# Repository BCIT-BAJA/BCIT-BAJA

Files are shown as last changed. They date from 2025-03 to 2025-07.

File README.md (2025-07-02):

# Problem 
During the last BAJA competition,The BAJA team was unable to measure dynamic forces applied onto the suspension of the car. As a result, during the last competition, it bent.
ezgif-3c4af8c38ad79b

The telemetry system for BCIT-BAJA car, collects strain across suspension components of car to allow BAJA to optimize material and reinforce weak areas of suspension.
As well as collect other data such as linear/angular acceleration.

There consists of 2 parts of this project. 

**PART B** the amplification of the (-15-15mV) analog strain signal to (0-3.0V) which is then routed to

**PART A**, which collects the 8 conditioned analog signals and is transmitted/received over a 900MHz antenna

# MAINBOARD( PART A)






# Amplifier circuit ( PART B) - 


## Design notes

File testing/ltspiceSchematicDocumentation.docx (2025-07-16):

# Power supply measurement

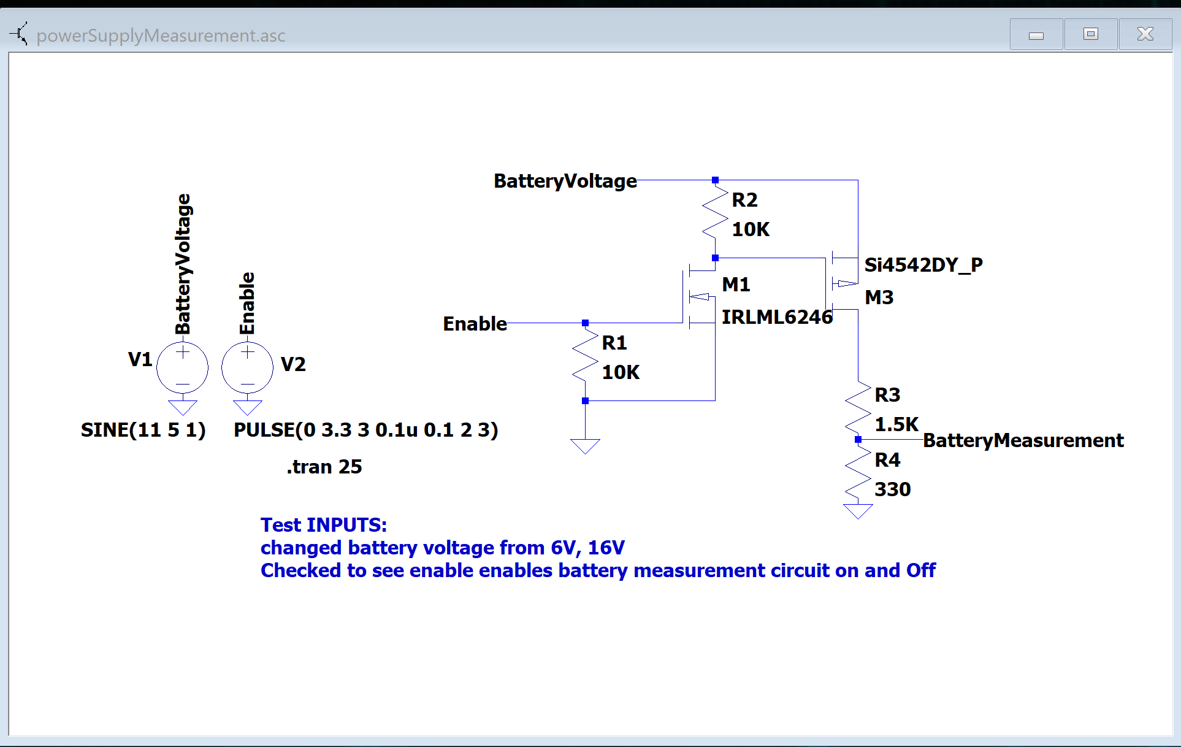
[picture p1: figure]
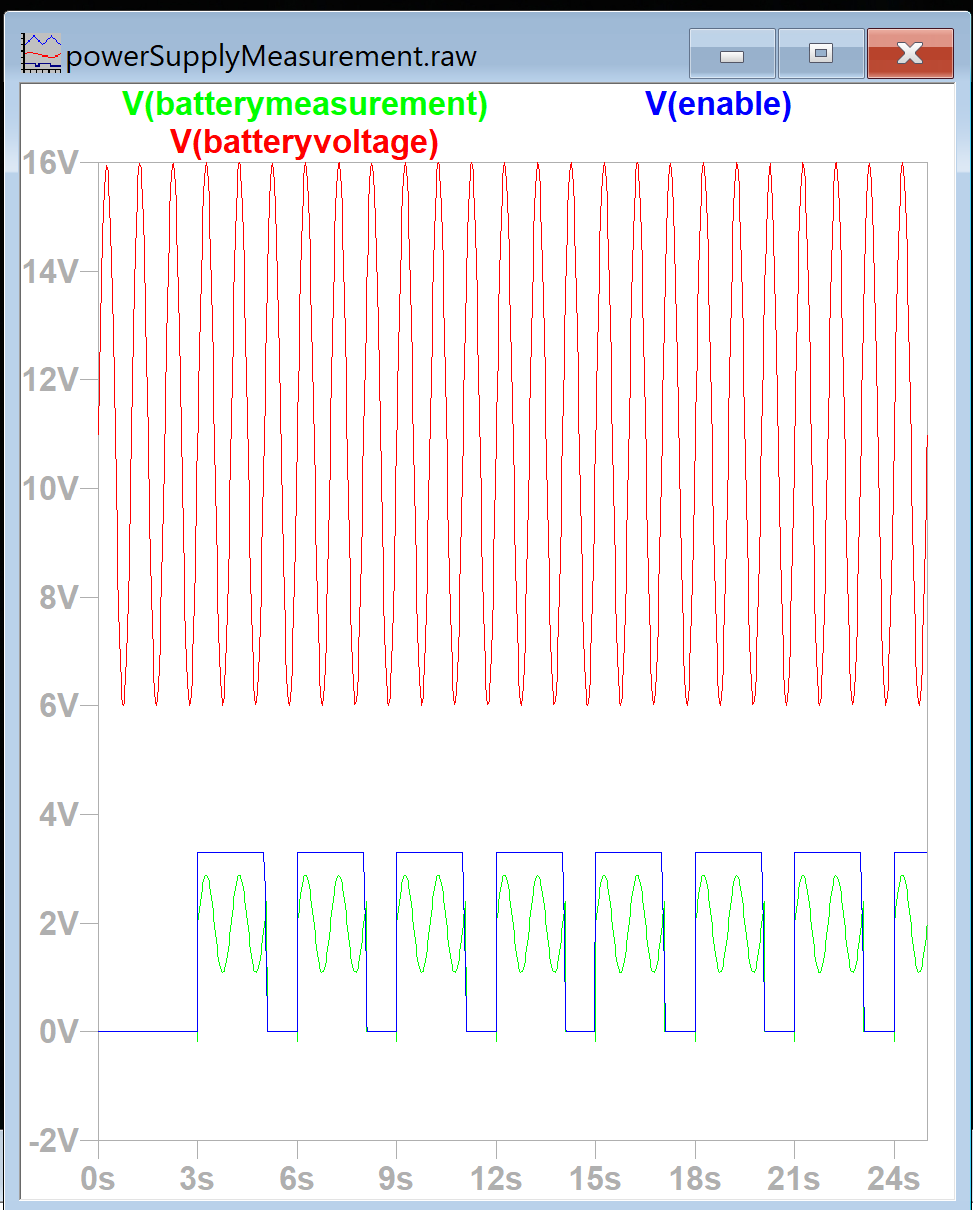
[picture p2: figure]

# StrainGAUGE switching – to be discussed about

HIGH C -> LOW EMI, HIGH CURRENT DRAW, DECREASES ACCURACY

CURRENT LIMITING RESISTER -> LOWERS CURRENT, DECREASES ACCURACY

NO C -> HIGHEST EMI, HIGHEST ACCURACY, lowest current draw.

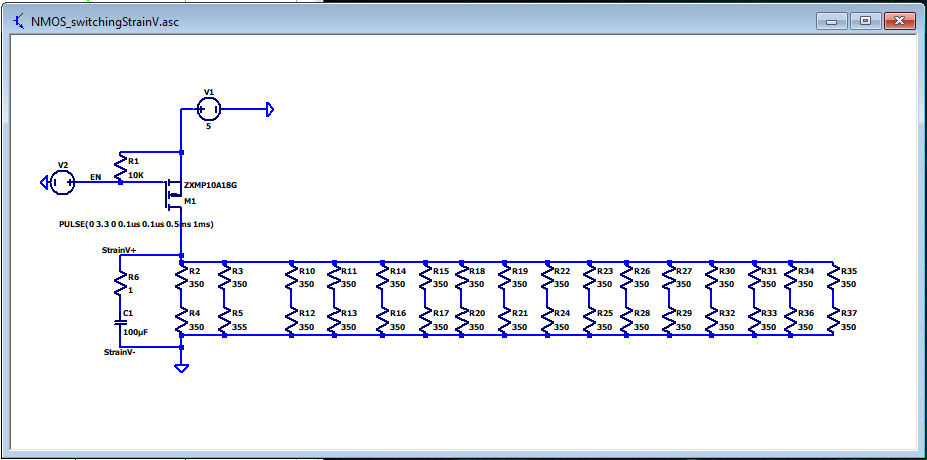
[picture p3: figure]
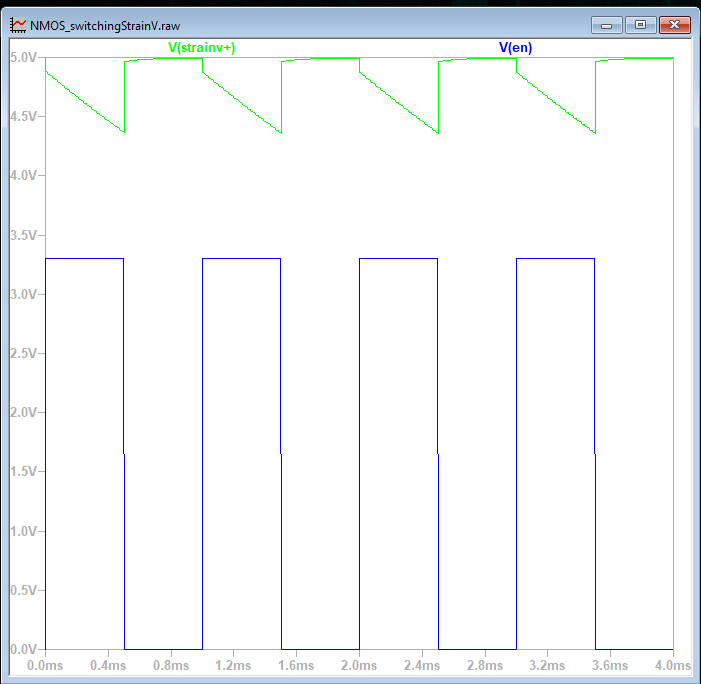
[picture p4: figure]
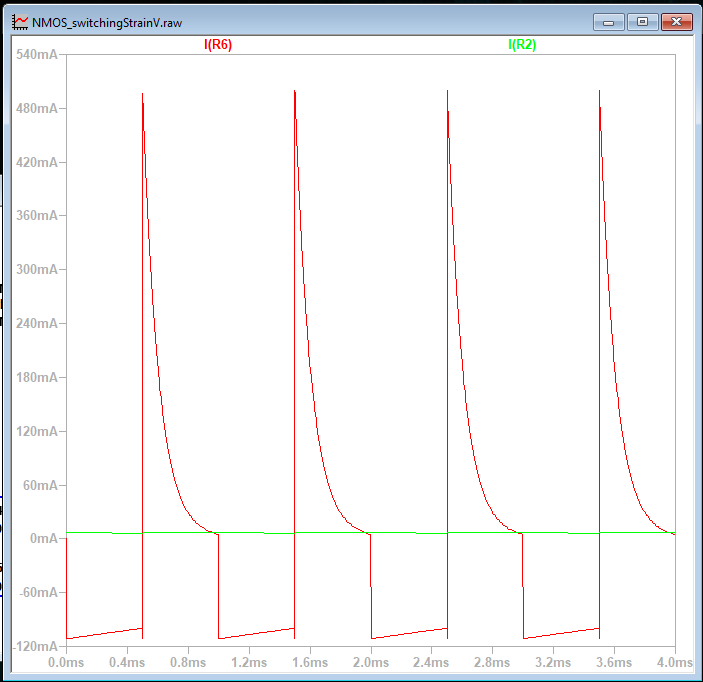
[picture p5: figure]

Figure 1 Current limiting resistor = 1 Ohm, bypass 100uF

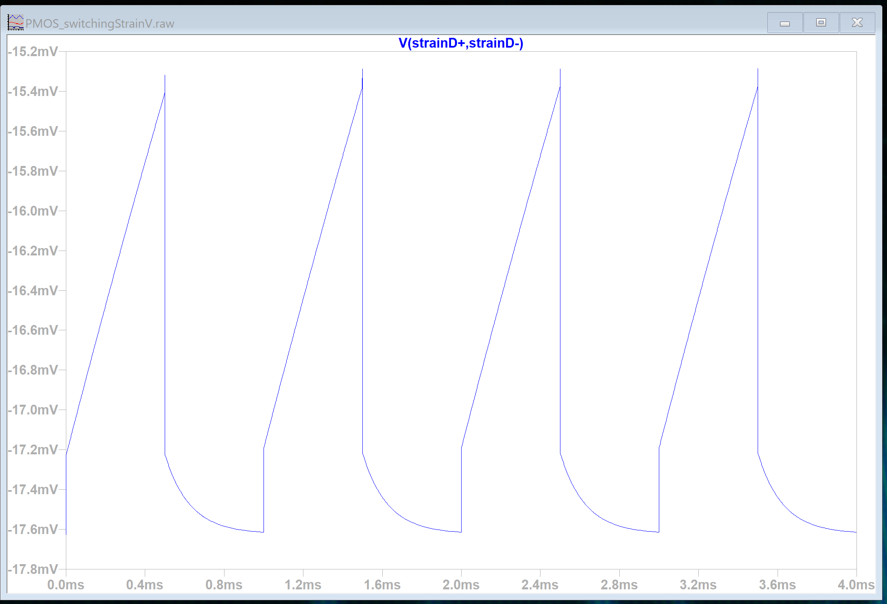
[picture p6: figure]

Figure 2 R =1, C=100uF

# Strain gauge Amplifier

Could not trigger undervoltage conditions on stimulation due to OP-AMP reaching saturation at about 500mV. The stimulated diodes are specced out for worst case condition. Triggering at -182mV, overall, the diodes still protect the ADC at worst-case scenario however could not be properly integrated into the stimulation.

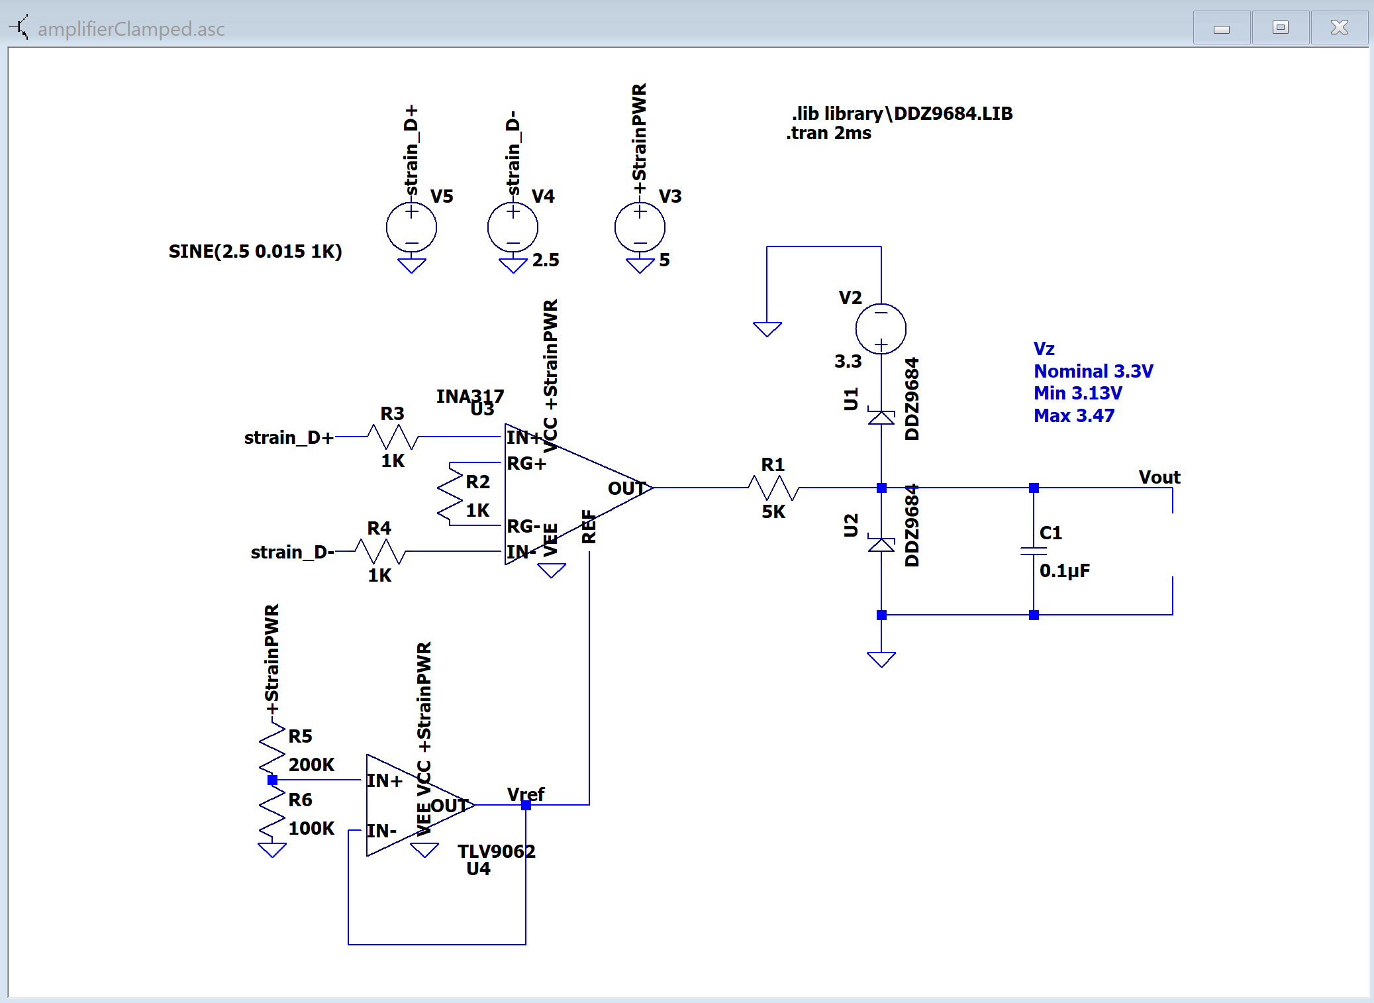
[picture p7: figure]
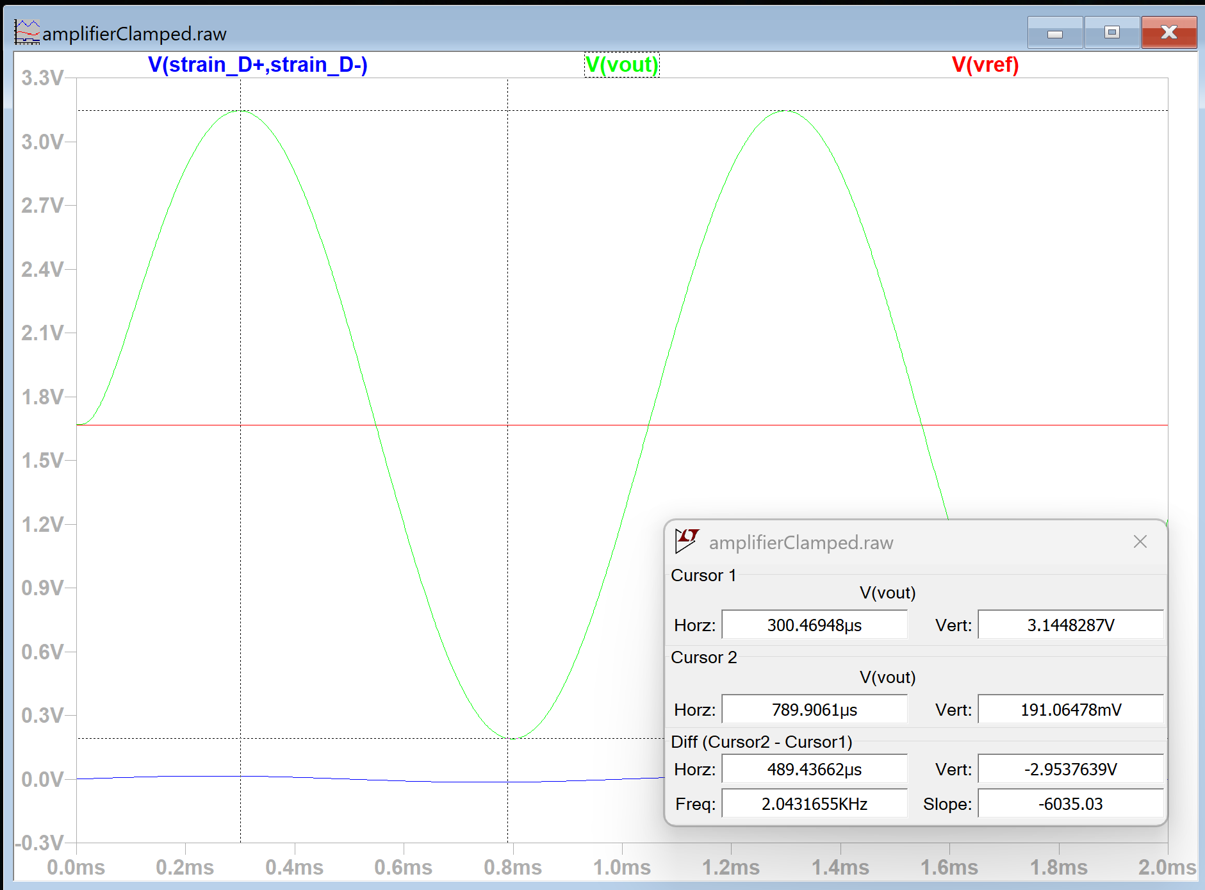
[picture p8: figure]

Diode clamping circuit (*Note, reverse voltage can vary quite a bit as seen by Vz on circuit)

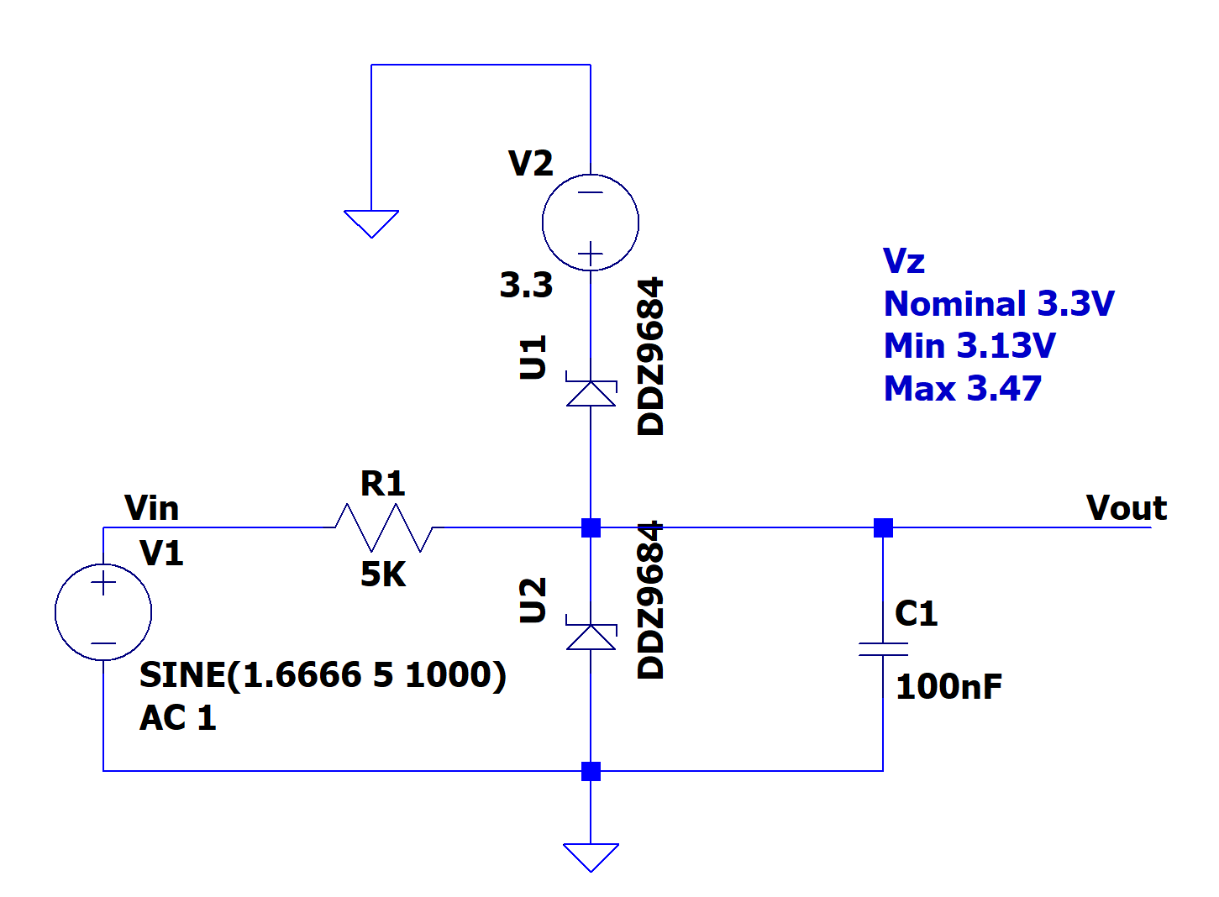
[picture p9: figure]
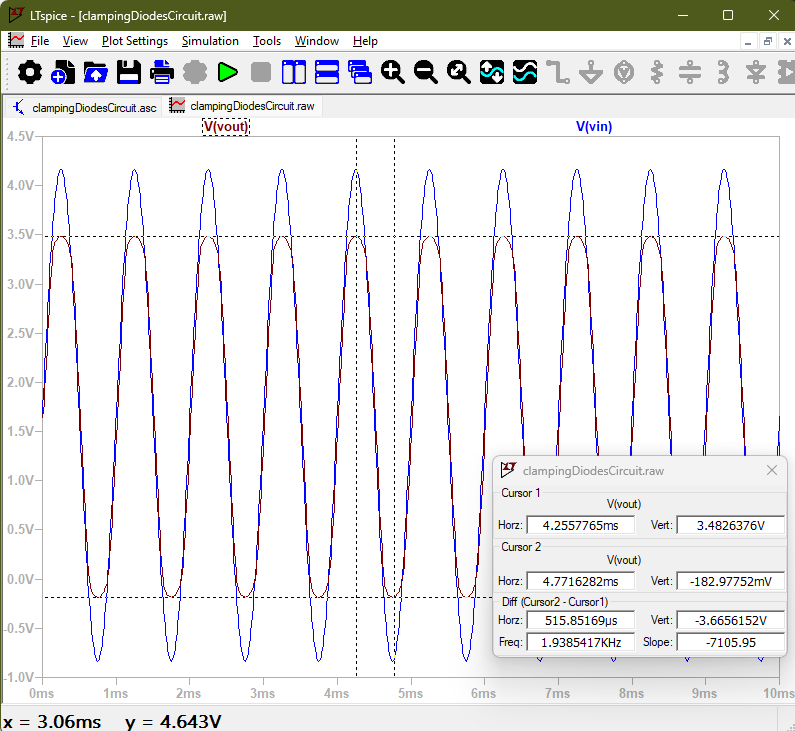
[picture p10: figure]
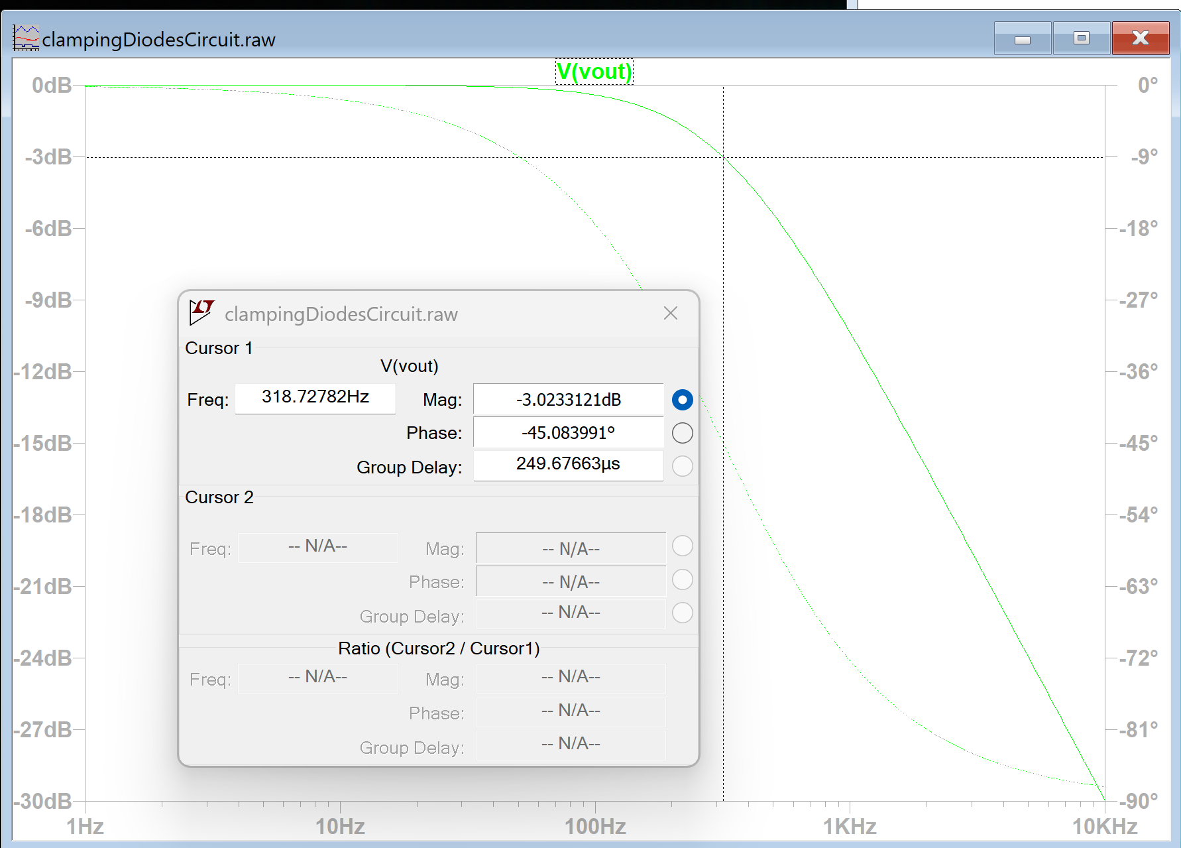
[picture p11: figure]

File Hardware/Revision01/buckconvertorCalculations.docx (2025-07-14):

Specifications

1. Verification of PINOUT

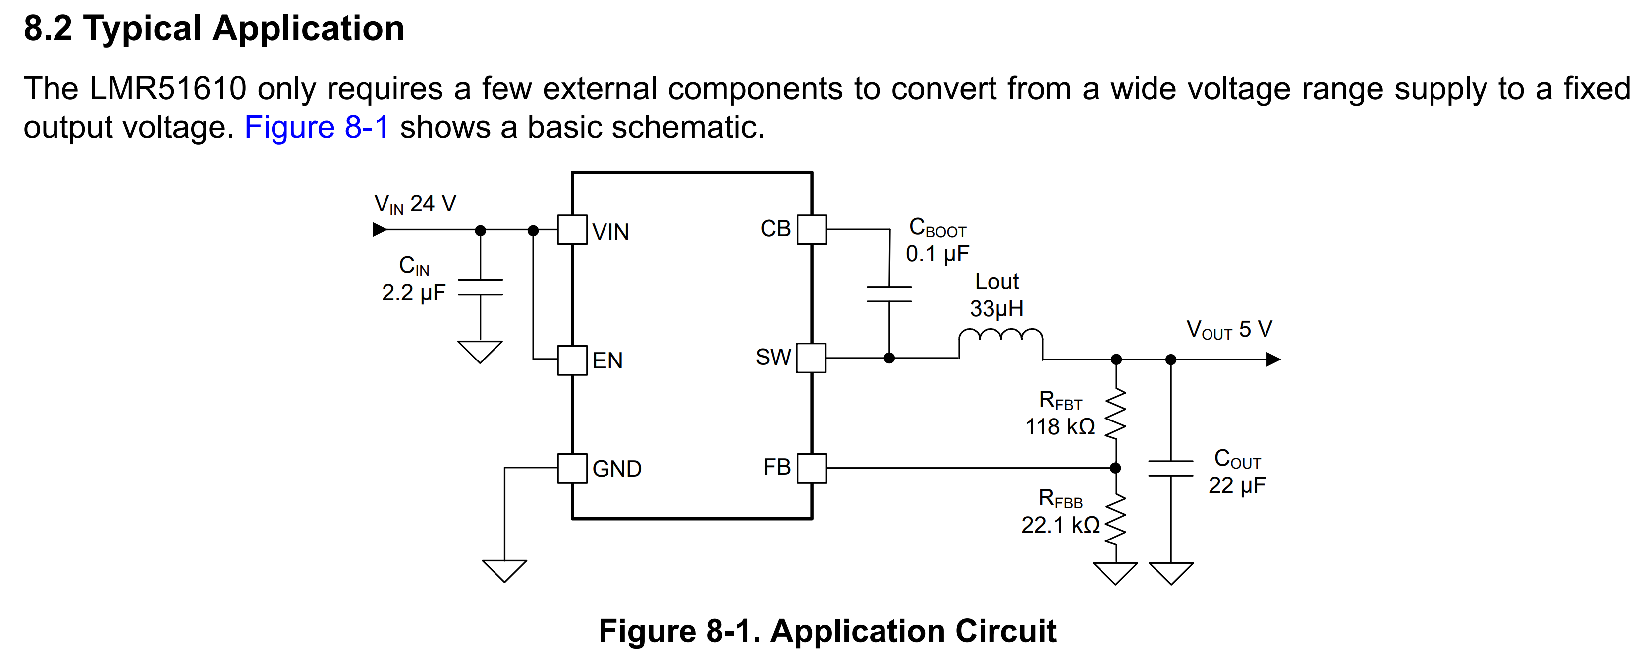
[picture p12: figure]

Design parameters

Parameter | Value
V_(in) | 4.5-16V - Not sure why (8.8V - 15.2V) is on schematic
V_(out) | 7V – must be above 6.5V
i_(out_max) | 250mA – (assuming MOSFET is not switched at 1KHz)
Output overshoot, undershoot | ±5%
Output voltage ripple | ±5%
Operating frequency | 400KHz

2. How do you set the output voltage? (PRIORITY HIGH)

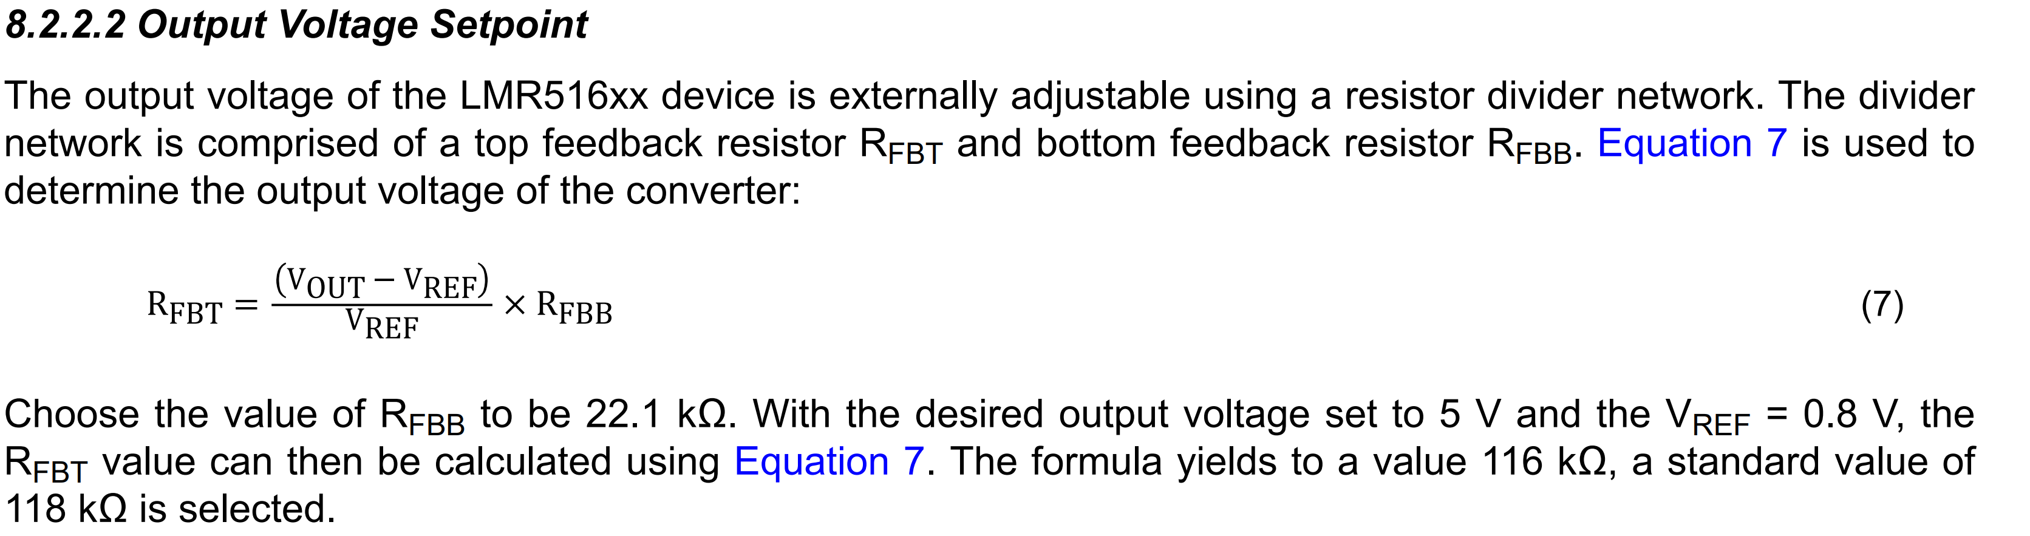
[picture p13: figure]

Defining variables

Choose V_(out) = 7V (Ensure V_(out) is above 6.5V for stable operation of LDO)

V_(ref) = 0.8V (Const)

R_(fbb) = 10K (Randomly chosen)

Plugging that into eq we get

R_(fbt) = (V_(out) - V_(ref) )*(R_(fbb))/(V_(ref))= 77.5K ~= 76.8K

3. How to choose output inductor (PRIORITY MEDIUM)

Overall, I chose parameters that limited EMI, at the cost of being less energy efficient.

K_(IND) is a coefficient that represents the amount of inductor ripple current relative to the maximum output current of the device. K_(IND) must be 0.2-0.6 of maximum IOUT supported by converter.

K_(chosen) = 0.2 – lowest EMI, least energy efficient

f_(sw) =400KHz - lower switching frequency variant chosen for less EMI

V_(in_max) =16V - not sure why 15.2V was chosen

V_(out) =7V±0.5V

I_(out_fla) ~=250mA

Plugging the old parameters in we get

Figure 1 Formula used for inductance

L_(min) =197μH

We chose L =150μH giving us K = 0.26

Now we can calculate the ripple across the input of the inductor using

Figure 2 ripple current(PG 19 datasheet)

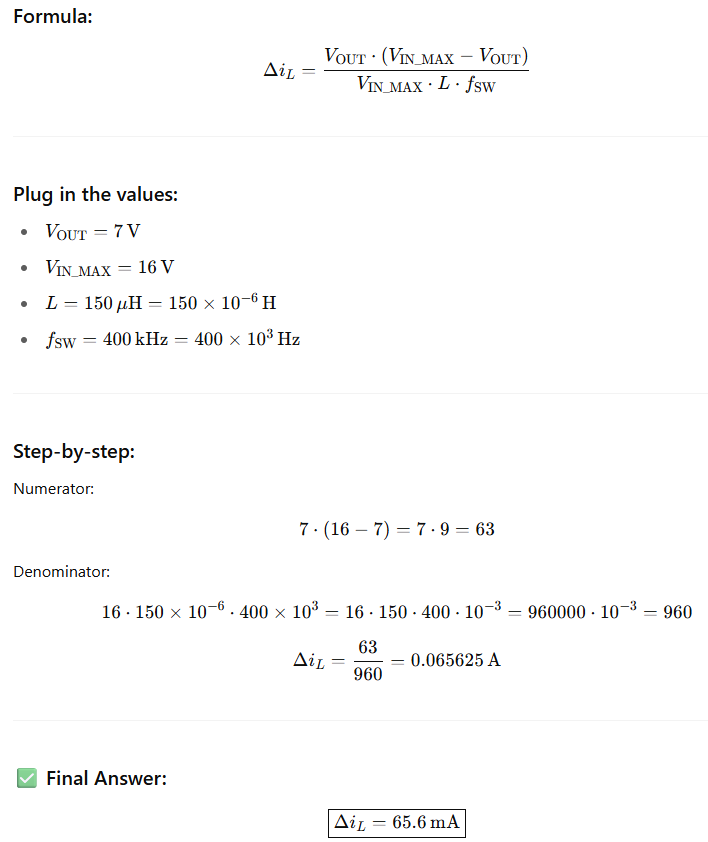
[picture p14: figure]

Note* This inductor has been routed away from analog signals to reduce EMI.

4. Choosing Input capacitors (PRIORITY: LOW)

Followed recommendation using 1uF

5. Choosing output capacitor( PRIORITY: LOWish)

Target ripple is 0.35V

ESR ~= 10m Ω @300KHz

ΔV_(out_esr) =0.66mV

ΔV_(out) _c = 0.93mV

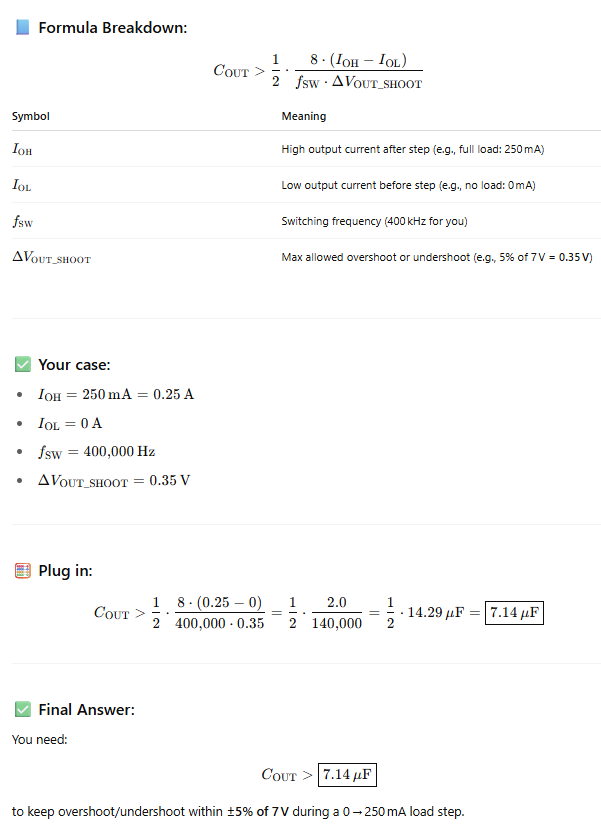
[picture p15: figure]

I will have 10uF + 1uF

This one may be better as all wiring has already been created.

Export TPS54202DDCR - 8.5V-16V to 7.00V @ 0.3A

https://webench.ti.com/power-designer/switching-regulator/select

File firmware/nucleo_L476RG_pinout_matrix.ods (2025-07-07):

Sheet: tabula-stm32l476rg(2)
AF15 | Pin | Additional Functions | AF0 | AF1 | AF2 | AF3 | AF4 | AF5 | AF6 | AF7 | AF8 | AF9 | AF10 | AF11 | AF12 | AF13 | AF14 | Pin | Additional Functions | AF0 | AF1 | AF2 | AF3 | AF4 | AF5 | AF6 | AF7 | AF8 | AF9 | AF10 | AF11 | AF12 | AF13 | AF14 | 0
EVENTOUT | PA0 | OPAMP1_VINP/ADC12_IN5/RTC_TAMP2/WKUP1 |  | TIM2_CH1 | TIM5_CH1 | TIM8_ETR |  |  |  | USART2_CTS | UART4_TX |  |  |  |  | SAI1_EXTCLK | TIM2_ETR | PA0 | PA0/OPAMP1_VINP/ADC12_IN5/RTC_TAMP2/WKUP1 | PA0/OPAMP1_VINP/ADC12_IN5/RTC_TAMP2/WKUP1 | PA0/OPAMP1_VINP/ADC12_IN5/RTC_TAMP2/WKUP1/TIM2_CH1 | PA0/OPAMP1_VINP/ADC12_IN5/RTC_TAMP2/WKUP1/TIM2_CH1/TIM5_CH1 | PA0/OPAMP1_VINP/ADC12_IN5/RTC_TAMP2/WKUP1/TIM2_CH1/TIM5_CH1/TIM8_ETR | PA0/OPAMP1_VINP/ADC12_IN5/RTC_TAMP2/WKUP1/TIM2_CH1/TIM5_CH1/TIM8_ETR | PA0/OPAMP1_VINP/ADC12_IN5/RTC_TAMP2/WKUP1/TIM2_CH1/TIM5_CH1/TIM8_ETR | PA0/OPAMP1_VINP/ADC12_IN5/RTC_TAMP2/WKUP1/TIM2_CH1/TIM5_CH1/TIM8_ETR | PA0/OPAMP1_VINP/ADC12_IN5/RTC_TAMP2/WKUP1/TIM2_CH1/TIM5_CH1/TIM8_ETR/USART2_CTS | PA0/OPAMP1_VINP/ADC12_IN5/RTC_TAMP2/WKUP1/TIM2_CH1/TIM5_CH1/TIM8_ETR/USART2_CTS/UART4_TX | PA0/OPAMP1_VINP/ADC12_IN5/RTC_TAMP2/WKUP1/TIM2_CH1/TIM5_CH1/TIM8_ETR/USART2_CTS/UART4_TX | PA0/OPAMP1_VINP/ADC12_IN5/RTC_TAMP2/WKUP1/TIM2_CH1/TIM5_CH1/TIM8_ETR/USART2_CTS/UART4_TX | PA0/OPAMP1_VINP/ADC12_IN5/RTC_TAMP2/WKUP1/TIM2_CH1/TIM5_CH1/TIM8_ETR/USART2_CTS/UART4_TX | PA0/OPAMP1_VINP/ADC12_IN5/RTC_TAMP2/WKUP1/TIM2_CH1/TIM5_CH1/TIM8_ETR/USART2_CTS/UART4_TX | PA0/OPAMP1_VINP/ADC12_IN5/RTC_TAMP2/WKUP1/TIM2_CH1/TIM5_CH1/TIM8_ETR/USART2_CTS/UART4_TX/SAI1_EXTCLK | PA0/OPAMP1_VINP/ADC12_IN5/RTC_TAMP2/WKUP1/TIM2_CH1/TIM5_CH1/TIM8_ETR/USART2_CTS/UART4_TX/SAI1_EXTCLK/TIM2_ETR | PA0/OPAMP1_VINP/ADC12_IN5/RTC_TAMP2/WKUP1/TIM2_CH1/TIM5_CH1/TIM8_ETR/USART2_CTS/UART4_TX/SAI1_EXTCLK/TIM2_ETR
EVENTOUT | PA1 | OPAMP1_VINM/ADC12_IN6 |  | TIM2_CH2 | TIM5_CH2 |  |  |  |  | USART2_RTS_DE | UART4_RX |  |  | LCD_SEG0 |  |  | TIM15_CH1N | PA1 | PA1/OPAMP1_VINM/ADC12_IN6 | PA1/OPAMP1_VINM/ADC12_IN6 | PA1/OPAMP1_VINM/ADC12_IN6/TIM2_CH2 | PA1/OPAMP1_VINM/ADC12_IN6/TIM2_CH2/TIM5_CH2 | PA1/OPAMP1_VINM/ADC12_IN6/TIM2_CH2/TIM5_CH2 | PA1/OPAMP1_VINM/ADC12_IN6/TIM2_CH2/TIM5_CH2 | PA1/OPAMP1_VINM/ADC12_IN6/TIM2_CH2/TIM5_CH2 | PA1/OPAMP1_VINM/ADC12_IN6/TIM2_CH2/TIM5_CH2 | PA1/OPAMP1_VINM/ADC12_IN6/TIM2_CH2/TIM5_CH2/USART2_RTS_DE | PA1/OPAMP1_VINM/ADC12_IN6/TIM2_CH2/TIM5_CH2/USART2_RTS_DE/UART4_RX | PA1/OPAMP1_VINM/ADC12_IN6/TIM2_CH2/TIM5_CH2/USART2_RTS_DE/UART4_RX | PA1/OPAMP1_VINM/ADC12_IN6/TIM2_CH2/TIM5_CH2/USART2_RTS_DE/UART4_RX | PA1/OPAMP1_VINM/ADC12_IN6/TIM2_CH2/TIM5_CH2/USART2_RTS_DE/UART4_RX/LCD_SEG0 | PA1/OPAMP1_VINM/ADC12_IN6/TIM2_CH2/TIM5_CH2/USART2_RTS_DE/UART4_RX/LCD_SEG0 | PA1/OPAMP1_VINM/ADC12_IN6/TIM2_CH2/TIM5_CH2/USART2_RTS_DE/UART4_RX/LCD_SEG0 | PA1/OPAMP1_VINM/ADC12_IN6/TIM2_CH2/TIM5_CH2/USART2_RTS_DE/UART4_RX/LCD_SEG0/TIM15_CH1N | PA1/OPAMP1_VINM/ADC12_IN6/TIM2_CH2/TIM5_CH2/USART2_RTS_DE/UART4_RX/LCD_SEG0/TIM15_CH1N
EVENTOUT | PA2 | ADC12_IN7/WKUP4/LSCO |  | TIM2_CH3 | TIM5_CH3 |  |  |  |  | USART2_TX |  |  |  | LCD_SEG1 |  | SAI2_EXTCLK | TIM15_CH1 | PA2 | PA2/ADC12_IN7/WKUP4/LSCO | PA2/ADC12_IN7/WKUP4/LSCO | PA2/ADC12_IN7/WKUP4/LSCO/TIM2_CH3 | PA2/ADC12_IN7/WKUP4/LSCO/TIM2_CH3/TIM5_CH3 | PA2/ADC12_IN7/WKUP4/LSCO/TIM2_CH3/TIM5_CH3 | PA2/ADC12_IN7/WKUP4/LSCO/TIM2_CH3/TIM5_CH3 | PA2/ADC12_IN7/WKUP4/LSCO/TIM2_CH3/TIM5_CH3 | PA2/ADC12_IN7/WKUP4/LSCO/TIM2_CH3/TIM5_CH3 | PA2/ADC12_IN7/WKUP4/LSCO/TIM2_CH3/TIM5_CH3/USART2_TX | PA2/ADC12_IN7/WKUP4/LSCO/TIM2_CH3/TIM5_CH3/USART2_TX | PA2/ADC12_IN7/WKUP4/LSCO/TIM2_CH3/TIM5_CH3/USART2_TX | PA2/ADC12_IN7/WKUP4/LSCO/TIM2_CH3/TIM5_CH3/USART2_TX | PA2/ADC12_IN7/WKUP4/LSCO/TIM2_CH3/TIM5_CH3/USART2_TX/LCD_SEG1 | PA2/ADC12_IN7/WKUP4/LSCO/TIM2_CH3/TIM5_CH3/USART2_TX/LCD_SEG1 | PA2/ADC12_IN7/WKUP4/LSCO/TIM2_CH3/TIM5_CH3/USART2_TX/LCD_SEG1/SAI2_EXTCLK | PA2/ADC12_IN7/WKUP4/LSCO/TIM2_CH3/TIM5_CH3/USART2_TX/LCD_SEG1/SAI2_EXTCLK/TIM15_CH1 | PA2/ADC12_IN7/WKUP4/LSCO/TIM2_CH3/TIM5_CH3/USART2_TX/LCD_SEG1/SAI2_EXTCLK/TIM15_CH1
EVENTOUT | PA3 | OPAMP1_VOUT/ADC12_IN8 |  | TIM2_CH4 | TIM5_CH4 |  |  |  |  | USART2_RX |  |  |  | LCD_SEG2 |  |  | TIM15_CH2 | PA3 | PA3/OPAMP1_VOUT/ADC12_IN8 | PA3/OPAMP1_VOUT/ADC12_IN8 | PA3/OPAMP1_VOUT/ADC12_IN8/TIM2_CH4 | PA3/OPAMP1_VOUT/ADC12_IN8/TIM2_CH4/TIM5_CH4 | PA3/OPAMP1_VOUT/ADC12_IN8/TIM2_CH4/TIM5_CH4 | PA3/OPAMP1_VOUT/ADC12_IN8/TIM2_CH4/TIM5_CH4 | PA3/OPAMP1_VOUT/ADC12_IN8/TIM2_CH4/TIM5_CH4 | PA3/OPAMP1_VOUT/ADC12_IN8/TIM2_CH4/TIM5_CH4 | PA3/OPAMP1_VOUT/ADC12_IN8/TIM2_CH4/TIM5_CH4/USART2_RX | PA3/OPAMP1_VOUT/ADC12_IN8/TIM2_CH4/TIM5_CH4/USART2_RX | PA3/OPAMP1_VOUT/ADC12_IN8/TIM2_CH4/TIM5_CH4/USART2_RX | PA3/OPAMP1_VOUT/ADC12_IN8/TIM2_CH4/TIM5_CH4/USART2_RX | PA3/OPAMP1_VOUT/ADC12_IN8/TIM2_CH4/TIM5_CH4/USART2_RX/LCD_SEG2 | PA3/OPAMP1_VOUT/ADC12_IN8/TIM2_CH4/TIM5_CH4/USART2_RX/LCD_SEG2 | PA3/OPAMP1_VOUT/ADC12_IN8/TIM2_CH4/TIM5_CH4/USART2_RX/LCD_SEG2 | PA3/OPAMP1_VOUT/ADC12_IN8/TIM2_CH4/TIM5_CH4/USART2_RX/LCD_SEG2/TIM15_CH2 | PA3/OPAMP1_VOUT/ADC12_IN8/TIM2_CH4/TIM5_CH4/USART2_RX/LCD_SEG2/TIM15_CH2
EVENTOUT | PA4 | ADC12_IN9/DAC1_OUT1 |  |  |  |  |  | SPI1_NSS | SPI3_NSS | USART2_CK |  |  |  |  |  | SAI1_FS_B | LPTIM2_OUT | PA4 | PA4/ADC12_IN9/DAC1_OUT1 | PA4/ADC12_IN9/DAC1_OUT1 | PA4/ADC12_IN9/DAC1_OUT1 | PA4/ADC12_IN9/DAC1_OUT1 | PA4/ADC12_IN9/DAC1_OUT1 | PA4/ADC12_IN9/DAC1_OUT1 | PA4/ADC12_IN9/DAC1_OUT1/SPI1_NSS | PA4/ADC12_IN9/DAC1_OUT1/SPI1_NSS/SPI3_NSS | PA4/ADC12_IN9/DAC1_OUT1/SPI1_NSS/SPI3_NSS/USART2_CK | PA4/ADC12_IN9/DAC1_OUT1/SPI1_NSS/SPI3_NSS/USART2_CK | PA4/ADC12_IN9/DAC1_OUT1/SPI1_NSS/SPI3_NSS/USART2_CK | PA4/ADC12_IN9/DAC1_OUT1/SPI1_NSS/SPI3_NSS/USART2_CK | PA4/ADC12_IN9/DAC1_OUT1/SPI1_NSS/SPI3_NSS/USART2_CK | PA4/ADC12_IN9/DAC1_OUT1/SPI1_NSS/SPI3_NSS/USART2_CK | PA4/ADC12_IN9/DAC1_OUT1/SPI1_NSS/SPI3_NSS/USART2_CK/SAI1_FS_B | PA4/ADC12_IN9/DAC1_OUT1/SPI1_NSS/SPI3_NSS/USART2_CK/SAI1_FS_B/LPTIM2_OUT | PA4/ADC12_IN9/DAC1_OUT1/SPI1_NSS/SPI3_NSS/USART2_CK/SAI1_FS_B/LPTIM2_OUT
EVENTOUT | PA5 | ADC12_IN10/DAC1_OUT2 |  | TIM2_CH1 | TIM2_ETR | TIM8_CH1N |  | SPI1_SCK |  |  |  |  |  |  |  |  | LPTIM2_ETR | PA5 | PA5/ADC12_IN10/DAC1_OUT2 | PA5/ADC12_IN10/DAC1_OUT2 | PA5/ADC12_IN10/DAC1_OUT2/TIM2_CH1 | PA5/ADC12_IN10/DAC1_OUT2/TIM2_CH1/TIM2_ETR | PA5/ADC12_IN10/DAC1_OUT2/TIM2_CH1/TIM2_ETR/TIM8_CH1N | PA5/ADC12_IN10/DAC1_OUT2/TIM2_CH1/TIM2_ETR/TIM8_CH1N | PA5/ADC12_IN10/DAC1_OUT2/TIM2_CH1/TIM2_ETR/TIM8_CH1N/SPI1_SCK | PA5/ADC12_IN10/DAC1_OUT2/TIM2_CH1/TIM2_ETR/TIM8_CH1N/SPI1_SCK | PA5/ADC12_IN10/DAC1_OUT2/TIM2_CH1/TIM2_ETR/TIM8_CH1N/SPI1_SCK | PA5/ADC12_IN10/DAC1_OUT2/TIM2_CH1/TIM2_ETR/TIM8_CH1N/SPI1_SCK | PA5/ADC12_IN10/DAC1_OUT2/TIM2_CH1/TIM2_ETR/TIM8_CH1N/SPI1_SCK | PA5/ADC12_IN10/DAC1_OUT2/TIM2_CH1/TIM2_ETR/TIM8_CH1N/SPI1_SCK | PA5/ADC12_IN10/DAC1_OUT2/TIM2_CH1/TIM2_ETR/TIM8_CH1N/SPI1_SCK | PA5/ADC12_IN10/DAC1_OUT2/TIM2_CH1/TIM2_ETR/TIM8_CH1N/SPI1_SCK | PA5/ADC12_IN10/DAC1_OUT2/TIM2_CH1/TIM2_ETR/TIM8_CH1N/SPI1_SCK | PA5/ADC12_IN10/DAC1_OUT2/TIM2_CH1/TIM2_ETR/TIM8_CH1N/SPI1_SCK/LPTIM2_ETR | PA5/ADC12_IN10/DAC1_OUT2/TIM2_CH1/TIM2_ETR/TIM8_CH1N/SPI1_SCK/LPTIM2_ETR
EVENTOUT | PA6 | OPAMP2_VINP/ADC12_IN11 |  | TIM1_BKIN | TIM3_CH1 | TIM8_BKIN |  | SPI1_MISO |  | USART3_CTS |  |  | QUADSPI_BK1_IO3 | LCD_SEG3 | TIM1_BKIN_COMP2 | TIM8_BKIN_COMP2 | TIM16_CH1 | PA6 | PA6/OPAMP2_VINP/ADC12_IN11 | PA6/OPAMP2_VINP/ADC12_IN11 | PA6/OPAMP2_VINP/ADC12_IN11/TIM1_BKIN | PA6/OPAMP2_VINP/ADC12_IN11/TIM1_BKIN/TIM3_CH1 | PA6/OPAMP2_VINP/ADC12_IN11/TIM1_BKIN/TIM3_CH1/TIM8_BKIN | PA6/OPAMP2_VINP/ADC12_IN11/TIM1_BKIN/TIM3_CH1/TIM8_BKIN | PA6/OPAMP2_VINP/ADC12_IN11/TIM1_BKIN/TIM3_CH1/TIM8_BKIN/SPI1_MISO | PA6/OPAMP2_VINP/ADC12_IN11/TIM1_BKIN/TIM3_CH1/TIM8_BKIN/SPI1_MISO | PA6/OPAMP2_VINP/ADC12_IN11/TIM1_BKIN/TIM3_CH1/TIM8_BKIN/SPI1_MISO/USART3_CTS | PA6/OPAMP2_VINP/ADC12_IN11/TIM1_BKIN/TIM3_CH1/TIM8_BKIN/SPI1_MISO/USART3_CTS | PA6/OPAMP2_VINP/ADC12_IN11/TIM1_BKIN/TIM3_CH1/TIM8_BKIN/SPI1_MISO/USART3_CTS | PA6/OPAMP2_VINP/ADC12_IN11/TIM1_BKIN/TIM3_CH1/TIM8_BKIN/SPI1_MISO/USART3_CTS/QUADSPI_BK1_IO3 | PA6/OPAMP2_VINP/ADC12_IN11/TIM1_BKIN/TIM3_CH1/TIM8_BKIN/SPI1_MISO/USART3_CTS/QUADSPI_BK1_IO3/LCD_SEG3 | PA6/OPAMP2_VINP/ADC12_IN11/TIM1_BKIN/TIM3_CH1/TIM8_BKIN/SPI1_MISO/USART3_CTS/QUADSPI_BK1_IO3/LCD_SEG3/TIM1_BKIN_COMP2 | PA6/OPAMP2_VINP/ADC12_IN11/TIM1_BKIN/TIM3_CH1/TIM8_BKIN/SPI1_MISO/USART3_CTS/QUADSPI_BK1_IO3/LCD_SEG3/TIM1_BKIN_COMP2/TIM8_BKIN_COMP2 | PA6/OPAMP2_VINP/ADC12_IN11/TIM1_BKIN/TIM3_CH1/TIM8_BKIN/SPI1_MISO/USART3_CTS/QUADSPI_BK1_IO3/LCD_SEG3/TIM1_BKIN_COMP2/TIM8_BKIN_COMP2/TIM16_CH1 | PA6/OPAMP2_VINP/ADC12_IN11/TIM1_BKIN/TIM3_CH1/TIM8_BKIN/SPI1_MISO/USART3_CTS/QUADSPI_BK1_IO3/LCD_SEG3/TIM1_BKIN_COMP2/TIM8_BKIN_COMP2/TIM16_CH1
EVENTOUT | PA7 | OPAMP2_VINM/ADC12_IN12 |  | TIM1_CH1N | TIM3_CH2 | TIM8_CH1N |  | SPI1_MOSI |  |  |  |  | QUADSPI_BK1_IO2 | LCD_SEG4 |  |  | TIM17_CH1 | PA7 | PA7/OPAMP2_VINM/ADC12_IN12 | PA7/OPAMP2_VINM/ADC12_IN12 | PA7/OPAMP2_VINM/ADC12_IN12/TIM1_CH1N | PA7/OPAMP2_VINM/ADC12_IN12/TIM1_CH1N/TIM3_CH2 | PA7/OPAMP2_VINM/ADC12_IN12/TIM1_CH1N/TIM3_CH2/TIM8_CH1N | PA7/OPAMP2_VINM/ADC12_IN12/TIM1_CH1N/TIM3_CH2/TIM8_CH1N | PA7/OPAMP2_VINM/ADC12_IN12/TIM1_CH1N/TIM3_CH2/TIM8_CH1N/SPI1_MOSI | PA7/OPAMP2_VINM/ADC12_IN12/TIM1_CH1N/TIM3_CH2/TIM8_CH1N/SPI1_MOSI | PA7/OPAMP2_VINM/ADC12_IN12/TIM1_CH1N/TIM3_CH2/TIM8_CH1N/SPI1_MOSI | PA7/OPAMP2_VINM/ADC12_IN12/TIM1_CH1N/TIM3_CH2/TIM8_CH1N/SPI1_MOSI | PA7/OPAMP2_VINM/ADC12_IN12/TIM1_CH1N/TIM3_CH2/TIM8_CH1N/SPI1_MOSI | PA7/OPAMP2_VINM/ADC12_IN12/TIM1_CH1N/TIM3_CH2/TIM8_CH1N/SPI1_MOSI/QUADSPI_BK1_IO2 | PA7/OPAMP2_VINM/ADC12_IN12/TIM1_CH1N/TIM3_CH2/TIM8_CH1N/SPI1_MOSI/QUADSPI_BK1_IO2/LCD_SEG4 | PA7/OPAMP2_VINM/ADC12_IN12/TIM1_CH1N/TIM3_CH2/TIM8_CH1N/SPI1_MOSI/QUADSPI_BK1_IO2/LCD_SEG4 | PA7/OPAMP2_VINM/ADC12_IN12/TIM1_CH1N/TIM3_CH2/TIM8_CH1N/SPI1_MOSI/QUADSPI_BK1_IO2/LCD_SEG4 | PA7/OPAMP2_VINM/ADC12_IN12/TIM1_CH1N/TIM3_CH2/TIM8_CH1N/SPI1_MOSI/QUADSPI_BK1_IO2/LCD_SEG4/TIM17_CH1 | PA7/OPAMP2_VINM/ADC12_IN12/TIM1_CH1N/TIM3_CH2/TIM8_CH1N/SPI1_MOSI/QUADSPI_BK1_IO2/LCD_SEG4/TIM17_CH1
EVENTOUT | PA8 |  | MCO | TIM1_CH1 |  |  |  |  |  | USART1_CK |  |  | OTG_FS_SOF | LCD_COM0 |  |  | LPTIM2_OUT | PA8 | PA8 | PA8/MCO | PA8/MCO/TIM1_CH1 | PA8/MCO/TIM1_CH1 | PA8/MCO/TIM1_CH1 | PA8/MCO/TIM1_CH1 | PA8/MCO/TIM1_CH1 | PA8/MCO/TIM1_CH1 | PA8/MCO/TIM1_CH1/USART1_CK | PA8/MCO/TIM1_CH1/USART1_CK | PA8/MCO/TIM1_CH1/USART1_CK | PA8/MCO/TIM1_CH1/USART1_CK/OTG_FS_SOF | PA8/MCO/TIM1_CH1/USART1_CK/OTG_FS_SOF/LCD_COM0 | PA8/MCO/TIM1_CH1/USART1_CK/OTG_FS_SOF/LCD_COM0 | PA8/MCO/TIM1_CH1/USART1_CK/OTG_FS_SOF/LCD_COM0 | PA8/MCO/TIM1_CH1/USART1_CK/OTG_FS_SOF/LCD_COM0/LPTIM2_OUT | PA8/MCO/TIM1_CH1/USART1_CK/OTG_FS_SOF/LCD_COM0/LPTIM2_OUT
EVENTOUT | PA9 | OTG_FS_VBUS |  | TIM1_CH2 |  |  |  |  |  | USART1_TX |  |  |  | LCD_COM1 |  |  | TIM15_BKIN | PA9 | PA9/OTG_FS_VBUS | PA9/OTG_FS_VBUS | PA9/OTG_FS_VBUS/TIM1_CH2 | PA9/OTG_FS_VBUS/TIM1_CH2 | PA9/OTG_FS_VBUS/TIM1_CH2 | PA9/OTG_FS_VBUS/TIM1_CH2 | PA9/OTG_FS_VBUS/TIM1_CH2 | PA9/OTG_FS_VBUS/TIM1_CH2 | PA9/OTG_FS_VBUS/TIM1_CH2/USART1_TX | PA9/OTG_FS_VBUS/TIM1_CH2/USART1_TX | PA9/OTG_FS_VBUS/TIM1_CH2/USART1_TX | PA9/OTG_FS_VBUS/TIM1_CH2/USART1_TX | PA9/OTG_FS_VBUS/TIM1_CH2/USART1_TX/LCD_COM1 | PA9/OTG_FS_VBUS/TIM1_CH2/USART1_TX/LCD_COM1 | PA9/OTG_FS_VBUS/TIM1_CH2/USART1_TX/LCD_COM1 | PA9/OTG_FS_VBUS/TIM1_CH2/USART1_TX/LCD_COM1/TIM15_BKIN | PA9/OTG_FS_VBUS/TIM1_CH2/USART1_TX/LCD_COM1/TIM15_BKIN
EVENTOUT | PA10 |  |  | TIM1_CH3 |  |  |  |  |  | USART1_RX |  |  | OTG_FS_ID | LCD_COM2 |  |  | TIM17_BKIN | PA10 | PA10 | PA10 | PA10/TIM1_CH3 | PA10/TIM1_CH3 | PA10/TIM1_CH3 | PA10/TIM1_CH3 | PA10/TIM1_CH3 | PA10/TIM1_CH3 | PA10/TIM1_CH3/USART1_RX | PA10/TIM1_CH3/USART1_RX | PA10/TIM1_CH3/USART1_RX | PA10/TIM1_CH3/USART1_RX/OTG_FS_ID | PA10/TIM1_CH3/USART1_RX/OTG_FS_ID/LCD_COM2 | PA10/TIM1_CH3/USART1_RX/OTG_FS_ID/LCD_COM2 | PA10/TIM1_CH3/USART1_RX/OTG_FS_ID/LCD_COM2 | PA10/TIM1_CH3/USART1_RX/OTG_FS_ID/LCD_COM2/TIM17_BKIN | PA10/TIM1_CH3/USART1_RX/OTG_FS_ID/LCD_COM2/TIM17_BKIN
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

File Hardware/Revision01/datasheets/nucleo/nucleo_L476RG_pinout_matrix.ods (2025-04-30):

Pin |  |  |  |  |  |  |  |  | Additional Functions
PA0 |  | TIM2_CH1 | TIM5_CH1 | TIM8_ETR |  |  |  | USART2_CTS | OPAMP1_VINP/ADC12_IN5/RTC_TAMP2/WKUP1 | PA0 | PA0 | PA0/TIM2_CH1 | PA0/TIM2_CH1/TIM5_CH1 | PA0/TIM2_CH1/TIM5_CH1/TIM8_ETR | PA0/TIM2_CH1/TIM5_CH1/TIM8_ETR | PA0/TIM2_CH1/TIM5_CH1/TIM8_ETR | PA0/TIM2_CH1/TIM5_CH1/TIM8_ETR | PA0/TIM2_CH1/TIM5_CH1/TIM8_ETR/USART2_CTS | PA0/TIM2_CH1/TIM5_CH1/TIM8_ETR/USART2_CTS/OPAMP1_VINP/ADC12_IN5/RTC_TAMP2/WKUP1
PA1 |  | TIM2_CH2 | TIM5_CH2 |  |  |  |  | USART2_RTS_DE | OPAMP1_VINM/ADC12_IN6 | PA1 | PA1 | PA1/TIM2_CH2 | PA1/TIM2_CH2/TIM5_CH2 | PA1/TIM2_CH2/TIM5_CH2 | PA1/TIM2_CH2/TIM5_CH2 | PA1/TIM2_CH2/TIM5_CH2 | PA1/TIM2_CH2/TIM5_CH2 | PA1/TIM2_CH2/TIM5_CH2/USART2_RTS_DE | PA1/TIM2_CH2/TIM5_CH2/USART2_RTS_DE/OPAMP1_VINM/ADC12_IN6
PA2 |  | TIM2_CH3 | TIM5_CH3 |  |  |  |  | USART2_TX | ADC12_IN7/WKUP4/LSCO | PA2 | PA2 | PA2/TIM2_CH3 | PA2/TIM2_CH3/TIM5_CH3 | PA2/TIM2_CH3/TIM5_CH3 | PA2/TIM2_CH3/TIM5_CH3 | PA2/TIM2_CH3/TIM5_CH3 | PA2/TIM2_CH3/TIM5_CH3 | PA2/TIM2_CH3/TIM5_CH3/USART2_TX | PA2/TIM2_CH3/TIM5_CH3/USART2_TX/ADC12_IN7/WKUP4/LSCO
PA3 |  | TIM2_CH4 | TIM5_CH4 |  |  |  |  | USART2_RX | OPAMP1_VOUT/ADC12_IN8 | PA3 | PA3 | PA3/TIM2_CH4 | PA3/TIM2_CH4/TIM5_CH4 | PA3/TIM2_CH4/TIM5_CH4 | PA3/TIM2_CH4/TIM5_CH4 | PA3/TIM2_CH4/TIM5_CH4 | PA3/TIM2_CH4/TIM5_CH4 | PA3/TIM2_CH4/TIM5_CH4/USART2_RX | PA3/TIM2_CH4/TIM5_CH4/USART2_RX/OPAMP1_VOUT/ADC12_IN8
PA4 |  |  |  |  |  | SPI1_NSS | SPI3_NSS | USART2_CK | ADC12_IN9/DAC1_OUT1 | PA4 | PA4 | PA4 | PA4 | PA4 | PA4 | PA4/SPI1_NSS | PA4/SPI1_NSS/SPI3_NSS | PA4/SPI1_NSS/SPI3_NSS/USART2_CK | PA4/SPI1_NSS/SPI3_NSS/USART2_CK/ADC12_IN9/DAC1_OUT1
PA5 |  | TIM2_CH1 | TIM2_ETR | TIM8_CH1N |  | SPI1_SCK |  |  | ADC12_IN10/DAC1_OUT2 | PA5 | PA5 | PA5/TIM2_CH1 | PA5/TIM2_CH1/TIM2_ETR | PA5/TIM2_CH1/TIM2_ETR/TIM8_CH1N | PA5/TIM2_CH1/TIM2_ETR/TIM8_CH1N | PA5/TIM2_CH1/TIM2_ETR/TIM8_CH1N/SPI1_SCK | PA5/TIM2_CH1/TIM2_ETR/TIM8_CH1N/SPI1_SCK | PA5/TIM2_CH1/TIM2_ETR/TIM8_CH1N/SPI1_SCK | PA5/TIM2_CH1/TIM2_ETR/TIM8_CH1N/SPI1_SCK/ADC12_IN10/DAC1_OUT2
PA6 |  | TIM1_BKIN | TIM3_CH1 | TIM8_BKIN |  | SPI1_MISO |  | USART3_CTS | OPAMP2_VINP/ADC12_IN11 | PA6 | PA6 | PA6/TIM1_BKIN | PA6/TIM1_BKIN/TIM3_CH1 | PA6/TIM1_BKIN/TIM3_CH1/TIM8_BKIN | PA6/TIM1_BKIN/TIM3_CH1/TIM8_BKIN | PA6/TIM1_BKIN/TIM3_CH1/TIM8_BKIN/SPI1_MISO | PA6/TIM1_BKIN/TIM3_CH1/TIM8_BKIN/SPI1_MISO | PA6/TIM1_BKIN/TIM3_CH1/TIM8_BKIN/SPI1_MISO/USART3_CTS | PA6/TIM1_BKIN/TIM3_CH1/TIM8_BKIN/SPI1_MISO/USART3_CTS/OPAMP2_VINP/ADC12_IN11
PA7 |  | TIM1_CH1N | TIM3_CH2 | TIM8_CH1N |  | SPI1_MOSI |  |  | OPAMP2_VINM/ADC12_IN12 | PA7 | PA7 | PA7/TIM1_CH1N | PA7/TIM1_CH1N/TIM3_CH2 | PA7/TIM1_CH1N/TIM3_CH2/TIM8_CH1N | PA7/TIM1_CH1N/TIM3_CH2/TIM8_CH1N | PA7/TIM1_CH1N/TIM3_CH2/TIM8_CH1N/SPI1_MOSI | PA7/TIM1_CH1N/TIM3_CH2/TIM8_CH1N/SPI1_MOSI | PA7/TIM1_CH1N/TIM3_CH2/TIM8_CH1N/SPI1_MOSI | PA7/TIM1_CH1N/TIM3_CH2/TIM8_CH1N/SPI1_MOSI/OPAMP2_VINM/ADC12_IN12
PA8 | MCO | TIM1_CH1 |  |  |  |  |  | USART1_CK |  | PA8 | PA8/MCO | PA8/MCO/TIM1_CH1 | PA8/MCO/TIM1_CH1 | PA8/MCO/TIM1_CH1 | PA8/MCO/TIM1_CH1 | PA8/MCO/TIM1_CH1 | PA8/MCO/TIM1_CH1 | PA8/MCO/TIM1_CH1/USART1_CK | PA8/MCO/TIM1_CH1/USART1_CK
PA9 |  | TIM1_CH2 |  |  |  |  |  | USART1_TX | OTG_FS_VBUS | PA9 | PA9 | PA9/TIM1_CH2 | PA9/TIM1_CH2 | PA9/TIM1_CH2 | PA9/TIM1_CH2 | PA9/TIM1_CH2 | PA9/TIM1_CH2 | PA9/TIM1_CH2/USART1_TX | PA9/TIM1_CH2/USART1_TX/OTG_FS_VBUS
PA10 |  | TIM1_CH3 |  |  |  |  |  | USART1_RX |  | PA10 | PA10 | PA10/TIM1_CH3 | PA10/TIM1_CH3 | PA10/TIM1_CH3 | PA10/TIM1_CH3 | PA10/TIM1_CH3 | PA10/TIM1_CH3 | PA10/TIM1_CH3/USART1_RX | PA10/TIM1_CH3/USART1_RX
PA11 |  | TIM1_CH4 | TIM1_BKIN2 |  |  |  |  | USART1_CTS |  | PA11 | PA11 | PA11/TIM1_CH4 | PA11/TIM1_CH4/TIM1_BKIN2 | PA11/TIM1_CH4/TIM1_BKIN2 | PA11/TIM1_CH4/TIM1_BKIN2 | PA11/TIM1_CH4/TIM1_BKIN2 | PA11/TIM1_CH4/TIM1_BKIN2 | PA11/TIM1_CH4/TIM1_BKIN2/USART1_CTS | PA11/TIM1_CH4/TIM1_BKIN2/USART1_CTS
PA12 |  | TIM1_ETR |  |  |  |  |  | USART1_RTS_DE |  | PA12 | PA12 | PA12/TIM1_ETR | PA12/TIM1_ETR | PA12/TIM1_ETR | PA12/TIM1_ETR | PA12/TIM1_ETR | PA12/TIM1_ETR | PA12/TIM1_ETR/USART1_RTS_DE | PA12/TIM1_ETR/USART1_RTS_DE
PA13 | JTMS-SWDIO | IR_OUT |  |  |  |  |  |  |  | PA13 | PA13/JTMS-SWDIO | PA13/JTMS-SWDIO/IR_OUT | PA13/JTMS-SWDIO/IR_OUT | PA13/JTMS-SWDIO/IR_OUT | PA13/JTMS-SWDIO/IR_OUT | PA13/JTMS-SWDIO/IR_OUT | PA13/JTMS-SWDIO/IR_OUT | PA13/JTMS-SWDIO/IR_OUT | PA13/JTMS-SWDIO/IR_OUT
PA14 | JTCK-SWCLK |  |  |  |  |  |  |  |  | PA14 | PA14/JTCK-SWCLK | PA14/JTCK-SWCLK | PA14/JTCK-SWCLK | PA14/JTCK-SWCLK | PA14/JTCK-SWCLK | PA14/JTCK-SWCLK | PA14/JTCK-SWCLK | PA14/JTCK-SWCLK | PA14/JTCK-SWCLK
PA15 | JTDI | TIM2_CH1 | TIM2_ETR |  |  | SPI1_NSS | SPI3_NSS |  |  | PA15 | PA15/JTDI | PA15/JTDI/TIM2_CH1 | PA15/JTDI/TIM2_CH1/TIM2_ETR | PA15/JTDI/TIM2_CH1/TIM2_ETR | PA15/JTDI/TIM2_CH1/TIM2_ETR | PA15/JTDI/TIM2_CH1/TIM2_ETR/SPI1_NSS | PA15/JTDI/TIM2_CH1/TIM2_ETR/SPI1_NSS/SPI3_NSS | PA15/JTDI/TIM2_CH1/TIM2_ETR/SPI1_NSS/SPI3_NSS | PA15/JTDI/TIM2_CH1/TIM2_ETR/SPI1_NSS/SPI3_NSS
PB0 |  | TIM1_CH2N | TIM3_CH3 | TIM8_CH2N |  |  |  | USART3_CK | OPAMP2_VOUT/ADC12_IN15 | PB0 | PB0 | PB0/TIM1_CH2N | PB0/TIM1_CH2N/TIM3_CH3 | PB0/TIM1_CH2N/TIM3_CH3/TIM8_CH2N | PB0/TIM1_CH2N/TIM3_CH3/TIM8_CH2N | PB0/TIM1_CH2N/TIM3_CH3/TIM8_CH2N | PB0/TIM1_CH2N/TIM3_CH3/TIM8_CH2N | PB0/TIM1_CH2N/TIM3_CH3/TIM8_CH2N/USART3_CK | PB0/TIM1_CH2N/TIM3_CH3/TIM8_CH2N/USART3_CK/OPAMP2_VOUT/ADC12_IN15
PB1 |  | TIM1_CH3N | TIM3_CH4 | TIM8_CH3N |  |  | DFSDM1_DATIN0 | USART3_RTS_DE | COMP1_INM/ADC12_IN16 | PB1 | PB1 | PB1/TIM1_CH3N | PB1/TIM1_CH3N/TIM3_CH4 | PB1/TIM1_CH3N/TIM3_CH4/TIM8_CH3N | PB1/TIM1_CH3N/TIM3_CH4/TIM8_CH3N | PB1/TIM1_CH3N/TIM3_CH4/TIM8_CH3N | PB1/TIM1_CH3N/TIM3_CH4/TIM8_CH3N/DFSDM1_DATIN0 | PB1/TIM1_CH3N/TIM3_CH4/TIM8_CH3N/DFSDM1_DATIN0/USART3_RTS_DE | PB1/TIM1_CH3N/TIM3_CH4/TIM8_CH3N/DFSDM1_DATIN0/USART3_RTS_DE/COMP1_INM/ADC12_IN16
PB2 | RTC_OUT | LPTIM1_OUT |  |  | I2C3_SMBA |  | DFSDM1_CKIN0 |  | COMP1_INP | PB2 | PB2/RTC_OUT | PB2/RTC_OUT/LPTIM1_OUT | PB2/RTC_OUT/LPTIM1_OUT | PB2/RTC_OUT/LPTIM1_OUT | PB2/RTC_OUT/LPTIM1_OUT/I2C3_SMBA | PB2/RTC_OUT/LPTIM1_OUT/I2C3_SMBA | PB2/RTC_OUT/LPTIM1_OUT/I2C3_SMBA/DFSDM1_CKIN0 | PB2/RTC_OUT/LPTIM1_OUT/I2C3_SMBA/DFSDM1_CKIN0 | PB2/RTC_OUT/LPTIM1_OUT/I2C3_SMBA/DFSDM1_CKIN0/COMP1_INP
PB3 | JTDO-TRACESWO | TIM2_CH2 |  |  |  | SPI1_SCK | SPI3_SCK | USART1_RTS_DE | COMP2_INM | PB3 | PB3/JTDO-TRACESWO | PB3/JTDO-TRACESWO/TIM2_CH2 | PB3/JTDO-TRACESWO/TIM2_CH2 | PB3/JTDO-TRACESWO/TIM2_CH2 | PB3/JTDO-TRACESWO/TIM2_CH2 | PB3/JTDO-TRACESWO/TIM2_CH2/SPI1_SCK | PB3/JTDO-TRACESWO/TIM2_CH2/SPI1_SCK/SPI3_SCK | PB3/JTDO-TRACESWO/TIM2_CH2/SPI1_SCK/SPI3_SCK/USART1_RTS_DE | PB3/JTDO-TRACESWO/TIM2_CH2/SPI1_SCK/SPI3_SCK/USART1_RTS_DE/COMP2_INM
PB4 | NJTRST |  | TIM3_CH1 |  |  | SPI1_MISO | SPI3_MISO | USART1_CTS | COMP2_INP | PB4 | PB4/NJTRST | PB4/NJTRST | PB4/NJTRST/TIM3_CH1 | PB4/NJTRST/TIM3_CH1 | PB4/NJTRST/TIM3_CH1 | PB4/NJTRST/TIM3_CH1/SPI1_MISO | PB4/NJTRST/TIM3_CH1/SPI1_MISO/SPI3_MISO | PB4/NJTRST/TIM3_CH1/SPI1_MISO/SPI3_MISO/USART1_CTS | PB4/NJTRST/TIM3_CH1/SPI1_MISO/SPI3_MISO/USART1_CTS/COMP2_INP
PB5 |  | LPTIM1_IN1 | TIM3_CH2 |  | I2C1_SMBA | SPI1_MOSI | SPI3_MOSI | USART1_CK |  | PB5 | PB5 | PB5/LPTIM1_IN1 | PB5/LPTIM1_IN1/TIM3_CH2 | PB5/LPTIM1_IN1/TIM3_CH2 | PB5/LPTIM1_IN1/TIM3_CH2/I2C1_SMBA | PB5/LPTIM1_IN1/TIM3_CH2/I2C1_SMBA/SPI1_MOSI | PB5/LPTIM1_IN1/TIM3_CH2/I2C1_SMBA/SPI1_MOSI/SPI3_MOSI | PB5/LPTIM1_IN1/TIM3_CH2/I2C1_SMBA/SPI1_MOSI/SPI3_MOSI/USART1_CK | PB5/LPTIM1_IN1/TIM3_CH2/I2C1_SMBA/SPI1_MOSI/SPI3_MOSI/USART1_CK
PB6 |  | LPTIM1_ETR | TIM4_CH1 | TIM8_BKIN2 | I2C1_SCL |  | DFSDM1_DATIN5 | USART1_TX | COMP2_INP | PB6 | PB6 | PB6/LPTIM1_ETR | PB6/LPTIM1_ETR/TIM4_CH1 | PB6/LPTIM1_ETR/TIM4_CH1/TIM8_BKIN2 | PB6/LPTIM1_ETR/TIM4_CH1/TIM8_BKIN2/I2C1_SCL | PB6/LPTIM1_ETR/TIM4_CH1/TIM8_BKIN2/I2C1_SCL | PB6/LPTIM1_ETR/TIM4_CH1/TIM8_BKIN2/I2C1_SCL/DFSDM1_DATIN5 | PB6/LPTIM1_ETR/TIM4_CH1/TIM8_BKIN2/I2C1_SCL/DFSDM1_DATIN5/USART1_TX | PB6/LPTIM1_ETR/TIM4_CH1/TIM8_BKIN2/I2C1_SCL/DFSDM1_DATIN5/USART1_TX/COMP2_INP
PB7 |  | LPTIM1_IN2 | TIM4_CH2 | TIM8_BKIN | I2C1_SDA |  | DFSDM1_CKIN5 | USART1_RX | COMP2_INM/PVD_IN | PB7 | PB7 | PB7/LPTIM1_IN2 | PB7/LPTIM1_IN2/TIM4_CH2 | PB7/LPTIM1_IN2/TIM4_CH2/TIM8_BKIN | PB7/LPTIM1_IN2/TIM4_CH2/TIM8_BKIN/I2C1_SDA | PB7/LPTIM1_IN2/TIM4_CH2/TIM8_BKIN/I2C1_SDA | PB7/LPTIM1_IN2/TIM4_CH2/TIM8_BKIN/I2C1_SDA/DFSDM1_CKIN5 | PB7/LPTIM1_IN2/TIM4_CH2/TIM8_BKIN/I2C1_SDA/DFSDM1_CKIN5/USART1_RX | PB7/LPTIM1_IN2/TIM4_CH2/TIM8_BKIN/I2C1_SDA/DFSDM1_CKIN5/USART1_RX/COMP2_INM/PVD_IN
PB8 |  |  | TIM4_CH3 |  | I2C1_SCL |  | DFSDM1_DATIN6 |  |  | PB8 | PB8 | PB8 | PB8/TIM4_CH3 | PB8/TIM4_CH3 | PB8/TIM4_CH3/I2C1_SCL | PB8/TIM4_CH3/I2C1_SCL | PB8/TIM4_CH3/I2C1_SCL/DFSDM1_DATIN6 | PB8/TIM4_CH3/I2C1_SCL/DFSDM1_DATIN6 | PB8/TIM4_CH3/I2C1_SCL/DFSDM1_DATIN6
PB9 |  | IR_OUT | TIM4_CH4 |  | I2C1_SDA | SPI2_NSS | DFSDM1_CKIN6 |  |  | PB9 | PB9 | PB9/IR_OUT | PB9/IR_OUT/TIM4_CH4 | PB9/IR_OUT/TIM4_CH4 | PB9/IR_OUT/TIM4_CH4/I2C1_SDA | PB9/IR_OUT/TIM4_CH4/I2C1_SDA/SPI2_NSS | PB9/IR_OUT/TIM4_CH4/I2C1_SDA/SPI2_NSS/DFSDM1_CKIN6 | PB9/IR_OUT/TIM4_CH4/I2C1_SDA/SPI2_NSS/DFSDM1_CKIN6 | PB9/IR_OUT/TIM4_CH4/I2C1_SDA/SPI2_NSS/DFSDM1_CKIN6
PB10 |  | TIM2_CH3 |  |  | I2C2_SCL | SPI2_SCK | DFSDM1_DATIN7 | USART3_TX |  | PB10 | PB10 | PB10/TIM2_CH3 | PB10/TIM2_CH3 | PB10/TIM2_CH3 | PB10/TIM2_CH3/I2C2_SCL | PB10/TIM2_CH3/I2C2_SCL/SPI2_SCK | PB10/TIM2_CH3/I2C2_SCL/SPI2_SCK/DFSDM1_DATIN7 | PB10/TIM2_CH3/I2C2_SCL/SPI2_SCK/DFSDM1_DATIN7/USART3_TX | PB10/TIM2_CH3/I2C2_SCL/SPI2_SCK/DFSDM1_DATIN7/USART3_TX
PB11 |  | TIM2_CH4 |  |  | I2C2_SDA |  | DFSDM1_CKIN7 | USART3_RX |  | PB11 | PB11 | PB11/TIM2_CH4 | PB11/TIM2_CH4 | PB11/TIM2_CH4 | PB11/TIM2_CH4/I2C2_SDA | PB11/TIM2_CH4/I2C2_SDA | PB11/TIM2_CH4/I2C2_SDA/DFSDM1_CKIN7 | PB11/TIM2_CH4/I2C2_SDA/DFSDM1_CKIN7/USART3_RX | PB11/TIM2_CH4/I2C2_SDA/DFSDM1_CKIN7/USART3_RX
PB12 |  | TIM1_BKIN |  | TIM1_BKIN_COMP2 | I2C2_SMBA | SPI2_NSS | DFSDM1_DATIN1 | USART3_CK |  | PB12 | PB12 | PB12/TIM1_BKIN | PB12/TIM1_BKIN | PB12/TIM1_BKIN/TIM1_BKIN_COMP2 | PB12/TIM1_BKIN/TIM1_BKIN_COMP2/I2C2_SMBA | PB12/TIM1_BKIN/TIM1_BKIN_COMP2/I2C2_SMBA/SPI2_NSS | PB12/TIM1_BKIN/TIM1_BKIN_COMP2/I2C2_SMBA/SPI2_NSS/DFSDM1_DATIN1 | PB12/TIM1_BKIN/TIM1_BKIN_COMP2/I2C2_SMBA/SPI2_NSS/DFSDM1_DATIN1/USART3_CK | PB12/TIM1_BKIN/TIM1_BKIN_COMP2/I2C2_SMBA/SPI2_NSS/DFSDM1_DATIN1/USART3_CK
PB13 |  | TIM1_CH1N |  |  | I2C2_SCL | SPI2_SCK | DFSDM1_CKIN1 | USART3_CTS |  | PB13 | PB13 | PB13/TIM1_CH1N | PB13/TIM1_CH1N | PB13/TIM1_CH1N | PB13/TIM1_CH1N/I2C2_SCL | PB13/TIM1_CH1N/I2C2_SCL/SPI2_SCK | PB13/TIM1_CH1N/I2C2_SCL/SPI2_SCK/DFSDM1_CKIN1 | PB13/TIM1_CH1N/I2C2_SCL/SPI2_SCK/DFSDM1_CKIN1/USART3_CTS | PB13/TIM1_CH1N/I2C2_SCL/SPI2_SCK/DFSDM1_CKIN1/USART3_CTS
PB14 |  | TIM1_CH2N |  | TIM8_CH2N | I2C2_SDA | SPI2_MISO | DFSDM1_DATIN2 | USART3_RTS_DE |  | PB14 | PB14 | PB14/TIM1_CH2N | PB14/TIM1_CH2N | PB14/TIM1_CH2N/TIM8_CH2N | PB14/TIM1_CH2N/TIM8_CH2N/I2C2_SDA | PB14/TIM1_CH2N/TIM8_CH2N/I2C2_SDA/SPI2_MISO | PB14/TIM1_CH2N/TIM8_CH2N/I2C2_SDA/SPI2_MISO/DFSDM1_DATIN2 | PB14/TIM1_CH2N/TIM8_CH2N/I2C2_SDA/SPI2_MISO/DFSDM1_DATIN2/USART3_RTS_DE | PB14/TIM1_CH2N/TIM8_CH2N/I2C2_SDA/SPI2_MISO/DFSDM1_DATIN2/USART3_RTS_DE
PB15 | RTC_REFIN | TIM1_CH3N |  | TIM8_CH3N |  | SPI2_MOSI | DFSDM1_CKIN2 |  |  | PB15 | PB15/RTC_REFIN | PB15/RTC_REFIN/TIM1_CH3N | PB15/RTC_REFIN/TIM1_CH3N | PB15/RTC_REFIN/TIM1_CH3N/TIM8_CH3N | PB15/RTC_REFIN/TIM1_CH3N/TIM8_CH3N | PB15/RTC_REFIN/TIM1_CH3N/TIM8_CH3N/SPI2_MOSI | PB15/RTC_REFIN/TIM1_CH3N/TIM8_CH3N/SPI2_MOSI/DFSDM1_CKIN2 | PB15/RTC_REFIN/TIM1_CH3N/TIM8_CH3N/SPI2_MOSI/DFSDM1_CKIN2 | PB15/RTC_REFIN/TIM1_CH3N/TIM8_CH3N/SPI2_MOSI/DFSDM1_CKIN2
PC0 |  | LPTIM1_IN1 |  |  | I2C3_SCL |  | DFSDM1_DATIN4 |  | ADC123_IN1 | PC0 | PC0 | PC0/LPTIM1_IN1 | PC0/LPTIM1_IN1 | PC0/LPTIM1_IN1 | PC0/LPTIM1_IN1/I2C3_SCL | PC0/LPTIM1_IN1/I2C3_SCL | PC0/LPTIM1_IN1/I2C3_SCL/DFSDM1_DATIN4 | PC0/LPTIM1_IN1/I2C3_SCL/DFSDM1_DATIN4 | PC0/LPTIM1_IN1/I2C3_SCL/DFSDM1_DATIN4/ADC123_IN1
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

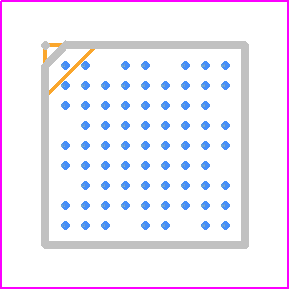
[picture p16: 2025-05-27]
Hardware/sensorAmplifier/StrainAmplifierV1/AltiumLL/SamacSys_Images/PCB_13339125.png

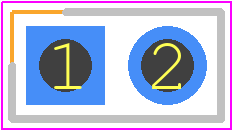
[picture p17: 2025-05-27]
Hardware/sensorAmplifier/StrainAmplifierV1/AltiumLL/SamacSys_Images/PCB_330383.png

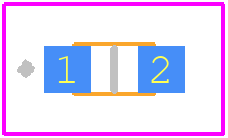
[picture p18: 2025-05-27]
Hardware/sensorAmplifier/StrainAmplifierV1/AltiumLL/SamacSys_Images/PCB_231006.png

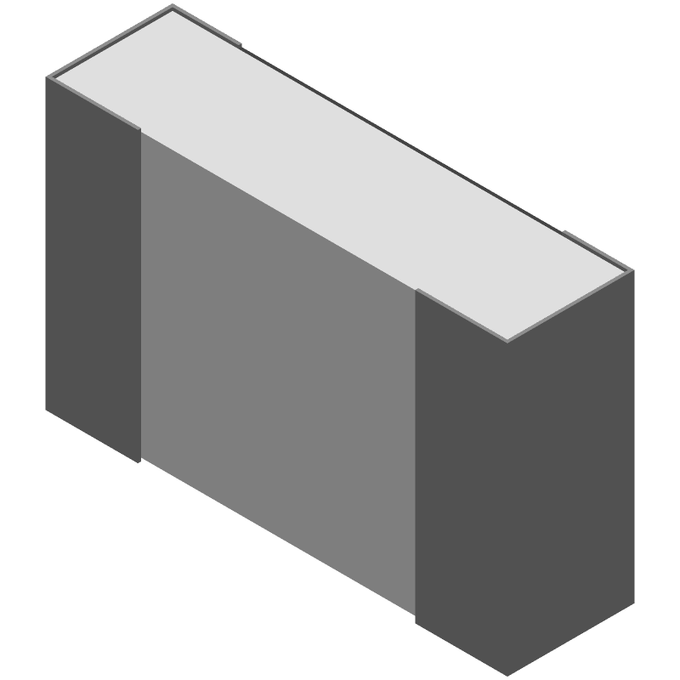
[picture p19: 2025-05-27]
Hardware/sensorAmplifier/StrainAmplifierV1/AltiumLL/SamacSys_Images/3DM_1992944.png

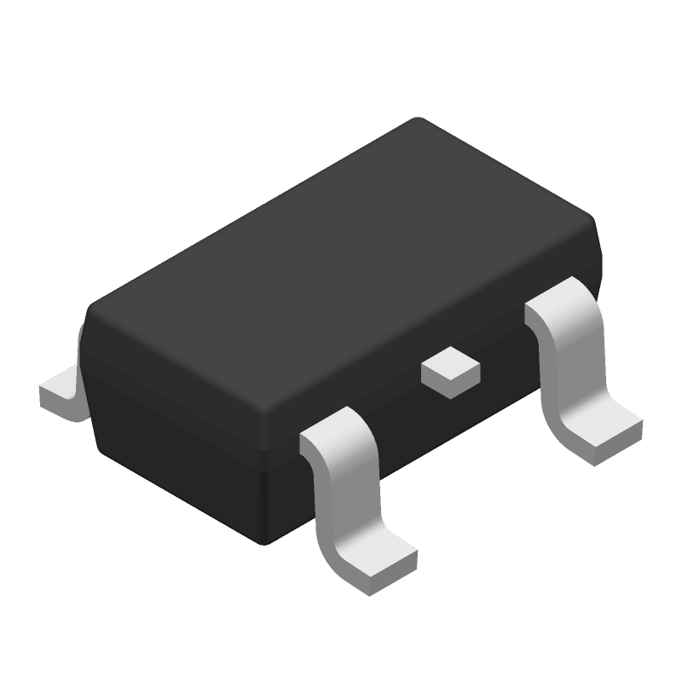
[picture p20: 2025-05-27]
Hardware/sensorAmplifier/StrainAmplifierV1/AltiumLL/SamacSys_Images/3DM_1537287.png

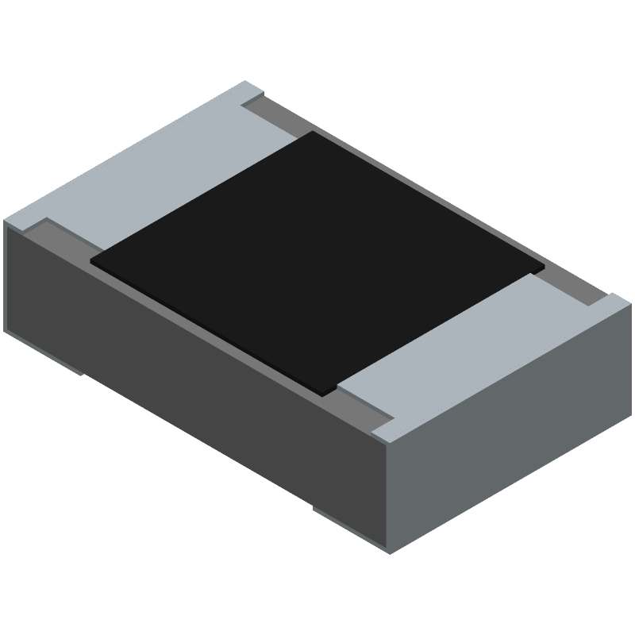
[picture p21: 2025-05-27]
Hardware/sensorAmplifier/StrainAmplifierV1/AltiumLL/SamacSys_Images/3DM_235253.png

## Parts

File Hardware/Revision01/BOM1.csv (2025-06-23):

Value | Reference | Footprint | Manufacturer | Manufacturer Part Number | Distributor link | Price per unit | Qty
Battery | BT1,BT2,BT3 |  |  |  | https://www.aliexpress.com/item/1005005859082063.html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 | 5.6725 | 3
Fiducial | FID1,FID3 | Fiducial:Fiducial_1mm_Mask2mm |  |  |  |  | 2
Conn_01x05 | J1,J14 | Connector_PinHeader_2.54mm:PinHeader_1x05_P2.54mm_Vertical |  |  |  |  | 2
Conn_01x02 | J2,J3 | Connector_PinHeader_2.54mm:PinHeader_1x02_P2.54mm_Vertical |  |  |  |  | 2
Battery connector | J4 |  |  |  | https://www.aliexpress.com/item/1005005859082063.html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 | 0.18 | 1
TestPoint | TP1,TP2,TP3,TP4,TP8,TP9,TP10 | TestPoint:TestPoint_Pad_D1.5mm |  |  |  |  | 7
Battery Holder | N1 |  | Seeed Technology Co., Ltd | 114090052 | https://www.digikey.ca/en/products/detail/seeed-technology-co-ltd/114090052/10451909 | 2.19 | 1
Polyfuse | F1 | Resistor_SMD:R_1206_3216Metric_Pad1.30x1.75mm_HandSolder |  | 1206L025/24YR | https://www.digikey.ca/en/products/detail/littelfuse-inc/1206L025-24YR/14320017 | 0.85 | 1
MRF89XAM9AT-I/RM | U2 | MRF89XAM9AT-antenna:MOD_MRF89XAM9A_MCH |  | 150-MRF89XAM9AT-I/RMDKR-ND | https://www.digikey.ca/en/products/detail/microchip-technology/MRF89XAM9AT-I-RM/10520347?productid=10520347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 | 12.7 | 1
15K +-1% | R28 | Resistor_SMD:R_0805_2012Metric_Pad1.20x1.40mm_HandSolder | YAGEO | AC0805FR-0715KL | https://www.digikey.ca/en/products/detail/yageo/AC0805FR-0715KL/5896576 | 0.16 | 1
StrainConn | J5,J6,J7,J8,J9,J10,J11,J12 | JST_3PIN:JST_B3B-XH-A | JST Sales America Inc. | B3B-XH-A | https://www.digikey.ca/en/products/detail/jst-sales-america-inc/B3B-XH-A/1651046 |  | 8
Polyfuse_Small | F2,F3,F4,F5,F6,F7,F8,F9 | Resistor_SMD:R_0603_1608Metric_Pad0.98x0.95mm_HandSolder | EPCOS - TDK Electronics | B59622A0090A062 | https://www.digikey.ca/en/products/detail/epcos-tdk-electronics/B59622A0090A062/3500748 |  | 8
10nF | C2,C3,C4,C5,C6,C7,C8,C9 | Capacitor_SMD:C_0805_2012Metric_Pad1.18x1.45mm_HandSolder |  | C0805C103J3GECAUTO | https://www.digikey.ca/en/products/detail/kemet/C0805C103J3GECAUTO/8647361 | 0.24700 | 8
0.1uF | C1,C11,C12,C13,C14,C24 | Capacitor_SMD:C_0805_2012Metric_Pad1.18x1.45mm_HandSolder | YAGEO | CC0805JRNPO9BN250 | https://www.digikey.ca/en/products/detail/yageo/CC0805JRNPO9BN250/5884044 | 0.043 | 6
10uF | C15,C20,C23 | Capacitor_SMD:C_1206_3216Metric_Pad1.33x1.80mm_HandSolder |  | CL31B106KAHNNNE | https://www.digikey.ca/en/products/detail/samsung-electro-mechanics/CL31B106KAHNNNE/3887462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 | 0.15 | 3
0 | R36,R37,R38 | Resistor_SMD:R_0805_2012Metric_Pad1.20x1.40mm_HandSolder | Vishay Dale | CRCW08050000Z0EAHP | https://www.digikey.ca/en/products/detail/vishay-dale/CRCW08050000Z0EAHP/2222316 |  | 3
1M +-1% | R9,R10,R11,R12,R13,R14,R15,R16 | Resistor_SMD:R_0805_2012Metric_Pad1.20x1.40mm_HandSolder | Vishay Dale | CRCW08051M00FKEA | https://www.digikey.ca/en/products/detail/vishay-dale/CRCW08051M00FKEA/1176016 |  | 8
76.8K+- 1% | R39 | Resistor_SMD:R_0805_2012Metric_Pad1.20x1.40mm_HandSolder | Vishay Dale | CRCW080576K8FKEA | https://www.digikey.ca/en/products/detail/vishay-dale/CRCW080576K8FKEA/1175852 |  | 1
150uH | L1 | DRA74-151-R:IND_CB_DRA74 | Eaton - Electronics Division | DRA74-151-R | https://www.digikey.ca/en/products/detail/eaton-electronics-division/DRA74-151-R/1762392 | 1.32 | 1
1uF | C21,C22 | Capacitor_SMD:C_0805_2012Metric_Pad1.18x1.45mm_HandSolder | Murata Electronics | GCM21BR71H105KA03L | https://www.digikey.ca/en/products/detail/murata-electronics/GCM21BR71H105KA03L/4903984 |  | 2
100uF | C10 | Capacitor_SMD:C_1206_3216Metric_Pad1.33x1.80mm_HandSolder |  | GRM31CR61A107MEA8L | https://www.digikey.ca/en/products/detail/murata-electronics/GRM31CR61A107MEA8K/16286060 | 0.71 | 1
LMR51603XFDBVR | U6 | DBV0006A-MFG-IPC_A | Texas Instruments | LMR51606XDBVR | https://www.digikey.ca/en/products/detail/texas-instruments/LMR51606XDBVR/22116882?gad_source=1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 |  | 1
D_Schottky_Small | D1,D2,D3,D4,D5,D6,D7,D8,D9,D10,D11,D12,D13,D14,D15,D16 | Diode_SMD:D_SOD-123 | Diodes Incorporated | MMSZ5226BQ-7-F | https://www.digikey.ca/en/products/detail/diodes-incorporated/MMSZ5226BQ-7-F/16547962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 |  | 16
MPU-6500 | U3 | MPU-6500:QFN40P300X300X95-25N | TDK InvenSense | MPU-6500 | https://www.digikey.ca/en/products/detail/tdk-invensense/MPU-6500/4385413?gad_source=1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 |  | 1
NMOS | Q2 | Package_TO_SOT_SMD:TSOT-23 | onsemi | NTR4003NT3G | https://www.digikey.ca/en/products/detail/onsemi/NTR4003NT3G/1967271?gclsrc=aw.ds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 | 0.35 | 1
PMOS | Q1,Q3 | Package_TO_SOT_SMD:TSOT-23 | onsemi | NVTR01P02LT1G | https://www.digikey.ca/en/products/detail/onsemi/NVTR01P02LT1G/5969313?gclsrc=aw.ds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 | 0.71 | 2
1.6K +-1% | R1,R2,R3,R4,R5,R6,R7,R8 | Resistor_SMD:R_0805_2012Metric_Pad1.20x1.40mm_HandSolder | YAGEO | RC0402FR-071K6L | https://www.digikey.ca/en/products/detail/yageo/RC0805FR-071K6L/727504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 | 0.012 | 8
10K +-1% | R17,R26,R27,R40 | Resistor_SMD:R_0805_2012Metric_Pad1.20x1.40mm_HandSolder | KOA Speer Electronics, Inc. | RK73H2ATTD1002F | https://www.digikey.ca/en/products/detail/koa-speer-electronics-inc/RK73H2ATTD1002F/10234111 | 0.16 | 4
5K +-1% | R29 | Resistor_SMD:R_0805_2012Metric_Pad1.20x1.40mm_HandSolder | Vishay Dale | TNPW08054K99BEEA | https://www.digikey.ca/en/products/detail/vishay-dale/TNPW08054K99BEEA/1607361 | 0.56 | 1
ON/OFF_SW_SPST_LED | SW1 | Connector_PinHeader_2.54mm:PinHeader_1x03_P2.54mm_Vertical |  | V2D2S00B-GZCAD-100-XACT1 | https://www.digikey.ca/en/products/detail/carling-technologies/V2D2S00B-GZCAD-100-XACT1/11481760 | 7.88 | 1

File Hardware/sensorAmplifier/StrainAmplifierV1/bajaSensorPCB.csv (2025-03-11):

Reference | Value | Datasheet | Footprint | Qty | DNP | # | ALT_MPN | DNM | DNM_MPN | MPN | URL | Description | Manufacturer | Manufacturer Part Number | Distributor link
R1 | 0R | ~ | Resistor_SMD:R_0402_1005Metric | 1 |  | 1 |  |  |  | RC0402FR-070RL
C46 | 5.6pF | ~ | Capacitor_SMD:C_0402_1005Metric | 1 |  | 2 |  |  |  | CC0402BRNPO9BN5R6 | https://lcsc.com/product-detail/Multilayer-Ceramic-Capacitors-MLCC-SMD-SMT_YAGEO-CC0402BRNPO9BN5R6_C505468.html
C49 | 5.6pF | ~ | Capacitor_SMD:C_0402_1005Metric | 1 |  | 3 |  |  |  | CC0402BRNPO9BN5R6 | https://lcsc.com/product-detail/Multilayer-Ceramic-Capacitors-MLCC-SMD-SMT_YAGEO-CC0402BRNPO9BN5R6_C505468.html
C21 | 33pF | ~ | Capacitor_SMD:C_0402_1005Metric | 1 |  | 4 | CC0402JRNPO9BN330 |  |  | CC0402FRNPO9BN330 | https://lcsc.com/product-detail/Others_YAGEO-CC0402FRNPO9BN330_C327064.html
C23 | 47pF | ~ | Capacitor_SMD:C_0402_1005Metric | 1 |  | 5 |  |  |  | CC0402JRNPO9BN470 | https://lcsc.com/product-detail/Multilayer-Ceramic-Capacitors-MLCC-SMD-SMT_YAGEO-CC0402JRNPO9BN470_C60137.html
C43 | 1nF | ~ | Capacitor_SMD:C_0402_1005Metric | 1 |  | 6 |  |  |  | CC0402KRX7R7BB102
C34 | 10nF | ~ | Capacitor_SMD:C_0402_1005Metric | 1 |  | 7 |  |  |  | CC0402KRX7R7BB103 | https://lcsc.com/product-detail/Multilayer-Ceramic-Capacitors-MLCC-SMD-SMT_YAGEO-CC0402KRX7R7BB103_C327009.html
C7 | 100nF | ~ | Capacitor_SMD:C_0402_1005Metric | 1 |  | 8 |  |  |  | CC0402KRX7R7BB104 | https://lcsc.com/product-detail/Multilayer-Ceramic-Capacitors-MLCC-SMD-SMT_YAGEO-CC0402KRX7R7BB104_C60474.html
C9 | 100nF | ~ | Capacitor_SMD:C_0402_1005Metric | 1 |  | 9 |  |  |  | CC0402KRX7R7BB104 | https://lcsc.com/product-detail/Multilayer-Ceramic-Capacitors-MLCC-SMD-SMT_YAGEO-CC0402KRX7R7BB104_C60474.html
C10 | 100nF | ~ | Capacitor_SMD:C_0402_1005Metric | 1 |  | 10 |  |  |  | CC0402KRX7R7BB104 | https://lcsc.com/product-detail/Multilayer-Ceramic-Capacitors-MLCC-SMD-SMT_YAGEO-CC0402KRX7R7BB104_C60474.html
C14 | 100nF | ~ | Capacitor_SMD:C_0402_1005Metric | 1 |  | 11 |  |  |  | CC0402KRX7R7BB104 | https://lcsc.com/product-detail/Multilayer-Ceramic-Capacitors-MLCC-SMD-SMT_YAGEO-CC0402KRX7R7BB104_C60474.html
C16 | 100nF | ~ | Capacitor_SMD:C_0402_1005Metric | 1 |  | 12 |  |  |  | CC0402KRX7R7BB104 | https://lcsc.com/product-detail/Multilayer-Ceramic-Capacitors-MLCC-SMD-SMT_YAGEO-CC0402KRX7R7BB104_C60474.html
C17 | 100nF | ~ | Capacitor_SMD:C_0402_1005Metric | 1 |  | 13 |  |  |  | CC0402KRX7R7BB104 | https://lcsc.com/product-detail/Multilayer-Ceramic-Capacitors-MLCC-SMD-SMT_YAGEO-CC0402KRX7R7BB104_C60474.html
C18 | 100nF | ~ | Capacitor_SMD:C_0402_1005Metric | 1 |  | 14 |  |  |  | CC0402KRX7R7BB104 | https://lcsc.com/product-detail/Multilayer-Ceramic-Capacitors-MLCC-SMD-SMT_YAGEO-CC0402KRX7R7BB104_C60474.html
C20 | 100nF | ~ | Capacitor_SMD:C_0402_1005Metric | 1 |  | 15 |  |  |  | CC0402KRX7R7BB104 | https://lcsc.com/product-detail/Multilayer-Ceramic-Capacitors-MLCC-SMD-SMT_YAGEO-CC0402KRX7R7BB104_C60474.html
C24 | 100nF | ~ | Capacitor_SMD:C_0402_1005Metric | 1 |  | 16 |  |  |  | CC0402KRX7R7BB104 | https://lcsc.com/product-detail/Multilayer-Ceramic-Capacitors-MLCC-SMD-SMT_YAGEO-CC0402KRX7R7BB104_C60474.html
C63 | 100nF | ~ | Capacitor_SMD:C_0402_1005Metric | 1 |  | 17 |  |  |  | CC0402KRX7R7BB104 | https://lcsc.com/product-detail/Multilayer-Ceramic-Capacitors-MLCC-SMD-SMT_YAGEO-CC0402KRX7R7BB104_C60474.html
C64 | 100nF | ~ | Capacitor_SMD:C_0402_1005Metric | 1 |  | 18 |  |  |  | CC0402KRX7R7BB104 | https://lcsc.com/product-detail/Multilayer-Ceramic-Capacitors-MLCC-SMD-SMT_YAGEO-CC0402KRX7R7BB104_C60474.html
C65 | 100nF | ~ | Capacitor_SMD:C_0402_1005Metric | 1 |  | 19 |  |  |  | CC0402KRX7R7BB104 | https://lcsc.com/product-detail/Multilayer-Ceramic-Capacitors-MLCC-SMD-SMT_YAGEO-CC0402KRX7R7BB104_C60474.html
C3 | 1uF | ~ | Capacitor_SMD:C_0402_1005Metric | 1 |  | 20 |  |  |  | CL05A105KQ5NNNC | https://lcsc.com/product-detail/Multilayer-Ceramic-Capacitors-MLCC-SMD-SMT_Samsung-Electro-Mechanics-CL05A105KQ5NNNC_C107372.html
C6 | 1uF | ~ | Capacitor_SMD:C_0402_1005Metric | 1 |  | 21 |  |  |  | CL05A105KQ5NNNC | https://lcsc.com/product-detail/Multilayer-Ceramic-Capacitors-MLCC-SMD-SMT_Samsung-Electro-Mechanics-CL05A105KQ5NNNC_C107372.html
C11 | 1uF | ~ | Capacitor_SMD:C_0402_1005Metric | 1 |  | 22 |  |  |  | CL05A105KQ5NNNC | https://lcsc.com/product-detail/Multilayer-Ceramic-Capacitors-MLCC-SMD-SMT_Samsung-Electro-Mechanics-CL05A105KQ5NNNC_C107372.html
C51 | 1uF | ~ | Capacitor_SMD:C_0402_1005Metric | 1 |  | 23 |  |  |  | CL05A105KQ5NNNC | https://lcsc.com/product-detail/Multilayer-Ceramic-Capacitors-MLCC-SMD-SMT_Samsung-Electro-Mechanics-CL05A105KQ5NNNC_C107372.html
L1 | 2.2uH | ~ | node-lib-v1:L_HPC4012TF-2R2M | 1 |  | 24 |  |  |  | HPC4012TF-2R2M | https://lcsc.com/product-detail/Power-Inductors_TAI-TECH-HPC4012TF-2R2M_C357047.html
C13 | 4.7uF | ~ | Capacitor_SMD:C_0603_1608Metric | 1 |  | 25 | C1608X5R1C475K080AC |  |  | CL10A475KO8NNNC | https://lcsc.com/product-detail/Multilayer-Ceramic-Capacitors-MLCC-SMD-SMT_SAMSUNG_CL10A475KO8NNNC_4-7uF-475-10-16V_C19666.html
C15 | 4.7uF | ~ | Capacitor_SMD:C_0603_1608Metric | 1 |  | 26 | C1608X5R1C475K080AC |  |  | CL10A475KO8NNNC | https://lcsc.com/product-detail/Multilayer-Ceramic-Capacitors-MLCC-SMD-SMT_SAMSUNG_CL10A475KO8NNNC_4-7uF-475-10-16V_C19666.html
C12 | 22uF | ~ | Capacitor_SMD:C_0603_1608Metric | 1 |  | 27 | JMK107BBJ226MA |  |  | CC0603MRX5R5BB226 | https://lcsc.com/product-detail/Multilayer-Ceramic-Capacitors-MLCC-SMD-SMT_22uF-226-20-6-3V_C109448.html
C1 | 100uF | ~ | Capacitor_SMD:C_1206_3216Metric | 1 |  | 28 |  |  |  | JMK316ABJ107ML-T | https://lcsc.com/product-detail/Multilayer-Ceramic-Capacitors-MLCC-SMD-SMT_Taiyo-Yuden-JMK316ABJ107ML-T_C268006.html
C4 | 100uF | ~ | Capacitor_SMD:C_1206_3216Metric | 1 |  | 29 |  |  |  | JMK316ABJ107ML-T | https://lcsc.com/product-detail/Multilayer-Ceramic-Capacitors-MLCC-SMD-SMT_Taiyo-Yuden-JMK316ABJ107ML-T_C268006.html
C5 | 100uF | ~ | Capacitor_SMD:C_1206_3216Metric | 1 |  | 30 |  |  |  | JMK316ABJ107ML-T | https://lcsc.com/product-detail/Multilayer-Ceramic-Capacitors-MLCC-SMD-SMT_Taiyo-Yuden-JMK316ABJ107ML-T_C268006.html
R19 | 33R | ~ | Resistor_SMD:R_0402_1005Metric | 1 |  | 31 |  |  |  | AC0402JR-0733RL | https://lcsc.com/product-detail/_AC0402JR-0733RL_C144713.html
R24 | 100R | ~ | Resistor_SMD:R_0402_1005Metric | 1 |  | 32 |  |  |  | RC0402FR-07100RL | https://lcsc.com/product-detail/Chip-Resistor-Surface-Mount_YAGEO-RC0402FR-07100RL_C106232.html
R5 | 220R | ~ | Inductor_SMD:L_0402_1005Metric | 1 |  | 33 |  |  |  | RC0402FR-07220RL | https://lcsc.com/product-detail/Chip-Resistor-Surface-Mount_YAGEO-RC0402FR-07220RL_C112291.html
R22 | 330R | ~ | Resistor_SMD:R_0402_1005Metric | 1 |  | 34 |  |  |  | AC0402FR-07330RL | https://lcsc.com/product-detail/Chip-Resistor-Surface-Mount_YAGEO-AC0402FR-07330RL_C226996.html
R23 | 330R | ~ | Resistor_SMD:R_0402_1005Metric | 1 |  | 35 |  |  |  | AC0402FR-07330RL | https://lcsc.com/product-detail/Chip-Resistor-Surface-Mount_YAGEO-AC0402FR-07330RL_C226996.html
R16 | 1K | ~ | Resistor_SMD:R_0402_1005Metric | 1 |  | 36 |  |  |  | RC0402FR-071KL | https://lcsc.com/product-detail/Chip-Resistor-Surface-Mount_1KR-1001-1_C106235.html
R21 | 1K | ~ | Resistor_SMD:R_0402_1005Metric | 1 |  | 37 |  |  |  | RC0402FR-071KL | https://lcsc.com/product-detail/Chip-Resistor-Surface-Mount_1KR-1001-1_C106235.html
R20 | 10K | ~ | Inductor_SMD:L_0402_1005Metric | 1 |  | 38 |  |  |  | AC0402JR-0710KL | https://lcsc.com/product-detail/Chip-Resistor-Surface-Mount_YAGEO-AC0402JR-0710KL_C144731.html
Y1 | 32.768KHz | ~ | node-lib-v1:Crystal_SMD_NX2012SA_32.768KHz | 1 |  | 39 |  |  |  | X1A000061002100 | https://lcsc.com/product-detail/SMD-Crystal-Resonators_Seiko-Epson_X1A000061002100_Seiko-Epson-X1A000061002100_C255767.html
R2 | 100K | ~ | Resistor_SMD:R_0402_1005Metric | 1 |  | 40 |  |  |  | RC0402FR-07100KL | https://lcsc.com/product-detail/Chip-Resistor-Surface-Mount_YAGEO-RC0402FR-07100KL_C60491.html
R3 | 100K | ~ | Resistor_SMD:R_0402_1005Metric | 1 |  | 41 |  |  |  | RC0402FR-07100KL | https://lcsc.com/product-detail/Chip-Resistor-Surface-Mount_YAGEO-RC0402FR-07100KL_C60491.html
R25 | 100K | ~ | Resistor_SMD:R_0402_1005Metric | 1 |  | 42 |  |  |  | RC0402FR-07100KL | https://lcsc.com/product-detail/Chip-Resistor-Surface-Mount_YAGEO-RC0402FR-07100KL_C60491.html
X1 | 32MHz |  | Crystal:Crystal_SMD_Abracon_ABM10-4Pin_2.5x2.0mm | 1 |  | 43 |  |  |  | ‎TG2520SMN 32.0000M-MCGNNM3‎ | https://www.digikey.de/product-detail/en/TG2520SMN+32.0000M-MCGNNM3/114-TG2520SMN32.0000M-MCGNNM3CT-ND/13152046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
L10 | 1400R @1GHz | ~ | Inductor_SMD:L_0402_1005Metric | 1 |  | 44 |  |  |  | BLM15HG102SN1D | https://lcsc.com/product-detail/Ferrite-Beads_Murata-Electronics-BLM15HG102SN1D_C76889.html
C22 | 18123D106KAT2A | 18123D106KAT2A | CAP_1812Z_AVX | 1 |  | 45 |  |  |  |  |  |  | KYOCERA AVX | 18123D106KAT2A | https://www.digikey.ca/en/products/detail/kyocera-avx/18123D106KAT2A/564676
D2 | 1N4148WSF-7 |  | node-lib-v1:D_SOD-323F_custom | 1 |  | 46 |  |  |  | 1N4148WSF-7 | https://lcsc.com/product-detail/Switching-Diode_Diodes-Incorporated-1N4148WSF-7_C119617.html
R14 | 4K7 | ~ | Resistor_SMD:R_0402_1005Metric | 1 |  | 47 |  |  |  | AC0402FR-074K7L | https://lcsc.com/product-detail/Chip-Resistor-Surface-Mount_YAGEO-AC0402FR-074K7L_C174364.html
R15 | 4K7 | ~ | Resistor_SMD:R_0402_1005Metric | 1 |  | 48 |  |  |  | AC0402FR-074K7L | https://lcsc.com/product-detail/Chip-Resistor-Surface-Mount_YAGEO-AC0402FR-074K7L_C174364.html
R17 | 4K7 | ~ | Resistor_SMD:R_0402_1005Metric | 1 |  | 49 |  |  |  | AC0402FR-074K7L | https://lcsc.com/product-detail/Chip-Resistor-Surface-Mount_YAGEO-AC0402FR-074K7L_C174364.html
R18 | 4K7 | ~ | Resistor_SMD:R_0402_1005Metric | 1 |  | 50 |  |  |  | AC0402FR-074K7L | https://lcsc.com/product-detail/Chip-Resistor-Surface-Mount_YAGEO-AC0402FR-074K7L_C174364.html
FB1 | 600R @100MHz | ~ | Inductor_SMD:L_0603_1608Metric | 1 |  | 51 |  |  |  | BLM18AG601SN1D | https://lcsc.com/product-detail/Ferrite-Beads_Murata-Electronics-BLM18AG601SN1D_C19330.html
U3 | AD7124-8BCPZ-RL7 | AD7124-8BCPZ-RL7 | CP-32-12_ADI | 1 |  | 52 |  |  |  |  |  |  | Analog Devices Inc. | AD7124-8BCPZ-RL7 | https://www.digikey.ca/en/products/detail/analog-devices-inc/AD7124-8BCPZ-RL7/5268028
CR1 | B0530W-7-F | B0530W-7-F | SOD123_DIO | 1 |  | 53 |  |  |  |  |  |  | Diodes Incorporated | B0530W-7-F | https://www.digikey.ca/en/products/detail/diodes-incorporated/B0530W-7-F/814937
N1 | BoLink-16174563 | ~ | node-lib-v1:BoLink_704025 | 1 |  | 54 | S6L-303013 |  |  | DNM | https://www.distrelec.nl/en/bolink-iot-enclosure-bolink-43-2x71-2x26mm-white-polycarbonate-ip65-bopla-16174563-hmt1/p/30144876
JP5 | BOOT0 | ~ | Connector_PinHeader_1.27mm:PinHeader_1x02_P1.27mm_Vertical | 1 |  | 55 |  |  |  | ~ | ~
JP6 | BTN_CUT | ~ | Jumper:SolderJumper-2_P1.3mm_Bridged2Bar_RoundedPad1.0x1.5mm | 1 |  | 56 |  |  |  | ~ | ~
JP2 | BUZZ_KILL | ~ | Jumper:SolderJumper-2_P1.3mm_Bridged2Bar_RoundedPad1.0x1.5mm | 1 |  | 57 |  |  |  | ~ | ~
C8 | CC0603KRX7R7BB104 |  | CC0603KRX7R7BB104:CAPC1608X90 | 1 |  | 58 |  |  |  |  |  |  | YAGEO | CC0603KRX7R7BB104 | https://www.digikey.com/en/products/detail/yageo/CC0603KRX7R7BB104/302822
C19 | CC0603KRX7R7BB104 |  | CC0603KRX7R7BB104:CAPC1608X90 | 1 |  | 59 |  |  |  |  |  |  | YAGEO | CC0603KRX7R7BB104 | https://www.digikey.com/en/products/detail/yageo/CC0603KRX7R7BB104/302822
J11 | Conn_02x08_Odd_Even | ~ |  | 1 |  | 60 |  |  |  |  |  | Generic connector, double row, 02x08, odd/even pin numbering scheme (row 1 odd numbers, row 2 even numbers), script generated (kicad-library-utils/schlib/autogen/connector/)
J13 | Conn_02x08_Odd_Even | ~ |  | 1 |  | 61 |  |  |  |  |  | Generic connector, double row, 02x08, odd/even pin numbering scheme (row 1 odd numbers, row 2 even numbers), script generated (kicad-library-utils/schlib/autogen/connector/)
TP6 | CS | ~ | TestPoint:TestPoint_Pad_D1.5mm | 1 |  | 62 |  |  |  | DNM | ~
TP14 | CS | ~ | TestPoint:TestPoint_Pad_D1.5mm | 1 |  | 63 |  |  |  | DNM | ~
J8 | DEBUG | ~ | Connector_PinSocket_2.54mm:PinSocket_1x07_P2.54mm_Vertical | 1 |  | 64
C2 | DNM | ~ | Capacitor_SMD:C_0402_1005Metric | 1 |  | 65 |  |  |  | CC0402KRX7R7BB103 | https://lcsc.com/product-detail/Multilayer-Ceramic-Capacitors-MLCC-SMD-SMT_YAGEO-CC0402KRX7R7BB103_C327009.html
R4 | ERJ-3EKF1002V | ERJ-3EKF1002V | RC0603N_PAN | 1 |  | 66 |  |  |  |  |  |  | Panasonic Electronic Components | ERJ-3EKF1002V | https://www.digikey.ca/en/products/detail/panasonic-electronic-components/ERJ-3EKF1002V/196066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
R6 | ERJ-3EKF1002V | ERJ-3EKF1002V | RC0603N_PAN | 1 |  | 67 |  |  |  |  |  |  | Panasonic Electronic Components | ERJ-3EKF1002V | https://www.digikey.ca/en/products/detail/panasonic-electronic-components/ERJ-3EKF1002V/196066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
D4 | ESD9D5V | ~ | Diode_SMD:D_SOD-923 | 1 |  | 68 |  |  |  | Diode_SMD:D_SOD-923 | https://lcsc.com/product-detail/TVS_Leiditech-ESD9D5V_C384848.html
D5 | ESD9D5V | ~ | Diode_SMD:D_SOD-923 | 1 |  | 69 |  |  |  | Diode_SMD:D_SOD-923 | https://lcsc.com/product-detail/TVS_Leiditech-ESD9D5V_C384848.html
D3 | FM-B2020RGBA | ~ | LED_SMD:LED_Cree-PLCC4_2x2mm_CW | 1 |  | 70 |  |  |  | FM-B2020RGBA-HG | https://lcsc.com/product-detail/Light-Emitting-Diodes-LED_Foshan-NationStar-Optoelectronics-FM-B2020RGBA-HG_C108793.html
U6 | ICM-42605 | ICM-42605 | LGA14_2P5X3X0P91_IVS | 1 |  | 71 |  |  |  |  |  |  | TDK InvenSense | ICM-42605 | https://www.digikey.ca/en/products/detail/tdk-invensense/ICM-42605/9953675?productid=9953675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
J2 | JST-PH | ~ | Connector_JST:JST_PH_B2B-PH-SM4-TB_1x02-1MP_P2.00mm_Vertical | 1 |  | 72 |  |  |  | B2B-PH-SM4-TB(LF)(SN) | https://lcsc.com/product-detail/Wire-To-Board-Wire-To-Wire-Connector_JST-Sales-America-B2B-PH-SM4-TB-LF-SN_C160352.html
U8 | MAX1837ETT50+T | MAX1837ETT50+T | 21-0137I_T1033-1_MXM | 1 |  | 73 |  |  |  |  |  |  | Analog devices | MAX1837ETT50+T | https://www.digikey.com/en/products/detail/analog-devices-inc-maxim-integrated/MAX1837ETT50-T/1519115
TP7 | MISO | ~ | TestPoint:TestPoint_Pad_D1.5mm | 1 |  | 74 |  |  |  | DNM | ~
TP15 | MISO | ~ | TestPoint:TestPoint_Pad_D1.5mm | 1 |  | 75 |  |  |  | DNM | ~
PZ1 | MLT-7525 | ~ | node-lib-v1:Buzzer_MLT-7525 | 1 |  | 76 |  |  |  | MLT-7525 | https://lcsc.com/product-detail/Buzzers_Jiangsu-Huaneng-Elec-MLT-7525_C95299.html
TP9 | MOSI | ~ | TestPoint:TestPoint_Pad_D1.5mm | 1 |  | 77 |  |  |  | DNM | ~
TP17 | MOSI | ~ | TestPoint:TestPoint_Pad_D1.5mm | 1 |  | 78 |  |  |  | DNM | ~
H1 | MountingHole | ~ | MountingHole:MountingHole_2.5mm | 1 |  | 79 |  |  |  | ~ | ~
H2 | MountingHole | ~ | MountingHole:MountingHole_2.5mm | 1 |  | 80 |  |  |  | ~ | ~
U7 | MRF89XAM9AT-I/RM | MRF89XAM9AT-I/RM | MOD_MRF89XAM9A_MCH | 1 |  | 81 |  |  |  |  |  |  | Microchip Technology | MRF89XAM9AT-I/RM | https://www.digikey.ca/en/products/detail/microchip-technology/MRF89XAM9AT-I-RM/10519305
D1 | PESD5V0S1BA | ~ | Diode_SMD:D_SOD-323 | 1 |  | 82 |  |  |  | PESD5V0S1BA,115 | https://lcsc.com/product-detail/TVS_Nexperia-PESD5V0S1BA-115_C19224.html
Q2 | PMST4401,115 |  | Package_TO_SOT_SMD:SOT-323_SC-70 | 1 |  | 83 |  |  |  | PMST4401,115 | https://lcsc.com/product-detail/Transistors-NPN-PNP_Nexperia-PMST4401-115_C454963.html
Q1 | PMV32UP,215 | ~ | Package_TO_SOT_SMD:SOT-23 | 1 |  | 84 |  |  |  | PMV32UP,215 | https://lcsc.com/product-detail/MOSFET_Nexperia-PMV32UP-215_C282569.html
F1 | PTC 13V 1A | ~ | Fuse:Fuse_1210_3225Metric_Castellated | 1 |  | 85 |  |  |  | SMD1210-050 | https://lcsc.com/product-detail/PTC-Resettable-Fuses_TECHFUSE-SMD1210-050_C70094.html
J10 | Qwiic | ~ | Connector_JST:JST_SH_BM04B-SRSS-TB_1x04-1MP_P1.00mm_Vertical | 1 |  | 86 |  |  |  | BM04B-SRSS-TB(LF)(SN) | https://lcsc.com/product-detail/Wire-To-Board-Wire-To-Wire-Connector_JST-Sales-America-BM04B-SRSS-TB-LF-SN_C160390.html
SW2 | RESET | ~ | node-lib-v1:SW_SPST_SKSHABE010 | 1 |  | 87 |  |  |  | SKSHABE010 | https://lcsc.com/product-detail/Tactile-Switches_ALPS-Electric-SKSHABE010_C255507.html
U4 | RP605Z283B | Texas Instruments | node-lib-v1:WLCSP-20-P3_1.994x1.609mm_Layout5x4_P0.4mm | 1 |  | 88 |  |  |  | RP605Z283B-E2-F | https://eu.mouser.com/ProductDetail/Ricoh-Electronic-Devices-Company/RP605Z283B-E2-F
TP8 | SCK | ~ | TestPoint:TestPoint_Pad_D1.5mm | 1 |  | 89 |  |  |  | DNM | ~
TP16 | SCK | ~ | TestPoint:TestPoint_Pad_D1.5mm | 1 |  | 90 |  |  |  | DNM | ~
TP13 | SCL | ~ | TestPoint:TestPoint_Pad_D1.5mm | 1 |  | 91 |  |  |  | DNM | ~
JP4 | SCL2_CUT | ~ | Jumper:SolderJumper-2_P1.3mm_Bridged2Bar_RoundedPad1.0x1.5mm | 1 |  | 92 |  |  |  | ~ | ~
TP12 | SDA | ~ | TestPoint:TestPoint_Pad_D1.5mm | 1 |  | 93 |  |  |  | DNM | ~
JP3 | SDA2_CUT | ~ | Jumper:SolderJumper-2_P1.3mm_Bridged2Bar_RoundedPad1.0x1.5mm | 1 |  | 94 |  |  |  | ~ | ~
U10 | SHTC3 | https://www.sensirion.com/fileadmin/user_upload/customers/sensirion/Dokumente/0_Datasheets/Humidity/Sensirion_Humidity_Sensors_SHTC3_Datasheet.pdf | node-lib-v1:Sensirion_DFN-4-1EP_2x2mm_P1mm_EP0.7x1.6mm | 1 |  | 95 |  |  |  | SHTC3 | https://lcsc.com/product-detail/Temperature-Humidity-Sensors_Sensirion-SHTC3_C194656.html
U5 | STM32WL55CCU6 | https://www.st.com/resource/en/datasheet/stm32wl55cc.pdf | Package_DFN_QFN:QFN-48-1EP_7x7mm_P0.5mm_EP5.45x5.45mm | 1 |  | 96 |  |  |  | STM32WL55CCU6 | https://www.st.com/en/microcontrollers-microprocessors/stm32wl55cc.html
C25 | T520V686M010ATE045 | T520V686M010ATE045 | CAPMP7.6X4.3_1.9N_KEM | 1 |  | 97 |  |  |  |  |  |  | KEMET | T520V686M010ATE045 | https://www.digikey.ca/en/products/detail/kemet/T520V686M010ATE045/819436
U1 | TPS22917DBV | http://www.ti.com/lit/ds/symlink/tps22917.pdf | Package_TO_SOT_SMD:SOT-23-6 | 1 |  | 98 |  |  |  | TPS22917DBVR | https://www.ti.com/store/ti/en/p/product/?p=TPS22917DBVR
U12 | TPS22917DBV | http://www.ti.com/lit/ds/symlink/tps22917.pdf | Package_TO_SOT_SMD:SOT-23-6 | 1 |  | 99 |  |  |  | TPS22917DBVR | https://www.ti.com/store/ti/en/p/product/?p=TPS22917DBVR
U2 | TPS3839G18DBZT‎ | http://www.ti.com/lit/ds/sbvs193d/sbvs193d.pdf | Package_TO_SOT_SMD:SOT-23 | 1 |  | 100 |  |  |  | TPS3839G18DBZT‎ | https://www.ti.com/store/ti/en/p/product/?p=TPS3839G25DBZR
J9 | UART/I2C | ~ | Connector_PinSocket_2.54mm:PinSocket_1x07_P2.54mm_Vertical | 1 |  | 101
SW1 | USR_BTN | ~ | node-lib-v1:PushButton_KSC721GLFS | 1 |  | 102 |  |  |  | KSC721GLFS | https://lcsc.com/product-detail/Tactile-Switches_C-K-KSC721GLFS_C221764.html
TP2 | VBAT | ~ | TestPoint:TestPoint_Pad_D1.5mm | 1 |  | 103 |  |  |  | DNM | ~
TP4 | VBAT_ADC | ~ | TestPoint:TestPoint_Pad_D1.5mm | 1 |  | 104 |  |  |  | DNM | ~
TP3 | VBAT_READ_EN | ~ | TestPoint:TestPoint_Pad_D1.5mm | 1 |  | 105 |  |  |  | DNM | ~
TP5 | VCC | ~ | TestPoint:TestPoint_Pad_D1.5mm | 1 |  | 106 |  |  |  | DNM | ~
TP10 | VCC_F | ~ | TestPoint:TestPoint_Pad_D1.5mm | 1 |  | 107 |  |  |  | DNM | ~
TP11 | VCC_S | ~ | TestPoint:TestPoint_Pad_D1.5mm | 1 |  | 108 |  |  |  | DNM | ~
TP1 | VIN | ~ | TestPoint:TestPoint_Pad_D1.5mm | 1 |  | 109 |  |  |  | DNM | ~
U9 | WE-TPC_5828 |  | WE-TPC_5828:WE-TPC_5828 | 1 |  | 110 |  |  |  |  |  |  | Würth Elektronik | 744053470 | https://www.digikey.com/en/products/detail/w%C3%BCrth-elektronik/744053470/1639111

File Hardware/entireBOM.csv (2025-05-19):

Value | Reference | Manufacturer | Manufacturer Part Number | Distributor link | Price per unit | Qty
Battery | BT1,BT2,BT3,BT4 |  |  | https://www.aliexpress.com/item/1005005859082063.html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 | 5.6725 | 4 | 22.69
10nF | C1,C2,C4,C5,C6,C13,C14,C15 |  | C0805C103J3GECAUTO | https://www.digikey.ca/en/products/detail/kemet/C0805C103J3GECAUTO/8647361 | 0.247 | 8 | 1.976
10uF | C3,C10,C46,C47 |  | CL31B106KAHNNNE | https://www.digikey.ca/en/products/detail/murata-electronics/GRM155R71C104KA88J/2610892 | 0.15 | 4 | 0.6
 |  |  |  |  |  |  | 0
0.1uF | C7,C8,C9,C12,C17,C18,C19,C20,C21 | Murata Electronics | CC0805JRNPO9BN250,GCM155R71C104KA55J | https://www.digikey.ca/en/products/detail/murata-electronics/GCM155R71C104KA55J/2591252,https://www.digikey.ca/en/products/detail/yageo/CC0805JRNPO9BN250/5884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 | 0.043 | 9 | 0.387
100uF | C11 |  | GRM31CR61A107MEA8L | https://www.digikey.ca/en/products/detail/murata-electronics/GRM31CR61A107MEA8L/16033775 | 0.72 | 1 | 0.72
22uF | C23 | Kemet | C0805C224K5RACTU | https://www.digikey.ca/en/products/detail/kemet/C0805C224K5RACTU/754753 | 0.12 | 1 | 0.12
RGBW_LED | D1,D6,D7 | QT Brightek (QTB) | QBLP679-RGBCW | https://www.digikey.ca/en/products/detail/qt-brightek-qtb/QBLP679-RGBCW/13278847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 | 1.19 | 3 | 3.57
BLUE LED | D3 | Wurth | 150080BS75000 | https://www.digikey.ca/en/products/detail/w%C3%BCrth-elektronik/150080BS75000/4489912 | 0.3 | 1 | 0.3
RED LED | D5 | ams-OSRAM USA INC. | LS R976-NR-1-0-20-R18 | https://www.digikey.ca/en/products/detail/ams-osram-usa-inc/LS-R976-NR-1-0-20-R18/1227987 | 0.24 | 1 | 0.24
Polyfuse | F1 |  | 1206L025/24YR | https://www.digikey.ca/en/products/detail/littelfuse-inc/1206L025-24YR/14320017 | 0.85 | 1 | 0.85
Polyfuse_Small | F3 | Littelfuse Inc. | 1812L014DR | https://www.digikey.ca/en/products/detail/littelfuse-inc/1812L014DR/2023961 | 0.75 | 1 | 0.75
Fiducial | FID1,FID3 |  |  |  |  | 2 | 0
MountingHole_Pad_MP | H5,H6,H7,H8,H9 |  |  |  |  | 5 | 0
Battery connector | J1 |  | B2B-PH-K-S | https://www.digikey.ca/en/products/detail/jst-sales-america-inc/B2B-PH-K-S/926611 | 0.18 | 1 | 0.18
StrainConn | J2,J3,J4,J5,J6,J7,J8,J9 | Würth Elektronik | 6.91E+11 | https://www.digikey.ca/en/products/detail/w-rth-elektronik/691137710003/6644052?gad_source=1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 |  | 8 | 0
Jumper_3_Bridged12 | JP2 |  |  |  |  | 1 | 0
1uH | L1 | TDK Corporation | MLP2012S1R0MT0S1 | https://www.digikey.ca/en/products/detail/tdk-corporation/MLP2012S1R0MT0S1/2465121 | 0.36 | 1 | 0.36
Battery Holder | N1 | Seeed Technology Co., Ltd | 114090052 | https://www.digikey.ca/en/products/detail/seeed-technology-co-ltd/114090052/10451909 | 2.19 | 1 | 2.19
NMOS | Q3 |  | NTR4003NT3G | https://www.digikey.ca/en/products/detail/onsemi/NTR4003NT3G/1967271?gclsrc=aw.ds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 | 0.35 | 1 | 0.35
PMOS | Q4,Q6 |  | NVTR01P02LT1G | https://www.digikey.ca/en/products/detail/onsemi/NVTR01P02LT1G/5969313?gclsrc=aw.ds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 | 0.71 | 2 | 1.42
15K +-1% | R1 |  | CRG0805F15K | https://www.digikey.ca/en/products/detail/te-connectivity-passive-product/CRG0805F15K/2380847 | 0.16 | 1 | 0.16
1.5K | R2 | KOA Speer | RT0603BRC07500RL | https://www.mouser.ca/ProductDetail/KOA-Speer/RN73H1JTTD1501B25?qs=0hon8nwgHrYeDaFLswFLGw%3D%3D | 0.098 | 1 | 0.098
1.6K +-1% | R10,R12,R14,R21,R22,R23,R24,R25 | YAGEO | RC0402FR-071K6L | https://www.digikey.ca/en/products/detail/yageo/RC0402FR-071K6L/5280905 | 0.012 | 8 | 0.096
330 +-5% | R11,R13 |  | CR0805-JW-331ELF | https://www.mouser.ca/ProductDetail/Bourns/CR0805-JW-331ELF?qs=%252BcBkmVQIZ2RP8aX1cRFLQQ%3D%3D | 0.16 | 2 | 0.32
0K +-1% | R15,R30 |  | RCL06120000Z0EA | https://www.digikey.ca/en/products/detail/vishay-dale/RCL06120000Z0EA/2587612 | 0.27 | 2 | 0.54
10K +-1% | R16,R17,R20 | Bourns Inc | CR0603-FX-1002ELF | https://www.digikey.ca/en/products/detail/bourns-inc/CR0603-FX-1002ELF/3593188 | 0.16 | 3 | 0.48
3.3K +-1% | R19 |  | RC0805FR-073K3L | https://www.digikey.ca/en/products/detail/yageo/RC0805FR-073K3L/727813 | 0.16 | 1 | 0.16
 |  |  |  |  |  |  | 0
 |  |  |  |  |  |  | 0
SW_SPST_LED | SW2 |  | RR11131100-214 | https://www.mouser.ca/ProductDetail/E-Switch/RR11131100-214?qs=QtyuwXswaQjGPOeo3RY%2FxQ%3D%3D | 2.04 | 1 | 2.04
TestPoint | TP3,TP4,TP5,TP60,TP63,TP64,TP65 |  |  |  |  | 7 | 0
 |  |  |  |  |  |  | 0
MRF89XAM9AT-I/RM | U2 |  | 150-MRF89XAM9AT-I/RMDKR-ND | https://www.digikey.ca/en/products/detail/microchip-technology/MRF89XAM9AT-I-RM/10520347?productid=10520347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 | 12.7 | 1 | 12.7
ICM-45605 | U4 | TDK InvenSense | ICM-45605 | https://www.digikey.ca/en/products/detail/tdk-invensense/ICM-45605/24883424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 | 7.96 | 1 | 7.96
NCP1117LPST50T3G | U10 |  | NCP1117LPST50T3G | https://www.digikey.ca/en/products/detail/onsemi/NCP1117LPST50T3G/2194022 | 1.25 | 1 | 1.25
LP5813BDRRR | U11 | Texas Instruments | LP5813CYBHR | https://www.mouser.ca/ProductDetail/Texas-Instruments/LP5813CYBHR?qs=ST9lo4GX8V0mwdEJ9TmycA%3D%3D | 2.82 | 1 | 2.82
 |  |  |  |  |  |  | 0
 |  |  |  |  |  |  | 0
SECOND ANTENNA |  |  |  |  | 12.7 | 1 | 12.7
 |  |  |  |  |  |  | 0
0.1uF - secondPCB |  |  |  |  | 0.099 | 20 | 1.98
MAIN PCB |  |  |  |  | 75 | 1 | 75
second pcb |  |  |  |  | 5 | 1 | 5
INA317xxDGK | Uw? | Texas Instruments | INA317IDGKR | https://www.mouser.ca/ProductDetail/Texas-Instruments/INA317IDGKR?qs=W0yvOO0ixfHq371pIwwl1g%3D%3D | 2.64 | 10 | 26.4
TLV9062IDSGR | U1 |  | TLV9062IDSGR | https://www.mouser.ca/ProductDetail/Texas-Instruments/TLV9062IDSGR?qs=5aG0NVq1C4xlH6vCPIp7gg%3D%3D | 0.915 | 10 | 9.15
200K | R28 |  | AC0805FR-07200KL | https://www.mouser.ca/ProductDetail/YAGEO/AC0805FR-07200KL?qs=yhV1fb9g%2FKbw5hOmSj8rUw%3D%3D | 0.078 | 10 | 0.78
100K | R29 |  | AC0805FR-07100KL | https://www.mouser.ca/ProductDetail/YAGEO/AC0805FR-07100KL?qs=yhV1fb9g%2FKaVZiBVfcTXyg%3D%3D | 0.119 | 10 | 1.19
 |  |  |  |  |  |  | 197.527

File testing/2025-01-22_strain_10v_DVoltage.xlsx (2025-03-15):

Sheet: Analysis
Name: | 10V applied
Applied Force (lbs) | Differential Voltage (mV)
0.00 | 0.00000000
1000.00 | 4.18000000
2000.00 | 7.74000000
3000.00 | 11.36000000
4000.00 | 15.08000000
5000.00 | 18.72000000
6000.00 | 22.36000000
7000.00 | 26.12000000
8000.00 | 30.01000000
7000.00 | 27.13000000
6000.00 | 23.12000000
5000.00 | 20.06000000
4000.00 | 16.57000000
3000.00 | 12.94000000
2000.00 | 9.49000000
1000.00 | 5.22000000
0.00 | 0.70000000

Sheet: Double Analysis
Name: |  |  |  |  |  |  | 2025-03-14
First Dataset |  | Second Dataset
X Values | Y Values | X Values | Y Values |  |  |  |  | Fit Equation:
 |  |  |  |  |  |  |  | y=A+Bx+Cx²
 |  |  |  |  |  | First Dataset Fit
 |  |  |  |  |  |  | Value | Uncertainty | CD:
 |  |  |  |  |  | A
 |  |  |  |  |  | B
 |  |  |  |  |  | C
 |  |  |  | Power for fixed power fit:
 |  |  |  |  | 1 | Second Dataset Fit
 |  |  |  |  |  |  | Value | Uncertainty | CD:
 |  |  |  |  |  | A
 |  |  |  |  |  | B
 |  |  |  |  |  | C

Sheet: Comparison
Name: |  |  |  | 2025-03-14
№ | Source | Value (unit) | Uncertainty
1
2
3
4
5
6

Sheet: Manual Fitting
Name: |  |  |  |  | 2025-03-14
X Values | Y Values
 |  | Fit Type | Fit Function
 |  |  | y=A+Bx
 |  |  | Parameter | Manual Estimate |  | CD:
 |  |  | A | 0.00
 |  |  | B | 0.04

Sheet: Guts
Fit type |  |  | 8 |  |  | x-values | fit y-values | DA x-values | fit 1 y-values | fit 2 y-values | x-data | y-data | freeform y | w/ duplicates | de-duplicated | DAx1data | DAy1data | DAx2data | DAy2data | DAx1 | DAx1 order | DAy1 match | Frform DAy1 | DAx2 | DAx2 order | DAy2 match | Frform DAy2 | Fit type | 1 | m.f. x-plot | m.f. fit y | m.f. xData | m.f. yData | m.f. y fit | m.f. sq res | (y_i-y_av)^2
Last row with x data |  |  | 19 |  | 0 | 0.00 | #N/A | #N/A | #N/A | #N/A | 0 | 0.70000000 | #N/A | 0.00 | 0.00 | #N/A | #N/A | #N/A | #N/A |  | #N/A | #N/A | #N/A |  | #N/A | #N/A | #N/A | Optimize? | 1 | 0.00 | 0.00 | #N/A | #N/A | #N/A | #N/A | #N/A
Last row with y data |  |  | 19 |  | 1 | 80.00 | #N/A | #N/A | #N/A | #N/A | 0 | 0.00000000 | #N/A | 1000.00 | 1000.00 |  |  |  |  |  | #N/A | #N/A | #N/A |  | #N/A | #N/A | #N/A |  |  | 0.00 | 0.00 |  |  | 0.00 | 0 | #N/A
Last row with paired data |  |  | 19 |  | 2 | 160.00 | #N/A | #N/A | #N/A | #N/A | 1000 | 4.18000000 | #N/A | 2000.00 | 2000.00 |  |  |  |  |  | #N/A | #N/A | #N/A |  | #N/A | #N/A | #N/A |  |  | 0.00 | 0.00 |  |  | 0.00 | 0 | #N/A
First row with x data |  |  | 3 |  | 3 | 240.00 | #N/A | #N/A | #N/A | #N/A | 1000 | 4.18000000 | #N/A | 3000.00 | 3000.00 |  |  |  |  |  | #N/A | #N/A | #N/A |  | #N/A | #N/A | #N/A | linear | y=A+Bx | 0.00 | 0.00 |  |  | 0.00 | 0 | #N/A
First row with y data |  |  | 3 |  | 4 | 320.00 | #N/A | #N/A | #N/A | #N/A | 2000 | 7.74000000 | #N/A | 4000.00 | 4000.00 |  |  |  |  |  | #N/A | #N/A | #N/A |  | #N/A | #N/A | #N/A | lorentzian | y=A/(1+((x−B)/C)²) | 0.00 | 0.00 |  |  | 0.00 | 0 | #N/A
First row with paired data |  |  | 3 |  | 5 | 400.00 | #N/A | #N/A | #N/A | #N/A | 2000 | 7.74000000 | #N/A | 5000.00 | 5000.00 |  |  |  |  |  | #N/A | #N/A | #N/A |  | #N/A | #N/A | #N/A | gaussian | y=A exp(−((x−B)/C)²) | 0.00 | 0.00 |  |  | 0.00 | 0 | #N/A
 |  |  |  |  | 6 | 480.00 | #N/A | #N/A | #N/A | #N/A | 3000 | 11.36000000 | #N/A | 6000.00 | 6000.00 |  |  |  |  |  | #N/A | #N/A | #N/A |  | #N/A | #N/A | #N/A | sine | y=A sin(Bx−C)+D | 0.00 | 0.00 |  |  | 0.00 | 0 | #N/A
 |  |  |  |  | 7 | 560.00 | #N/A | #N/A | #N/A | #N/A | 3000 | 11.36000000 | #N/A | 7000.00 | 7000.00 |  |  |  |  |  | #N/A | #N/A | #N/A |  | #N/A | #N/A | #N/A |  |  | 0.00 | 0.00 |  |  | 0.00 | 0 | #N/A
Analysis fit parameters |  |  |  |  | 8 | 640.00 | #N/A | #N/A | #N/A | #N/A | 4000 | 15.08000000 | #N/A | 8000.00 | 8000.00 |  |  |  |  |  | #N/A | #N/A | #N/A |  | #N/A | #N/A | #N/A |  |  | 0.00 | 0.00 |  |  | 0.00 | 0 | #N/A
coeffs | #N/A |  |  |  | 9 | 720.00 | #N/A | #N/A | #N/A | #N/A | 4000 | 15.08000000 | #N/A | 7000.00 | 7000.00 |  |  |  |  |  | #N/A | #N/A | #N/A |  | #N/A | #N/A | #N/A | #N/A |  | 0.00 | 0.00 |  |  | 0.00 | 0 | #N/A
unc. |  |  |  |  | 10 | 800.00 | #N/A | #N/A | #N/A | #N/A | 5000 | 18.72000000 | #N/A | 6000.00 | 6000.00 |  |  |  |  |  | #N/A | #N/A | #N/A |  | #N/A | #N/A | #N/A |  |  | 0.00 | 0.00 |  |  | 0.00 | 0 | #N/A
stats |  |  |  |  | 11 | 880.00 | #N/A | #N/A | #N/A | #N/A | 5000 | 18.72000000 | #N/A | 5000.00 | 5000.00 |  |  |  |  |  | #N/A | #N/A | #N/A |  | #N/A | #N/A | #N/A |  |  | 0.00 | 0.00 |  |  | 0.00 | 0 | #N/A
 |  |  |  |  | 12 | 960.00 | #N/A | #N/A | #N/A | #N/A | 6000 | 22.36000000 | #N/A | 4000.00 | 4000.00 |  |  |  |  |  | #N/A | #N/A | #N/A |  | #N/A | #N/A | #N/A | guessed | solved | 0.00 | 0.00 |  |  | 0.00 | 0 | #N/A
 |  |  |  |  | 13 | 1040.00 | #N/A | #N/A | #N/A | #N/A | 6000 | 22.36000000 | #N/A | 3000.00 | 3000.00 |  |  |  |  |  | #N/A | #N/A | #N/A |  | #N/A | #N/A | #N/A | 0.00 | 6264.798219 | 0.00 | 0.00 |  |  | 0.00 | 0 | #N/A
 |  |  |  |  | 14 | 1120.00 | #N/A | #N/A | #N/A | #N/A | 7000 | 26.12000000 | #N/A | 2000.00 | 2000.00 |  |  |  |  |  | #N/A | #N/A | #N/A |  | #N/A | #N/A | #N/A | 0.04 | 10.46591908 | 0.00 | 0.00 |  |  | 0.00 | 0 | #N/A
 |  |  |  |  | 15 | 1200.00 | #N/A | #N/A | #N/A | #N/A | 7000 | 26.12000000 | #N/A | 1000.00 | 1000.00 |  |  |  |  |  | #N/A | #N/A | #N/A |  | #N/A | #N/A | #N/A | #N/A | 0.3820246435 | 0.00 | 0.00 |  |  | 0.00 | 0 | #N/A
 |  |  |  |  | 16 | 1280.00 | #N/A | #N/A | #N/A | #N/A | 8000 | 30.01000000 | #N/A | 0.00 | 0.00 |  |  |  |  |  | #N/A | #N/A | #N/A |  | #N/A | #N/A | #N/A | #N/A | #N/A | 0.00 | 0.00 |  |  | 0.00 | 0 | #N/A
 |  |  |  |  | 17 | 1360.00 | #N/A | #N/A | #N/A | #N/A | #N/A | #N/A | #N/A |  |  |  |  |  |  |  | #N/A | #N/A | #N/A |  | #N/A | #N/A | #N/A |  |  | 0.00 | 0.00 |  |  | 0.00 | 0 | #N/A
 |  |  |  |  | 18 | 1440.00 | #N/A | #N/A | #N/A | #N/A | #N/A | #N/A | #N/A |  |  |  |  |  |  |  | #N/A | #N/A | #N/A |  | #N/A | #N/A | #N/A |  |  | 0.00 | 0.00 |  |  | 0.00 | 0 | #N/A
 |  | Fits available |  |  | 19 | 1520.00 | #N/A | #N/A | #N/A | #N/A | #N/A | #N/A | #N/A |  |  |  |  |  |  |  | #N/A | #N/A | #N/A |  | #N/A | #N/A | #N/A |  |  | 0.00 | 0.00 |  |  | 0.00 | 0 | #N/A
 | 1 | y=A+Bx |  |  | 20 | 1600.00 | #N/A | #N/A | #N/A | #N/A | #N/A | #N/A | #N/A |  |  |  |  |  |  |  | #N/A | #N/A | #N/A |  | #N/A | #N/A | #N/A |  | #N/A | 0.00 | 0.00 |  |  | 0.00 | 0 | #N/A
 | 2 | #REF! |  | y=A | 21 | 1680.00 | #N/A | #N/A | #N/A | #N/A | #N/A | #N/A | #N/A |  |  |  |  |  |  |  | #N/A | #N/A | #N/A |  | #N/A | #N/A | #N/A |  |  | 0.00 | 0.00 |  |  | 0.00 | 0 | #N/A
 | 3 | y=A+Bx+Cx² |  | y=Bx | 22 | 1760.00 | #N/A | #N/A | #N/A | #N/A | #N/A | #N/A | #N/A |  |  |  |  |  |  |  | #N/A | #N/A | #N/A |  | #N/A | #N/A | #N/A |  |  | 0.00 | 0.00 |  |  | 0.00 | 0 | #N/A
 | 4 | y=A+Bx+Cx²+Dx³ |  | y=Cx² | 23 | 1840.00 | #N/A | #N/A | #N/A | #N/A | #N/A | #N/A | #N/A |  |  |  |  |  |  |  | #N/A | #N/A | #N/A |  | #N/A | #N/A | #N/A |  |  | 0.00 | 0.00 |  |  | 0.00 | 0 | #N/A
 | 5 | y=Axᴮ |  | y=Dx³ | 24 | 1920.00 | #N/A | #N/A | #N/A | #N/A | #N/A | #N/A | #N/A |  |  |  |  |  |  |  | #N/A | #N/A | #N/A |  | #N/A | #N/A | #N/A |  |  | 0.00 | 0.00 |  |  | 0.00 | 0 | #N/A
 | 6 | y=Aeᴮˣ |  | y=Ex⁴ | 25 | 2000.00 | #N/A | #N/A | #N/A | #N/A | #N/A | #N/A | #N/A |  |  |  |  |  |  |  | #N/A | #N/A | #N/A |  | #N/A | #N/A | #N/A |  |  | 0.00 | 0.00 |  |  | 0.00 | 0 | #N/A
 | 7 | No fitting |  |  | 26 | 2080.00 | #N/A | #N/A | #N/A | #N/A | #N/A | #N/A | #N/A |  |  |  |  |  |  |  | #N/A | #N/A | #N/A |  | #N/A | #N/A | #N/A |  |  | 0.00 | 0.00 |  |  | 0.00 | 0 | #N/A
 | 8 | No fitting |  |  | 27 | 2160.00 | #N/A | #N/A | #N/A | #N/A | #N/A | #N/A | #N/A |  |  |  |  |  |  |  | #N/A | #N/A | #N/A |  | #N/A | #N/A | #N/A |  |  | 0.00 | 0.00 |  |  | 0.00 | 0 | #N/A
 |  |  |  |  | 28 | 2240.00 | #N/A | #N/A | #N/A | #N/A | #N/A | #N/A | #N/A |  |  |  |  |  |  |  | #N/A | #N/A | #N/A |  | #N/A | #N/A | #N/A |  |  | 0.00 | 0.00 |  |  | 0.00 | 0 | #N/A
 | Double Fit Info |  |  |  | 29 | 2320.00 | #N/A | #N/A | #N/A | #N/A | #N/A | #N/A | #N/A |  |  |  |  |  |  |  | #N/A | #N/A | #N/A |  | #N/A | #N/A | #N/A |  |  | 0.00 | 0.00 |  |  | 0.00 | 0 | #N/A
Fit type |  |  | 2 |  | 30 | 2400.00 | #N/A | #N/A | #N/A | #N/A | #N/A | #N/A | #N/A |  |  |  |  |  |  |  | #N/A | #N/A | #N/A |  | #N/A | #N/A | #N/A |  |  | 0.00 | 0.00 |  |  | 0.00 | 0 | #N/A
Last row with x1 data |  |  | #N/A |  | 31 | 2480.00 | #N/A | #N/A | #N/A | #N/A | #N/A | #N/A | #N/A |  |  |  |  |  |  |  | #N/A | #N/A | #N/A |  | #N/A | #N/A | #N/A |  |  | 0.00 | 0.00 |  |  | 0.00 | 0 | #N/A
Last row with y1 data |  |  | #N/A |  | 32 | 2560.00 | #N/A | #N/A | #N/A | #N/A | #N/A | #N/A | #N/A |  |  |  |  |  |  |  | #N/A | #N/A | #N/A |  | #N/A | #N/A | #N/A |  |  | 0.00 | 0.00 |  |  | 0.00 | 0 | #N/A
Last row with paired 1st set data |  |  | #N/A |  | 33 | 2640.00 | #N/A | #N/A | #N/A | #N/A | #N/A | #N/A | #N/A |  |  |  |  |  |  |  | #N/A | #N/A | #N/A |  | #N/A | #N/A | #N/A |  |  | 0.00 | 0.00 |  |  | 0.00 | 0 | #N/A
First row with x1 data |  |  | #N/A |  | 34 | 2720.00 | #N/A | #N/A | #N/A | #N/A | #N/A | #N/A | #N/A |  |  |  |  |  |  |  | #N/A | #N/A | #N/A |  | #N/A | #N/A | #N/A |  |  | 0.00 | 0.00 |  |  | 0.00 | 0 | #N/A
First row with y1 data |  |  | #N/A |  | 35 | 2800.00 | #N/A | #N/A | #N/A | #N/A | #N/A | #N/A | #N/A |  |  |  |  |  |  |  | #N/A | #N/A | #N/A |  | #N/A | #N/A | #N/A |  |  | 0.00 | 0.00 |  |  | 0.00 | 0 | #N/A
First row with paired 1st set data |  |  | #N/A |  | 36 | 2880.00 | #N/A | #N/A | #N/A | #N/A | #N/A | #N/A | #N/A |  |  |  |  |  |  |  | #N/A | #N/A | #N/A |  | #N/A | #N/A | #N/A |  |  | 0.00 | 0.00 |  |  | 0.00 | 0 | #N/A
Last row with x2 data |  |  | #N/A |  | 37 | 2960.00 | #N/A | #N/A | #N/A | #N/A | #N/A | #N/A | #N/A |  |  |  |  |  |  |  | #N/A | #N/A | #N/A |  | #N/A | #N/A | #N/A |  |  | 0.00 | 0.00 |  |  | 0.00 | 0 | #N/A
Last row with y2 data |  |  | #N/A |  | 38 | 3040.00 | #N/A | #N/A | #N/A | #N/A | #N/A | #N/A | #N/A |  |  |  |  |  |  |  | #N/A | #N/A | #N/A |  | #N/A | #N/A | #N/A |  |  | 0.00 | 0.00 |  |  | 0.00 | 0 | #N/A
Last row with paired 2nd set data |  |  | #N/A |  | 39 | 3120.00 | #N/A | #N/A | #N/A | #N/A | #N/A | #N/A | #N/A |  |  |  |  |  |  |  | #N/A | #N/A | #N/A |  | #N/A | #N/A | #N/A |  |  | 0.00 | 0.00 |  |  | 0.00 | 0 | #N/A
First row with x2 data |  |  | #N/A |  | 40 | 3200.00 | #N/A | #N/A | #N/A | #N/A | #N/A | #N/A | #N/A |  |  |  |  |  |  |  | #N/A | #N/A | #N/A |  | #N/A | #N/A | #N/A |  |  | 0.00 | 0.00 |  |  | 0.00 | 0 | #N/A
First row with y2 data |  |  | #N/A |  | 41 | 3280.00 | #N/A | #N/A | #N/A | #N/A | #N/A | #N/A | #N/A |  |  |  |  |  |  |  | #N/A | #N/A | #N/A |  | #N/A | #N/A | #N/A |  |  | 0.00 | 0.00 |  |  | 0.00 | 0 | #N/A
First row with paired 2nd set data |  |  | #N/A |  | 42 | 3360.00 | #N/A | #N/A | #N/A | #N/A | #N/A | #N/A | #N/A |  |  |  |  |  |  |  | #N/A | #N/A | #N/A |  | #N/A | #N/A | #N/A |  |  | 0.00 | 0.00 |  |  | 0.00 | 0 | #N/A
 |  |  |  |  | 43 | 3440.00 | #N/A | #N/A | #N/A | #N/A | #N/A | #N/A | #N/A |  |  |  |  |  |  |  | #N/A | #N/A | #N/A |  | #N/A | #N/A | #N/A |  |  | 0.00 | 0.00 |  |  | 0.00 | 0 | #N/A
 |  |  |  |  | 44 | 3520.00 | #N/A | #N/A | #N/A | #N/A | #N/A | #N/A | #N/A |  |  |  |  |  |  |  | #N/A | #N/A | #N/A |  | #N/A | #N/A | #N/A |  |  | 0.00 | 0.00 |  |  | 0.00 | 0 | #N/A
fit for the first dataset |  |  |  |  | 45 | 3600.00 | #N/A | #N/A | #N/A | #N/A | #N/A | #N/A | #N/A |  |  |  |  |  |  |  | #N/A | #N/A | #N/A |  | #N/A | #N/A | #N/A |  |  | 0.00 | 0.00 |  |  | 0.00 | 0 | #N/A
coeffs | #N/A |  |  |  | 46 | 3680.00 | #N/A | #N/A | #N/A | #N/A | #N/A | #N/A | #N/A |  |  |  |  |  |  |  | #N/A | #N/A | #N/A |  | #N/A | #N/A | #N/A |  |  | 0.00 | 0.00 |  |  | 0.00 | 0 | #N/A
unc. |  |  |  |  | 47 | 3760.00 | #N/A | #N/A | #N/A | #N/A | #N/A | #N/A | #N/A |  |  |  |  |  |  |  | #N/A | #N/A | #N/A |  | #N/A | #N/A | #N/A |  |  | 0.00 | 0.00 |  |  | 0.00 | 0 | #N/A
stats |  |  |  |  | 48 | 3840.00 | #N/A | #N/A | #N/A | #N/A | #N/A | #N/A | #N/A |  |  |  |  |  |  |  | #N/A | #N/A | #N/A |  | #N/A | #N/A | #N/A |  |  | 0.00 | 0.00 |  |  | 0.00 | 0 | #N/A
 |  |  |  |  | 49 | 3920.00 | #N/A | #N/A | #N/A | #N/A | #N/A | #N/A | #N/A |  |  |  |  |  |  |  | #N/A | #N/A | #N/A |  | #N/A | #N/A | #N/A |  |  | 0.00 | 0.00 |  |  | 0.00 | 0 | #N/A
 |  |  |  |  | 50 | 4000.00 | #N/A | #N/A | #N/A | #N/A | #N/A | #N/A | #N/A |  |  |  |  |  |  |  | #N/A | #N/A | #N/A |  | #N/A | #N/A | #N/A |  |  | 0.00 | 0.00 |  |  | 0.00 | 0 | #N/A
fit for the second dataset |  |  |  |  | 51 | 4080.00 | #N/A | #N/A | #N/A | #N/A | #N/A | #N/A | #N/A |  |  |  |  |  |  |  | #N/A | #N/A | #N/A |  | #N/A | #N/A | #N/A |  |  | 0.00 | 0.00 |  |  | 0.00 | 0 | #N/A
coeffs | #N/A |  |  |  | 52 | 4160.00 | #N/A | #N/A | #N/A | #N/A | #N/A | #N/A | #N/A |  |  |  |  |  |  |  | #N/A | #N/A | #N/A |  | #N/A | #N/A | #N/A |  |  | 0.00 | 0.00 |  |  | 0.00 | 0 | #N/A
unc. |  |  |  |  | 53 | 4240.00 | #N/A | #N/A | #N/A | #N/A | #N/A | #N/A | #N/A |  |  |  |  |  |  |  | #N/A | #N/A | #N/A |  | #N/A | #N/A | #N/A |  |  | 0.00 | 0.00 |  |  | 0.00 | 0 | #N/A
stats |  |  |  |  | 54 | 4320.00 | #N/A | #N/A | #N/A | #N/A | #N/A | #N/A | #N/A |  |  |  |  |  |  |  | #N/A | #N/A | #N/A |  | #N/A | #N/A | #N/A |  |  | 0.00 | 0.00 |  |  | 0.00 | 0 | #N/A
 |  |  |  |  | 55 | 4400.00 | #N/A | #N/A | #N/A | #N/A | #N/A | #N/A | #N/A |  |  |  |  |  |  |  | #N/A | #N/A | #N/A |  | #N/A | #N/A | #N/A |  |  | 0.00 | 0.00 |  |  | 0.00 | 0 | #N/A
 |  |  |  |  | 56 | 4480.00 | #N/A | #N/A | #N/A | #N/A | #N/A | #N/A | #N/A |  |  |  |  |  |  |  | #N/A | #N/A | #N/A |  | #N/A | #N/A | #N/A |  |  | 0.00 | 0.00 |  |  | 0.00 | 0 | #N/A
Final row with data in x-data column (N) |  |  |  |  | 57 | 4560.00 | #N/A | #N/A | #N/A | #N/A | #N/A | #N/A | #N/A |  |  |  |  |  |  |  | #N/A | #N/A | #N/A |  | #N/A | #N/A | #N/A |  |  | 0.00 | 0.00 |  |  | 0.00 | 0 | #N/A
18 |  |  |  |  | 58 | 4640.00 | #N/A | #N/A | #N/A | #N/A | #N/A | #N/A | #N/A |  |  |  |  |  |  |  | #N/A | #N/A | #N/A |  | #N/A | #N/A | #N/A |  |  | 0.00 | 0.00 |  |  | 0.00 | 0 | #N/A
 |  |  |  |  | 59 | 4720.00 | #N/A | #N/A | #N/A | #N/A | #N/A | #N/A | #N/A |  |  |  |  |  |  |  | #N/A | #N/A | #N/A |  | #N/A | #N/A | #N/A |  |  | 0.00 | 0.00 |  |  | 0.00 | 0 | #N/A
 | Manual fit info |  |  |  | 60 | 4800.00 | #N/A | #N/A | #N/A | #N/A | #N/A | #N/A | #N/A |  |  |  |  |  |  |  | #N/A | #N/A | #N/A |  | #N/A | #N/A | #N/A |  |  | 0.00 | 0.00 |  |  | 0.00 | 0 | #N/A
Last row with x data |  |  | #N/A |  | 61 | 4880.00 | #N/A | #N/A | #N/A | #N/A | #N/A | #N/A | #N/A |  |  |  |  |  |  |  | #N/A | #N/A | #N/A |  | #N/A | #N/A | #N/A |  |  | 0.00 | 0.00 |  |  | 0.00 | 0 | #N/A
Last row with y data |  |  | #N/A |  | 62 | 4960.00 | #N/A | #N/A | #N/A | #N/A | #N/A | #N/A | #N/A |  |  |  |  |  |  |  | #N/A | #N/A | #N/A |  | #N/A | #N/A | #N/A |  |  | 0.00 | 0.00 |  |  | 0.00 | 0 | #N/A
Last row with paired data |  |  | #N/A |  | 63 | 5040.00 | #N/A | #N/A | #N/A | #N/A | #N/A | #N/A | #N/A |  |  |  |  |  |  |  | #N/A | #N/A | #N/A |  | #N/A | #N/A | #N/A |  |  | 0.00 | 0.00 |  |  | 0.00 | 0 | #N/A
First row with x data |  |  | #N/A |  | 64 | 5120.00 | #N/A | #N/A | #N/A | #N/A | #N/A | #N/A | #N/A |  |  |  |  |  |  |  | #N/A | #N/A | #N/A |  | #N/A | #N/A | #N/A |  |  | 0.00 | 0.00 |  |  | 0.00 | 0 | #N/A
First row with y data |  |  | #N/A |  | 65 | 5200.00 | #N/A | #N/A | #N/A | #N/A | #N/A | #N/A | #N/A |  |  |  |  |  |  |  | #N/A | #N/A | #N/A |  | #N/A | #N/A | #N/A |  |  | 0.00 | 0.00 |  |  | 0.00 | 0 | #N/A
First row with paired data |  |  | #N/A |  | 66 | 5280.00 | #N/A | #N/A | #N/A | #N/A | #N/A | #N/A | #N/A |  |  |  |  |  |  |  | #N/A | #N/A | #N/A |  | #N/A | #N/A | #N/A |  |  | 0.00 | 0.00 |  |  | 0.00 | 0 | #N/A
 |  |  |  |  | 67 | 5360.00 | #N/A | #N/A | #N/A | #N/A | #N/A | #N/A | #N/A |  |  |  |  |  |  |  | #N/A | #N/A | #N/A |  | #N/A | #N/A | #N/A |  |  | 0.00 | 0.00 |  |  | 0.00 | 0 | #N/A
 |  |  |  |  | 68 | 5440.00 | #N/A | #N/A | #N/A | #N/A | #N/A | #N/A | #N/A |  |  |  |  |  |  |  | #N/A | #N/A | #N/A |  | #N/A | #N/A | #N/A |  |  | 0.00 | 0.00 |  |  | 0.00 | 0 | #N/A
 |  |  |  |  | 69 | 5520.00 | #N/A | #N/A | #N/A | #N/A | #N/A | #N/A | #N/A |  |  |  |  |  |  |  | #N/A | #N/A | #N/A |  | #N/A | #N/A | #N/A |  |  | 0.00 | 0.00 |  |  | 0.00 | 0 | #N/A
 |  |  |  |  | 70 | 5600.00 | #N/A | #N/A | #N/A | #N/A | #N/A | #N/A | #N/A |  |  |  |  |  |  |  | #N/A | #N/A | #N/A |  | #N/A | #N/A | #N/A |  |  | 0.00 | 0.00 |  |  | 0.00 | 0 | #N/A
 |  |  |  |  | 71 | 5680.00 | #N/A | #N/A | #N/A | #N/A | #N/A | #N/A | #N/A |  |  |  |  |  |  |  | #N/A | #N/A | #N/A |  | #N/A | #N/A | #N/A |  |  | 0.00 | 0.00 |  |  | 0.00 | 0 | #N/A
 |  |  |  |  | 72 | 5760.00 | #N/A | #N/A | #N/A | #N/A | #N/A | #N/A | #N/A |  |  |  |  |  |  |  | #N/A | #N/A | #N/A |  | #N/A | #N/A | #N/A |  |  | 0.00 | 0.00 |  |  | 0.00 | 0 | #N/A
 |  |  |  |  | 73 | 5840.00 | #N/A | #N/A | #N/A | #N/A | #N/A | #N/A | #N/A |  |  |  |  |  |  |  | #N/A | #N/A | #N/A |  | #N/A | #N/A | #N/A |  |  | 0.00 | 0.00 |  |  | 0.00 | 0 | #N/A
 |  |  |  |  | 74 | 5920.00 | #N/A | #N/A | #N/A | #N/A | #N/A | #N/A | #N/A |  |  |  |  |  |  |  | #N/A | #N/A | #N/A |  | #N/A | #N/A | #N/A |  |  | 0.00 | 0.00 |  |  | 0.00 | 0 | #N/A
 |  |  |  |  | 75 | 6000.00 | #N/A | #N/A | #N/A | #N/A | #N/A | #N/A | #N/A |  |  |  |  |  |  |  | #N/A | #N/A | #N/A |  | #N/A | #N/A | #N/A |  |  | 0.00 | 0.00 |  |  | 0.00 | 0 | #N/A
 |  |  |  |  | 76 | 6080.00 | #N/A | #N/A | #N/A | #N/A | #N/A | #N/A | #N/A |  |  |  |  |  |  |  | #N/A | #N/A | #N/A |  | #N/A | #N/A | #N/A |  |  | 0.00 | 0.00 |  |  | 0.00 | 0 | #N/A
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

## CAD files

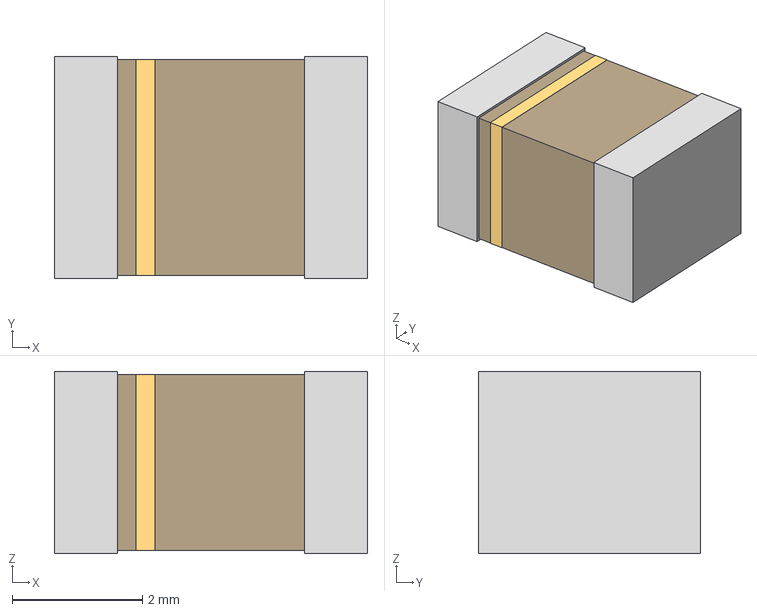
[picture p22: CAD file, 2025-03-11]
Hardware/Revision01/kicadImports/18123D106KAT2A-10uF-BC/CAP_1812Z_AVX.step
4.80 x 3.40 x 2.79 mm

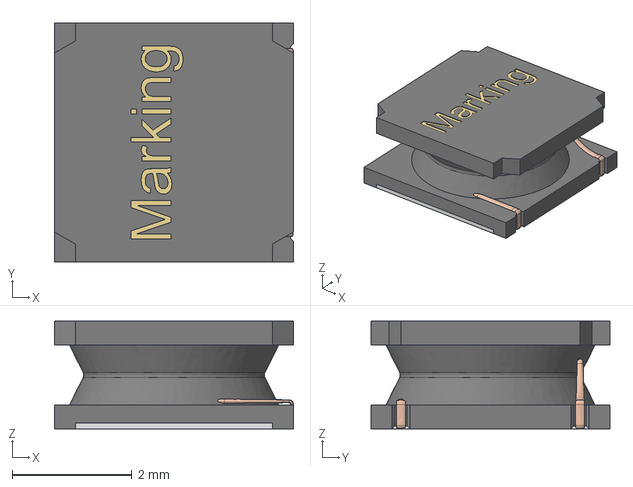
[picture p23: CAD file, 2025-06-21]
Hardware/Revision01/kicadImports/74404042151/WE-LQS_4018.step
4.00 x 4.00 x 1.80 mm

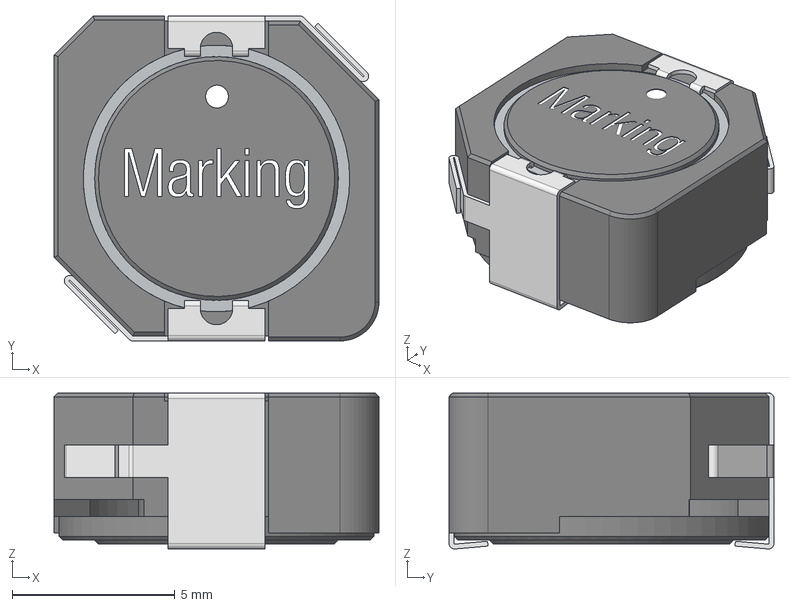
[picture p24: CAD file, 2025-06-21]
Hardware/Revision01/kicadImports/7447714221/Download_7447714xx.stp_rev1.stp
10.0 x 10.0 x 4.80 mm
shielding ring
core
base x 2
glue

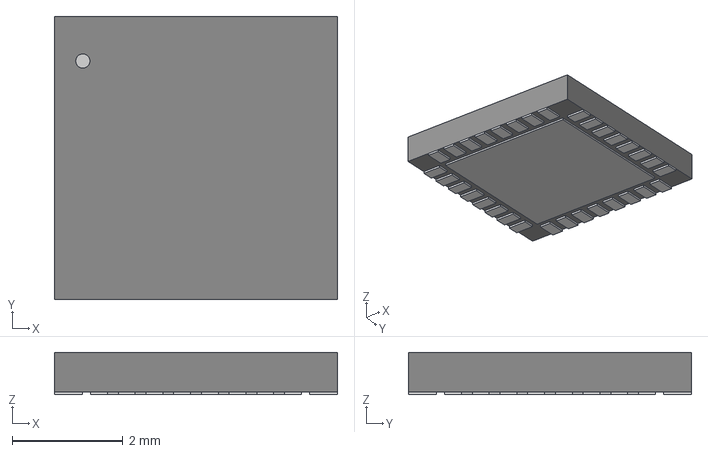
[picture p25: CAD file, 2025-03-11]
Hardware/Revision01/kicadImports/AD7124-8BCPZ-RL7-adc/CP-32-12_ADI.step
5.11 x 5.11 x 0.765 mm

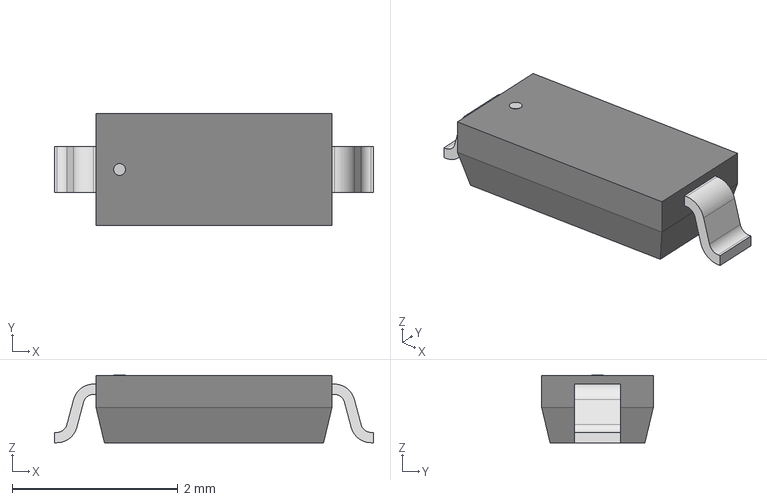
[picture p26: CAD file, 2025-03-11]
Hardware/Revision01/kicadImports/B0530W-7-F-BC-DIODE/SOD123_DIO.step
3.85 x 1.35 x 0.815 mm

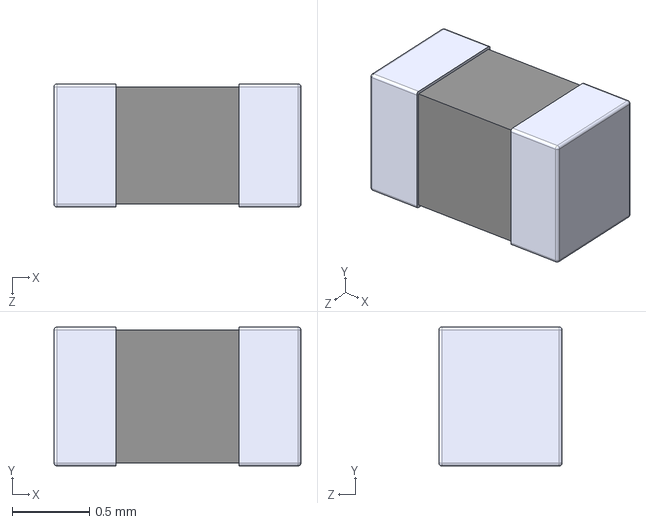
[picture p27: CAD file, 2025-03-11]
Hardware/Revision01/kicadImports/CC0603KRX7R7BB104-Gyro0.1uF/CC0603KRX7R7BB104.step
1.60 x 0.9 x 0.8 mm

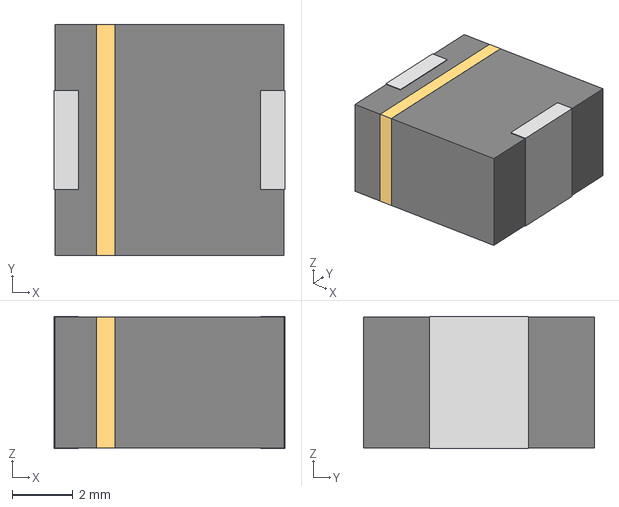
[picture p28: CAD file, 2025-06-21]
Hardware/Revision01/kicadImports/DRA74-151-R/IND_CB_DRA74.step
7.59 x 7.60 x 4.34 mm

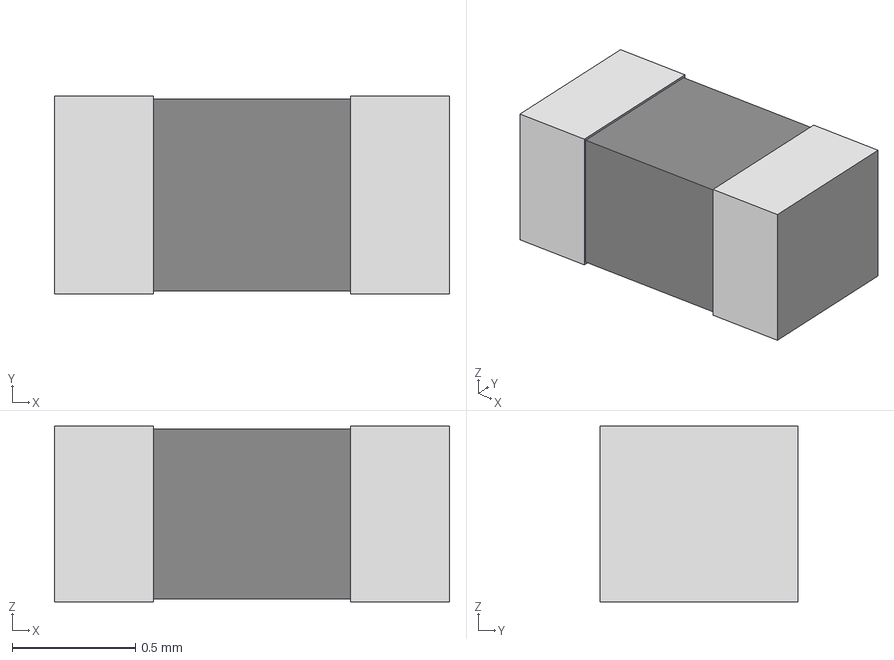
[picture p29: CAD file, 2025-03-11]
Hardware/Revision01/kicadImports/ERJ-3EKF1002V-10k-PU/RC0603N_PAN.step
1.60 x 0.8 x 0.711 mm

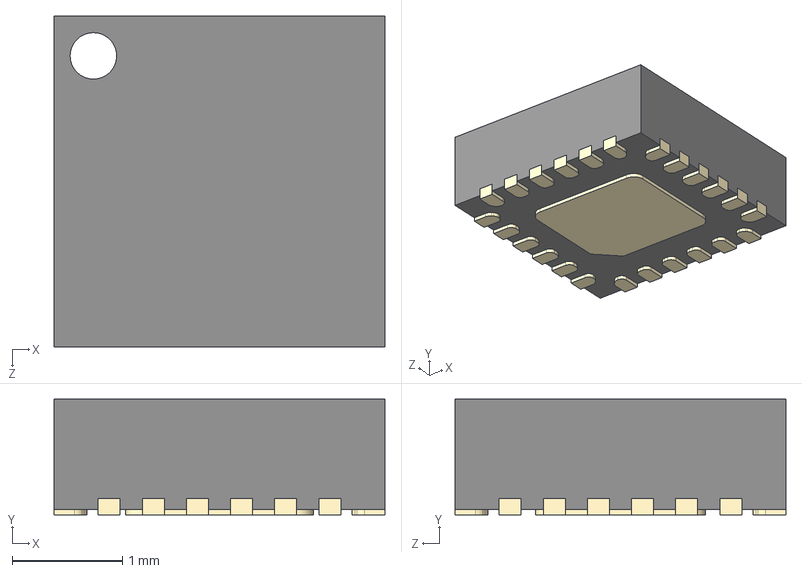
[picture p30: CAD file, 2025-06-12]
Hardware/Revision01/kicadImports/ICM-20948/ICM-20948.step
3.00 x 1.05 x 3.00 mm

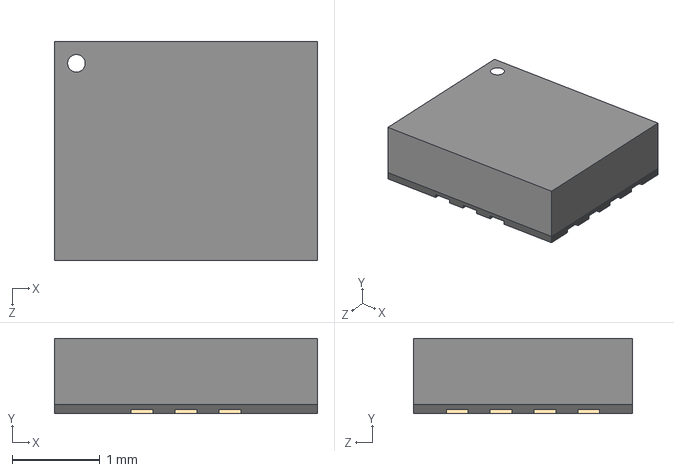
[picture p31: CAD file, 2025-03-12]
Hardware/Revision01/kicadImports/ICM-45605-gyroscope/ICM-45605.step
3.00 x 0.86 x 2.50 mm

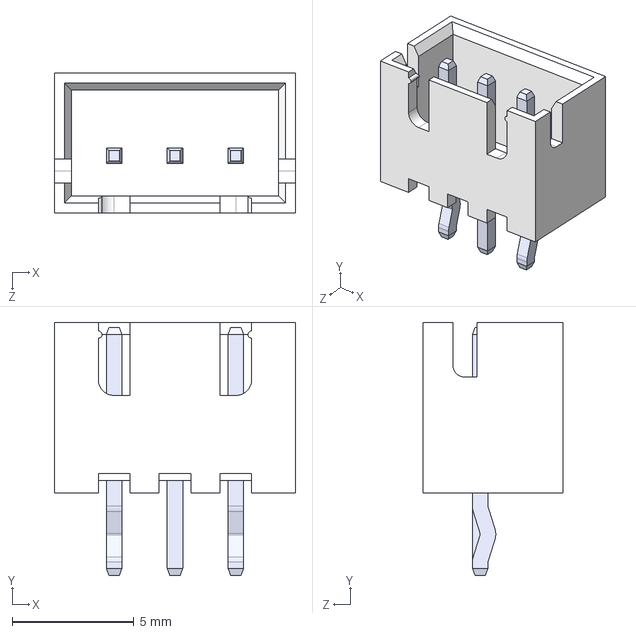
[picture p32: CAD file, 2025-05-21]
Hardware/Revision01/kicadImports/JST_B3B_XH_A/B3B-XH-A.step
9.90 x 10.4 x 5.75 mm

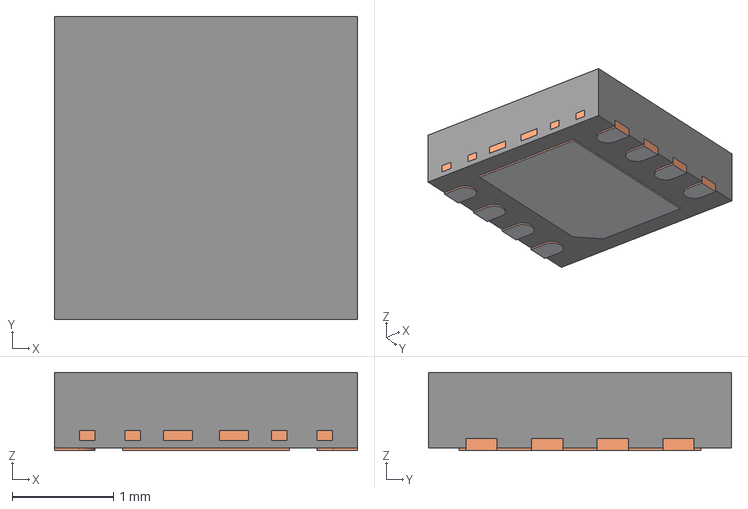
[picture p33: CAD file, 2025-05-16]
Hardware/Revision01/kicadImports/LP5812ADSDR/DSD0008B.stp
3.00 x 3.00 x 0.775 mm
BODY-SON
FRAME-DSD0008B

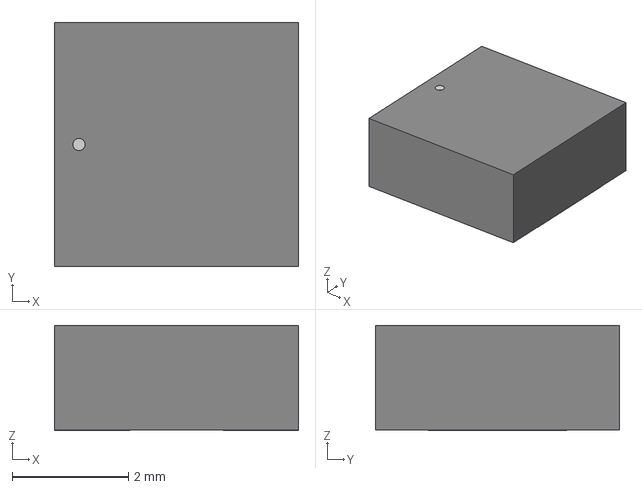
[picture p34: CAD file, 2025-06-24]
Hardware/Revision01/kicadImports/LQH44PH151MPRL/IND_LQH44PN_PR_MUR.step
4.19 x 4.19 x 1.81 mm

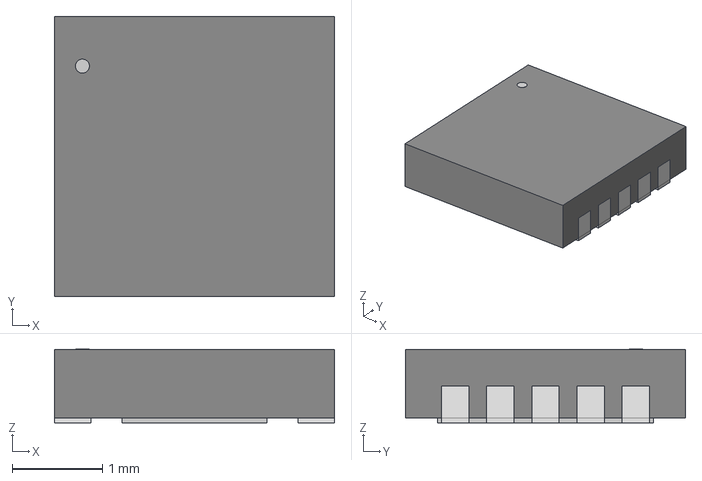
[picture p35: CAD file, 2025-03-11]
Hardware/Revision01/kicadImports/MAX1837ETT50_T-bc-5V/21-0137I_T1033-1_MXM.step
3.10 x 3.10 x 0.815 mm

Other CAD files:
Hardware/Revision01/kicadImports/ERJ_3EKF3322V -33.2K_VoltageDivider/RC0603N_PAN.step
Hardware/Revision01/kicadImports/IND_CB_DRA74.step
Hardware/Revision01/kicadImports/MIC5225-1.8YM5-TR/SOT-23-5_M5_MCH.step
Hardware/Revision01/kicadImports/MPU6500/MPU-6500.step
Hardware/Revision01/kicadImports/691137710003/691137710003.step
Hardware/Revision01/kicadImports/691137710004/691137710004.step
Hardware/Revision01/kicadImports/NCP1117LPST50T3G/NCP1117LPST50T3G.step
Hardware/Revision01/kicadImports/New folder/SOT-23-5_M5_MCH.step
Hardware/Revision01/kicadImports/OSFW4BS8C1A/OSFW4BS8C1A (3)/OSFW4BS8C1A.step
Hardware/Revision01/kicadImports/OSFW4BS8C1A/OSFW4BS8C1A.step
Hardware/Revision01/kicadImports/OSFW4BS8C1A/QBLP679-RGBXW.iges
Hardware/Revision01/kicadImports/OSFW4BS8C1A/QBLP679-RGBXW.step
Hardware/Revision01/kicadImports/SOT-23-5_M5_MCH.step
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

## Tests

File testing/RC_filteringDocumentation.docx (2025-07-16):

# Why do we need HARDWARE filtering, can we not do this digitally?

Aliasing - Aliasing happens when you sample a signal too slowly, and high-frequency components of the signal "disguise" themselves as lower frequencies. The ADC misinterprets those high frequencies as something else.

This will be useful for reducing effects of EMI from buck-converter as well.

We are sampling at 1KHz, this means we need to filter frequencies above 500 Hz due to Nyquist theorem. f_s >2f_(max) to avoid aliasing.

f_s =1K Hz

500>f_(max)

Choose f_c ≤300Hz

f_c = 1/(2πRC)

This gives us R =5.3K, C = 100nF

I round R ≅5K

So overall, anything around 300Hz+ frequency will get filtered out

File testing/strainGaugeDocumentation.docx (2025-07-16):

PMOS CALCULATIONS

NOTE: Calculations were performed assuming ALL strain gauges are connected. The resistance changes as strain Gauges are disconnected. Though it should be fine if we disconnect some.

For a PMOS

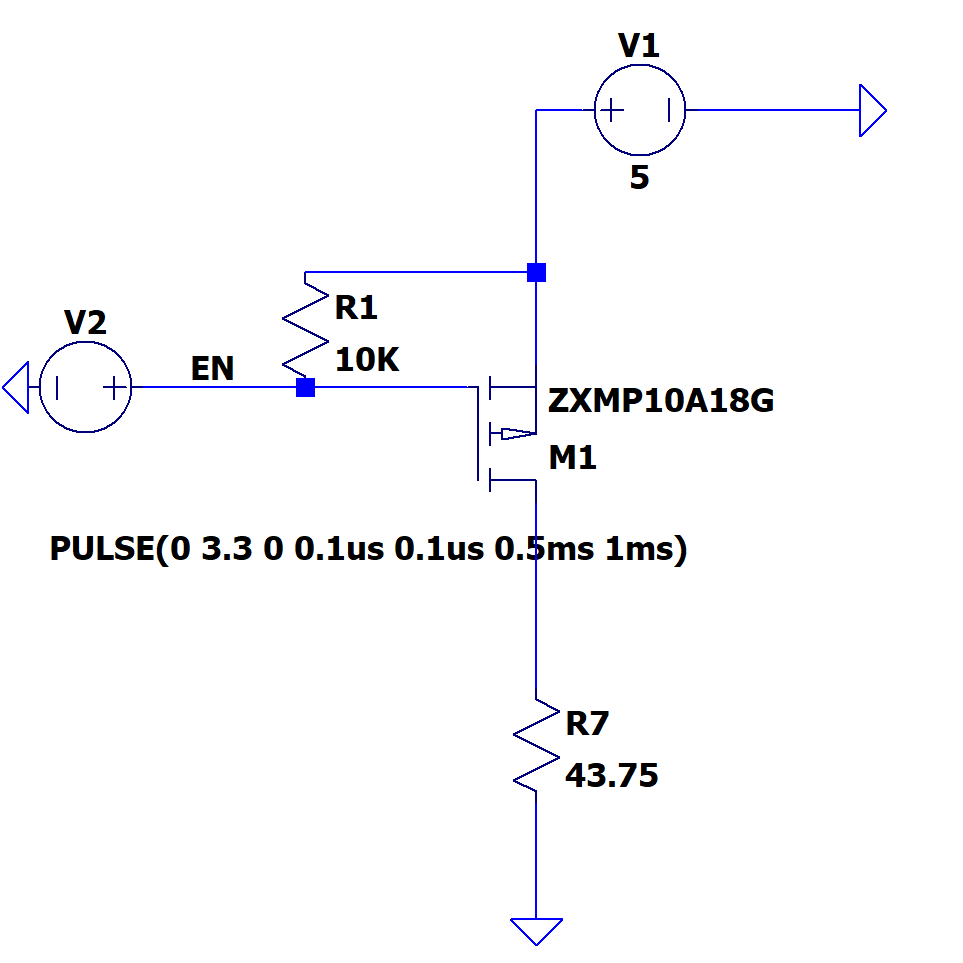
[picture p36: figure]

Figure 1 Similar model was run in stimulation, however not the same as what we choose

CUTOFF REGION: V_(sg) <V_(th_min)

5-3.3<2V

1.7<2V

YES IT can turn off

TRIODE REGION: (FULLY ON)

V_(sg) >V_(th_max)

5 > 4

V_(sd) <V_(sg) -|V_(th_max) |

ASSUME IN TRIODE REGION

Our V_(gs) =-5V when turned on so we can assume R_(ds) ≅1.5Ω

The unknown is V_d

i_d =(5V)/(1.5Ω+43.75Ω)=110mA

V_d =43.75*110mA=4.8125

V_(sd) =5-4.8125=0.1875V

V_(sd) <V_(sg) -|V_(th_max) |

0.1875<5-4

0.1875<1

Very ON!

# Bypass capacitor calculations as PMOS switches 1KHz. Check LTSPICE documentation for more indepth stimulation

I_load = 114mA

Delta T = 0.5ms

Delta V = 0.5V <- just setting it as such

I = C dV/dT

C = I * dT/dV

C = 114mA * 0.5ms / 0.5

= 114 uF ~= 100uF

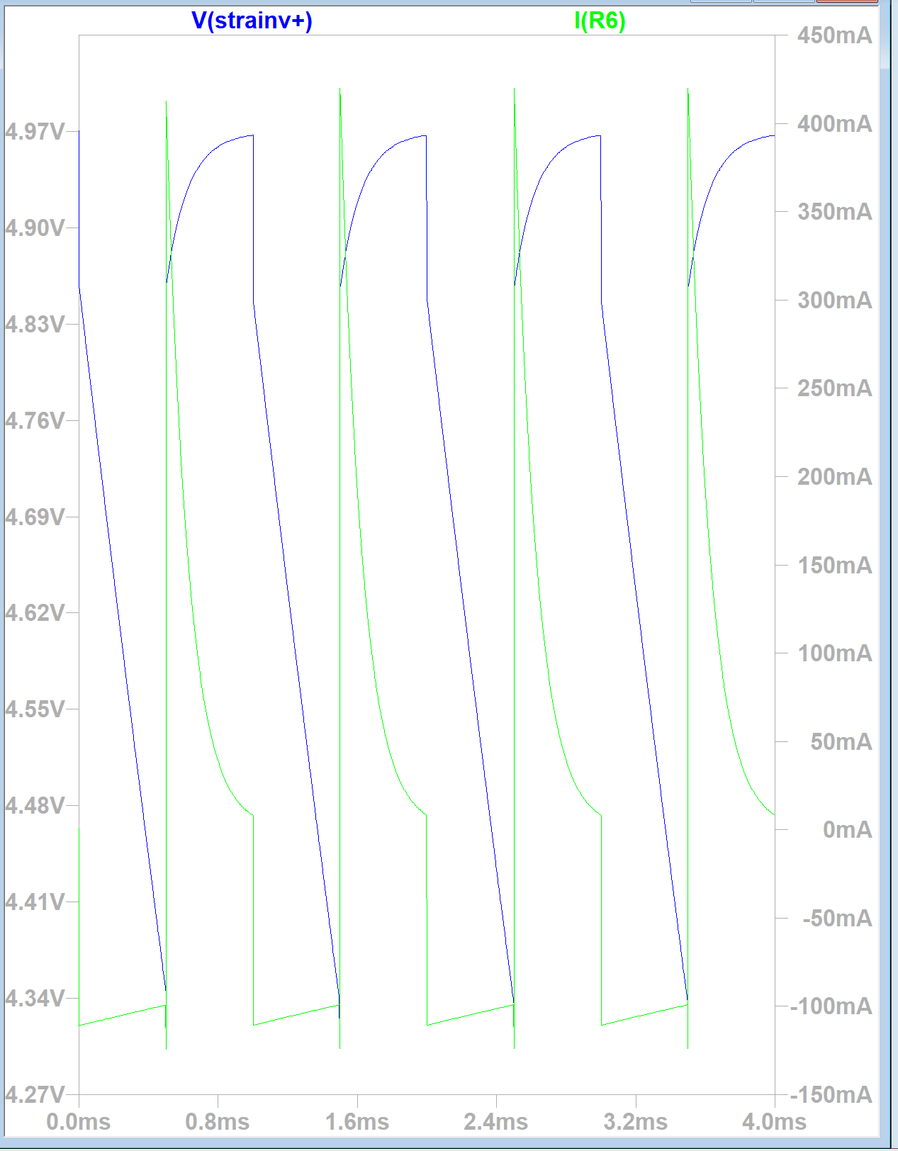
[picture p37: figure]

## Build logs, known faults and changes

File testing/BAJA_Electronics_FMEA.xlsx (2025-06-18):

Item | Function | Failure Mode | Failure Effect | Severity | Cause | Occurrence | Current Controls | Detection | RPN | Recommended Action
5V Voltage Regulator | Overheating / thermal shutdown | other components get overly heated | Components break due to excessive heat | 10 | inefficient use of power | 8 | none | 10 | 800 | STM32 nucleo has built-in temperature sensor Or we can use a buck-convertor to not lose heat.
Strain Gauge Wiring | Transmit strain signal | Open circuit or noise pickup | Incorrect strain readings | 7 | Connector failure, EMI, vibration | 3 | amplifier board | 6 | 168
Amplifier board | Amplifies small signal of strain | reduces effect of noise onto wires, provides stability | less accurate readings | 8 | unstable mounting | 9 | Capacitors, and RC filters. | 5 | 360 | Talk with johnny to see how mechanicals manages this issue
 |  |  |  |  |  |  |  |  | 0
Buck convertor | Steps voltage down to 5.5V for energy efficiency, and to manage heat dissipation | Significant EMI can be generated | Cross talk between Analog traces | 3 | poorly routed traces | 4 | Lots of capacitors, amplifier board | 7 | 84
Buck convertor | wired incorrectly or soldered incorrectly | Does not properly regulate voltage | No voltage goes through to output | 10 | design mistake, poor soldering | 7 | 0 ohm resistor to bypass buck, test point | 2 | 140 | read datasheet in more detail to determine more options

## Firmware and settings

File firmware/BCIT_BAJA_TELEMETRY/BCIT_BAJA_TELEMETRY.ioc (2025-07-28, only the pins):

Mcu.UserName=STM32L476RGTx
PA0.Signal=ADCx_IN5
PA1.Signal=ADCx_IN6
PA2.GPIO_Label=USART_TX
PA2.Signal=USART2_TX
PA3.GPIO_Label=USART_RX
PA3.Signal=USART2_RX
PA5.Signal=ADCx_IN10
PA6.Signal=GPIO_Analog
PA7.Signal=ADCx_IN12
PA8.Signal=GPXTI8
PA9.Signal=GPIO_Output
PB0.Signal=GPIO_Output
PB1.Signal=ADCx_IN16
PB10.Signal=GPIO_Output
PB6.Signal=GPXTI6
PB7.Signal=GPIO_Output
PC0.Signal=ADCx_IN1
PC1.Signal=ADCx_IN2
PC11.Signal=GPIO_Output
PC12.Signal=GPIO_Output
PC13.GPIO_Label=B1 [Blue PushButton]
PC13.Signal=GPXTI13
PC4.Signal=ADCx_IN13
PC5.Signal=ADCx_IN14
PC6.GPIO_Label=strainEN
PC6.Signal=GPIO_Output
PC7.Signal=GPIO_Analog
PC9.GPIO_Label=V_batt_en
PC9.Signal=GPIO_Output

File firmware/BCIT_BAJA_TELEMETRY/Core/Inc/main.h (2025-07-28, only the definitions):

#define B1_Pin GPIO_PIN_13
#define B1_GPIO_Port GPIOC
#define USART_TX_Pin GPIO_PIN_2
#define USART_TX_GPIO_Port GPIOA
#define USART_RX_Pin GPIO_PIN_3
#define USART_RX_GPIO_Port GPIOA
#define strainEN_Pin GPIO_PIN_6
#define strainEN_GPIO_Port GPIOC
#define V_batt_en_Pin GPIO_PIN_9
#define V_batt_en_GPIO_Port GPIOC
#define TMS_Pin GPIO_PIN_13
#define TMS_GPIO_Port GPIOA
#define TCK_Pin GPIO_PIN_14
#define TCK_GPIO_Port GPIOA
#define SWO_Pin GPIO_PIN_3
#define SWO_GPIO_Port GPIOB

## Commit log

2025-03-01 idea of how strain gauge interacts with MCU added. Not enough data to perform calculations
    [strainGaugeBCIT_BAJA.kicad_sch]
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2025-03-11 ALL BOM components have been added with manufacturing part nunmber, alongside distributor link
    [BLE_HDWR_DESIGN.csv, bajaSensorPCB.csv, peripherals.kicad_sch]
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2025-03-12 wired, and selected capacitors. Not sure if they are correct as there was nothing in datasheet for it
    [peripherals.kicad_sch, power-supply.kicad_sch]
2025-03-12 gyroscope components wired and added. Pullup resistors may conflict with the other 3.3K pullup
    [ICM-45605.step, LGA14_2P5X3X0P91_IVS.step, peripherals.kicad_sch]
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2025-03-16 . Added NUCLEO reference schematics . Cleaned, renamed schematic pins for clarity . Fixed PMOS polarity bug . Added PMOS for switching StrainV . Added capacitors to AIN, StrainV . Cleaned git reposit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
    [Connectors.SchDoc, Connectors.kicad_sch, MB1136.PcbDoc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]
2025-03-16 Both mosfet will not be added into circuit. Both IMU and ANTENNA have sleep mode, which is in the micro to milliamp current usage range. Add in capacitor will optimize the system slighty, however the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
    Capacitor. Placement of capacitor is not accross differential. But we need 1 cap for each AIN, in addition to this, our switching frequency
    will be varied significantly due to our battery range. This is very complicated stuff to size for. So in terms of time, it may be best to not add this in.
    [Top.kicad_sch, pcb-stm32wl_bajaSensors.kicad_sch, peripherals.kicad_sch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]
2025-03-16 Both mosfet will not be added into circuit. Both IMU and ANTENNA have sleep mode, which is in the micro to milliamp current usage range. Add in capacitor will optimize the system slighty, however the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
    to size for capcitor, we need to know oscillations of buck converter(which is complicated) and is already filtered at output of buck converter. So, I will avoid adding in this.
    [pcb-stm32wl_bajaSensors.kicad_sch]
2025-03-18 . Re-imported NUCLEO_L476RG/BoardDesign/* files using KiCad 9.0.0 one at a time (to avoid a bug evident in misconnections in MCU_64), copied the schematic contents into local kicad_sch files with the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
    [Connectors.kicad_sch, MCU_64.kicad_sch, NUCLEO-L476RG_Connectors.kicad_sch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]
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2025-03-19 added colour scheme for notes. Parry: Orange, Daniel: Green
    Did PMOS calculation check.
    Results: Current mosfets unable to switch 3.3V load if we are using them.
    Calculations can be found in the Applications sheet
    [Revision01.kicad_sch, Revision01_Application.kicad_sch]
2025-03-20 redid mosfet calculations, 3.3V switching load should be fine calculations in application sheet
    [Revision01.kicad_pcb, Revision01_Application.kicad_sch]
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2025-03-22 Mainly verified and fixed peripheral component selection MOSFET-WIREOUT - DONE ANTENNA WIRE-OUT - DONE ADC WIRE-OUT - DONE - found error in ADC wireout, EP was left unconnected - notes on pins I foun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
    CHECK COMPONENT SELECTION ON
    MOSFET - Done
    Need to pick 100K component and 33K components - Done
    ADC - Done
    ANTENNA - Done
    IMU - done
    ADD POWER SWITCH WITH INTEGRATED LED <--- finished
    ADD SERIES AND PULL-UP RESISTORS TO SPI-BUS <--- finished
    Picked power switch with integrated LED
    Picked 10K SPI pullups, and 50Ohm series resistors
    [NUCLEO-L476RG_Connectors.kicad_sch, NUCLEO-L476RG_MCU_64.kicad_sch, NUCLEO-L476RG_Top.kicad_sch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]
2025-03-22 . Added local pin labels, ground, and VIN connections for Controller headers. Digital side TODO
    [NUCLEO-L476RG_Connectors.kicad_sch, NUCLEO-L476RG_MCU_64.kicad_sch, NUCLEO-L476RG_Top.kicad_sch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]
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2025-03-23 . Fixed MCU sheet pins neglecting Button1, Button2, and LED2.
    [Revision01.kicad_sch, Revision01_Controller.kicad_sch]
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2025-03-23 footprint added for nucleo board
    To do before PCB LAYOUT
    clean up schematic
    wire-accross sheets
    Improve annotation ordering
    Perform ERC check
    Ensure all components have footprints
    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
    [Revision01.kicad_sch]
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2025-03-25 neated up the circuit - done wire-accross sheets - done Ensure all components have footprints - done Create net classes - DONE POWER GND SPI GPIO
    Add in new components into BOM
    - Power switch, exclude from BOM - DONE - added component to switch. Not sure how to get it to work
    - Add in the resistors in parallel and series. for SPI busses - Done(PENDING whether to take series resistors out)
    [NUCLEO-L476RG_Connectors.kicad_sch, NUCLEO-L476RG_MCU_64.kicad_sch, NUCLEO-L476RG_Top.kicad_sch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]
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2025-03-27 CREATE STM32CUBEIDE file to verify all ports Check over CONTROLLER SHEET Improve annotation ordering Move testpoints out of controller sheet
    Still performering ERC check
    [NUCLEO-L476RG_Connectors.kicad_sch, NUCLEO-L476RG_MCU_64.kicad_sch, NUCLEO-L476RG_Top.kicad_sch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]
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2025-03-28 Revert "Added new LDO to fit into new battery range."
    This reverts commit 21f4e87803df2792b52a778a93d7df1213cd7c9c.
2025-03-28 Added new LDO to fit into battery range that feeds into MCU, make sure to remove power jumper wire before connecting. Completed ERC check
    Still have to put on footprints for some components when doing PCB layout
    [Revision01.kicad_sch, Revision01_Application.kicad_sch, Revision01_Controller.kicad_sch]
2025-03-28 missed connection for 5V to buck convertor on MCU
    [Revision01_Controller.kicad_sch]
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2025-03-31 added netclasses again changed power to be globally used strain gauges symbol created and added to schematic
    [NCP1117LPST50T3G.step, Revision01.kicad_pcb, Revision01.kicad_sch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]
2025-04-09 added 0ohm resistor to power STRAIN GAUGE. Need to re-read ADC to ensure reference is able to read negative voltage, as well as is capable of reading strain gauge
    [Revision01.kicad_sch, Revision01_Application.kicad_sch]
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2025-04-26 wired REFIN-, REFIN+ wired internal lowside ADC PS Changed VCC_STRAIN_GAUGE from 5V -> 3.3V to ensure the measured voltages are within 0-3.3V
    [Revision01_Application.kicad_sch]
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2025-04-27 added new battery measurement circuit which uses load switches onto schematic and changed headers to screw terminals
    [Revision01.kicad_sch, Revision01_Application.kicad_sch]
2025-04-30 Reworked Controller sheet to nucleo L476RG
    [Revision01.kicad_sch, Revision01_Application.kicad_sch, Revision01_Controller.kicad_sch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]
2025-04-30 ADDED 25pF to STRAIN GAUGES to remove noise ADDED FOOTPRINTS TO COMPONENTS Changed PS back to external-highside switch as internal mosfet current rating is too low pull-up for PMOS strainV_enable add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
    [Revision01.kicad_pcb, Revision01.kicad_sch, Revision01_Application.kicad_sch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]
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2025-05-03 feat(pcb layout)- grouped components by function in general area they will be placed in
    [Revision01.kicad_pcb, Revision01_Application.kicad_sch]
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2025-05-08 fixed some ERC errors related to JUMPERS
    [Revision01.kicad_pcb, Revision01.kicad_sch]
2025-05-09 created rainbows! fixed some wiring errors Began component layout( capacitors are huge compared to adc which is only part not layed out) Created board stackup thickness, materials, ect Defined minimu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
    [Revision01.kicad_pcb, Revision01.kicad_sch, Revision01_Application.kicad_sch]
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2025-05-14 some feedback implemented, MISO/MOSI SIWTCHED, GPIO_USB_5V FIXED, COMMENTS REGARDING ALTERNATIVE ADC's, and PCB CONNECTED TO EXTERNAL GND added
    [Revision01.kicad_pcb, Revision01.kicad_sch, Revision01_Application.kicad_sch]
2025-05-16 Implemented new more reliable design utilizing instrumentation amplifiers
    Changed RESISTORS for new Power requirements
    Added prototype features of breathing cube to test out.
    Removed MCU sheet, as moving pins around was getting too messy
    Picked out Instrumentation OP-AMP, INA331 or INA2331
    [691137710003.step, DSD0008B.stp, OSFW4BS8C1A.step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]
2025-05-16 Finished up small things(on schematic layout)
    -Connector pins switched such that GND is pin 1
    -used KICAD feature to indicate ACTIVE LOW
    -polyFuse added to each StrainGauge
    -Added Grounded Mounting holes connects to external GND(outside of PCB)
    [Revision01.kicad_sch, Revision01_Application.kicad_sch]
2025-05-17 I believe I have finished schematic
    -Calculated RC circuit with cutoff at 10KHz for ADC
    - Stimulated OP-AMP circuit with strainGauge
    [Revision01.kicad_pcb, Revision01.kicad_sch, Revision01_Application.kicad_sch]
2025-05-19 schematic wiring, and LT-SPICE simulations on strain gauge - Added buffer with offset at 1.66V to instrumentation amplifier to ensure -20-20mv range can be read - Added caps to Instrumentation Amplif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
    [BOM1.csv, Revision01.kicad_pcb, Revision01.kicad_sch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]
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2025-05-22 Schematic small details, and beginning wiring
    Placed capacitors( in correct polarity)
    Branch fuses should be put on the branches(sensor Amplifiers) - as they protect branches
    Added Main fuse(protecting main circuit - from connector)
    Changed all component sizes back to 0805 atleast
    Started PCB WIRING
    [Revision01.kicad_pcb, Revision01.kicad_sch, Revision01_Application.kicad_sch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]
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2025-05-29 stimulated over/undervoltage protection and started correcting error
    [Revision01.kicad_pcb, Revision01.kicad_sch, Revision01_Application.kicad_sch]
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2025-06-16 attempting to fix software bug
    [Revision01_Application.kicad_sch]
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2025-06-24 PART B- size reduced to enhance mechanical stability, PART A - changed antenna due to being out of stock
    [IND_LQH44PN_PR_MUR.step, Revision01-Parry.kicad_sch, Revision01.kicad_pcb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]
2025-06-25 fixed antenna footprint issue, moved primary fuse upstream before switch, reduced number of 0 ohm resistors needed for switching between PS
    [Revision01.kicad_pcb, Revision01.kicad_sch, Revision01_Application.kicad_sch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]
2025-06-25 antenna connections are flipped, fixed
    [Revision01.kicad_pcb, Revision01.kicad_sch, Revision01_Application.kicad_sch]
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2025-06-28 review 2 implemented
    - Made mounting holes symmetrical
    - Buck enable 0 ohm resistor error fixed
    [Revision01-DESKTOP-HRPABPU.kicad_pcb, Revision01.kicad_pcb, Revision01.kicad_sch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]
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2025-07-05 Fixed minor ERC Errors.
    [Revision01.kicad_sch, Revision01_Application.kicad_sch]
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2025-07-06 Excluded 1 Warning: Symbol 'SW_SPST_LED' doesn't match copy in library 'Switch' Fixed 3 Warnings: Symbol 'R_Small' doesn't match copy in library 'Device'
    [Revision01.kicad_sch]
2025-07-06 ERC Warning Count: 31
    Fixed 1 Warning: Symbol U1: Symbol 'NUCLEO-L476RG' doesn't match copy in library 'NUCLEO-L476RG'
    Fixed 3 Warnings: STM local net label & global net label mismatches:
    "Both +5V and +5V_NUCLEO are attached to the same items; +5V will be used in the netlist"
    [Revision01.kicad_sch]
2025-07-06 ERC Warnings: 21
    - Replaced 8x Strain Gauge JST Connector footprints with 2x3 2.54mm Odd/Event 6-Pin IDC.
    The case connectors are 6 pin (inner) Male -> Female -> Male (outer)
    [Revision01_Application.kicad_sch]
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2025-07-06 ERC Warnings: 7
    . Fixed incorrect AIN_STRAIN_1..8 "Input" setting. They are outputs according to the application module.
    . Reworked strain gauge schematic to flow from left to right, removing unnecessary and error-prone local net names.
    [Revision01.kicad_sch, Revision01_Application.kicad_sch]
2025-07-06 ERC Warnings: 7
    . Reworked Power section to flow from left to right.
    . Separated the Power switch connector from the external SPST + LED component.
    . Changed most NOT POPULATED external flags to Excluded from Simulation only. It gives a nice visual gray without exclusion from BOM.
    [Revision01.kicad_sch, Revision01_Application.kicad_sch]
2025-07-07 Reworked NUCLEO-L476RG schematic symbols to include important pin functions.
    [Revision01.kicad_sch, Revision01_Application.kicad_sch, nucleo_L476RG_pinout_matrix.ods]
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2025-07-07 ERC Warnings: 6
    . Fixed 100uF capacitor upstream of PMOS Switch
    . Fixed MPU-6500 floating pins
    . Fixed STM PA2, PA3 USART2 AIN overlap bug
    . Added ANT_Enable pin
    . Created Adafruit 3070 symbol, added SMA & Antenna component symbols.
    [Revision01.kicad_sch, Revision01_Application.kicad_sch]
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2025-07-08 Normalized Symbol Fields.
    . Populated symbol fields with Detailed Description, Distributor Link, Distributor Part Number, Manufacturer, Manufacturer Part Number, Package / Case
    . Replaced all resistors with Vishay, capacitors with Samsung components.
    . Chose 22uF capacitor for the +5V strain gauge power MOSFET
    [Revision01.kicad_sch, Revision01_Application.kicad_sch]
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2025-07-09 . Changed to 1-shot fast-blow fuses to replace erroneous main PTC fuse, strain fuses. . Added BOM entry for BF350 strain gauges from aliexpress
    [Revision01.kicad_sch, Revision01_Application.kicad_sch]
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2025-07-13 Improved documentation on LTSPICE schematics - Created WORD document containing documentation on all LTSPICE stimulations - Changed strainPower mosfet to NMOS <- subject to change - Redid clamping di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
    Having issues integrating amplifier schematic with clamping diode schematic.
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2025-07-14 - Redo buck converter calculations - Maybe stimulate it. - Choose components for RC mosfet circuit - Verify MOSFET calculations - tried and changed PMOS type - Check fuse selection. Accounting for BU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
    [Revision01.kicad_sch, Revision01_Application.kicad_sch, StrainAmplifierV1.kicad_pcb]
2025-07-16 Documentation files on LTSPICE stimulations, as well as RC FILTER created
    LTSPICE stimulations
    ALL circuits restimulated, documented in test folder
    RC FILTER calculations which filters out a lot of noise concerns.
    [Revision01.kicad_sch, Revision01_Application.kicad_sch, StrainAmplifierV1.kicad_sch]
2025-07-16 some files were missed last commit
    [Revision01_Application.kicad_sch]
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2025-07-28 . Ensured interrupts were not overlapping by renaming PB4_GPIO to PB4_GPInterrupt . Checked PC6 for 5V tolerance (FT) . Fixed ERC errors for unconnected pins.
    [Revision01.kicad_sch, Revision01_Application.kicad_sch]
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2025-07-30 . Added Adamtech male 6 pin IDC connector footprint & 3D Model, revealing critical overlapping problem on fuses. . Added NUCLEO additional plated holes to fit USB debugging GND connections. . Placed 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
    [Revision01.kicad_pcb, Revision01.kicad_sch, Revision01_Application.kicad_sch]
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2025-08-01 . Repositioned antenna close to USB for space considerations . Repositioned connectors, headers, testpoints, buck, switch, etc. . Fixed Adafruit Pad 15 Error . Fixed MPU-6500 missing Pad Warnings/Err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
    [Revision01.kicad_pcb, Revision01.kicad_sch, Revision01_Application.kicad_sch]
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2025-08-04 . Fixed DRC Violations
    [Revision01.kicad_pcb]
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2025-08-05 . Placed vias. . Added bypass capacitor to BatteryV measurement circuit. . Fixed prior git incomplete checkins by adding custom footprints.
    [Revision01.kicad_pcb, Revision01.kicad_sch, Revision01_Application.kicad_sch]
2025-08-07 . Completed KiCad track wiring. DRC Errors: 0 DRC Warnings: 55
    [Revision01.kicad_pcb, Revision01.kicad_sch, Revision01_Application.kicad_sch]

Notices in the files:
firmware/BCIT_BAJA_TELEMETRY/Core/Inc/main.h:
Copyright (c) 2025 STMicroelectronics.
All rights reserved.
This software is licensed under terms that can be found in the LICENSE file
